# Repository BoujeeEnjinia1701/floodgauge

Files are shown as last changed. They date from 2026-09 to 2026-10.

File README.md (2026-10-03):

# FloodGauge

     

**Area:** Smart Cities · **TRL:** 3 of 9 (proof of concept on paper) · **Value-engineering target:** USD 160 for FloodGauge-specific parts; estimated cost of the constructable design USD 205.50 (FieldNode costed separately) · **Difficulty:** 2 of 5

A street and drain water level sensor using ultrasonic or radar ranging that publishes levels to a city's alert service, so crews and residents can be warned when drains back up or streets begin to flood.

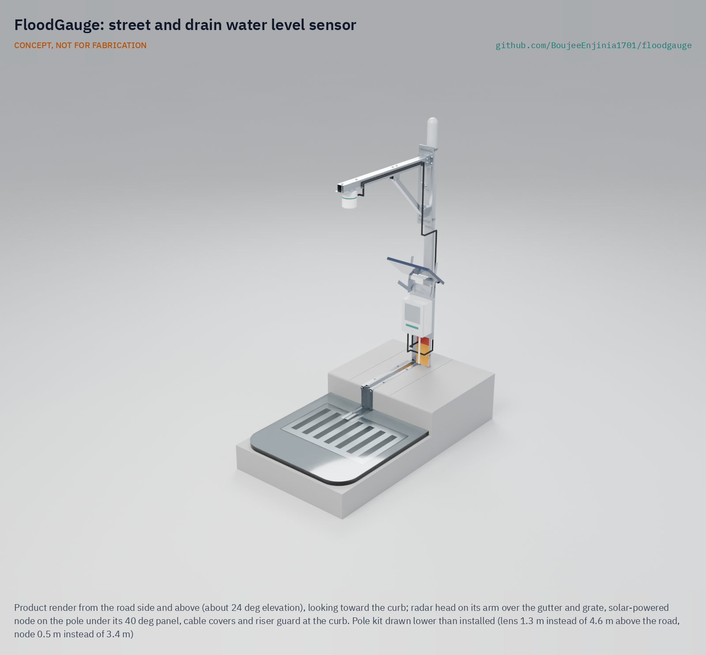
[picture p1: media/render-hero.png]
FloodGauge: street and drain water level sensor, product render


[Exploded render](media/render-exploded.png) · [Detail render](media/render-detail.png) · [Interactive 3D model](media/viewer.html) · [Concept blueprint (PDF)](media/concept-blueprint.pdf) · [General arrangement (PDF)](cad/drawings/FLG-DWG-001.pdf) · [Calculations](docs/04-calcs/01-sizing.md) · [Prototype build plan](docs/05-build-plan.md) · [Design decisions](docs/06-design-decisions.md) · [Review note](docs/REVIEW.md)

## Concept rationale

Street-level readings give minutes of warning where river gauges give none. Streets flood in two ways: the drain fills and backs up through the grate, or the grate is blocked and water ponds above an empty drain. FloodGauge watches both from one pole. A radar head on a short arm over the gutter measures water depth on the street, and an ultrasonic head in a stilling tube inside the catch basin sees the drain filling first. The lab's FieldNode core supplies the enclosure, solar power and LoRaWAN radio, so this project adds only the heads, the mounting and the alert logic.

Keeping it open and garage-buildable lets a city, a university or a neighborhood group build, inspect and repair its own gauges and own its data. The parts are off the shelf or cut with hand tools, the designs are under CERN-OHL-S-2.0 and the software under MIT, and the gauge sends water levels only: no camera, no microphone.

## Burning platform

About 1.81 billion people, 23 % of the world's population, are directly exposed to 1-in-100-year floods, and 89 % of them live in low- and middle-income countries ([Rentschler, Salhab and Jafino, 2022](https://www.nature.com/articles/s41467-022-30727-4)). Only 108 countries, 55 % of the total, reported multi-hazard early warning systems in 2024, and countries with limited coverage had disaster mortality nearly six times higher than those with substantial coverage ([UNDRR and WMO, 2024](https://www.undrr.org/reports/global-status-MHEWS-2024)).

Depths that look harmless kill. The US National Weather Service warns that 150 mm (6 in) of fast-moving water can knock over an adult and 300 mm (12 in) can carry away most cars, and that over half of flood drownings happen when a vehicle is driven into flood water ([NWS](https://www.weather.gov/safety/flood-turn-around-dont-drown)). Those depths build up on a street in minutes, well before a river gauge downstream responds.

## Where it could be used

### By industry

| Industry | Use |
| --- | --- |
| Municipal drainage and public works | Find blocked or surcharging inlets during a storm and send crews to the right street |
| Emergency management | Street depth and rate of rise to close underpasses and warn basement residents |
| Road and transit operators | Flooding alerts at underpasses, bus stops and depot entrances |
| Property and campus management | Early warning for car parks, loading docks and basement entrances |
| Insurance and resilience planning | An open record of where and how often streets flood |
| Research and education | Open, repeatable urban hydrology data for universities and schools |

### By country or region

| Country or region | Why it matters there |
| --- | --- |
| United States | Over half of flood drownings involve vehicles driven into water ([NWS](https://www.weather.gov/safety/flood-turn-around-dont-drown)); New York City's FloodNet reached 250 street sensors in 2024 ([FloodNet](https://www.floodnet.nyc/about)), showing demand for street-level data. |
| Netherlands | The highest share of population in flood zones worldwide, 58.7 % ([Rentschler et al., 2022](https://www.nature.com/articles/s41467-022-30727-4)); dense cities need drain-level data as well as dikes. |
| Germany and Belgium | The July 2021 floods caused more than 200 deaths after record rainfall ([Copernicus, 2021](https://climate.copernicus.eu/esotc/2021/flooding-july)). |
| India and China | Together about 785 million flood-exposed people, over one third of the global total ([Rentschler et al., 2022](https://www.nature.com/articles/s41467-022-30727-4)), many in fast-growing cities. |
| Vietnam | 46 % of the population lives in flood zones, the highest share among developing countries ([Rentschler et al., 2022](https://www.nature.com/articles/s41467-022-30727-4)). |
| Sub-Saharan Africa | 44 % of the 170 million people facing both high flood risk and extreme poverty live here ([Rentschler et al., 2022](https://www.nature.com/articles/s41467-022-30727-4)); low-cost open gauges suit city budgets. |

## What sparked the idea

The idea traces back to the night of September 1, 2021, when the remnants of Hurricane Ida hit New York City. The city's sewers are designed to carry 44 mm (1.75 in) of rain an hour, and Ida brought more than two hours above that rate ([NYC Comptroller, 2024](https://comptroller.nyc.gov/reports/is-new-york-city-ready-for-rain/)). Drains backed up into streets and basements. Of the 14 injury deaths in the city, 10 were drownings in basement apartments, and the deaths for which a time is known came before the state of emergency was declared, and that declaration carried no basement-specific advice ([Yuan et al., 2024](https://www.cambridge.org/core/journals/disaster-medicine-and-public-health-preparedness/article/immediate-injury-deaths-related-to-the-remnants-from-hurricane-ida-i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)). The warning that mattered on that street was the drain filling and the water rising at the curb, and that is what FloodGauge measures.

## Problem

Urban flash floods rise in minutes, and warnings rely on river gauges far from the streets that flood.

## Concept

A street and drain water level sensor using ultrasonic or radar ranging that publishes levels to a city's alert service, so crews and residents can be warned when drains back up or streets begin to flood.

Full design precis: [docs/02-concept.md](docs/02-concept.md)

## Key components

- FieldNode core (enclosure, 6 W solar panel, LiFePO4 cell, LoRaWAN radio), shared with other lab projects
- Street head: 60 GHz radar on a short braced arm over the gutter, lens 2.5 to 5.0 m above the road as the site's clearance rule requires (4.6 m in the reference design), on a pole bracket with two V-blocks, two band clamps and an anti-rotation through-bolt
- Drain head: waterproof ultrasonic ranger with wet probe and temperature sensor, in a slotted 75 mm stilling tube inside the catch basin
- Surface cable route for pilots under three bolted steel covers and a riser guard (conduit at permanent sites), depth marker plate with 150 mm and 300 mm bands
- Open alert service on a LoRaWAN gateway such as TwinKit

TRL 3 calculations ([FLG-CAL-001](docs/04-calcs/01-sizing.md)) on the constructable design: alert latency 82 s at the 95th percentile (110 s worst case), street depth error ±6.5 mm with radar, drain level error ±11 mm, under 10 mW of sensor load and 4.99 kg on the pole. Value-engineering target: USD 160. Estimated cost of the constructable design: USD 205.50 for FloodGauge-specific parts (USD 45.50 over the target); USD 344.50 with the USD 139 FieldNode core. No requirement is not met; installation takes 120 min on the pilot surface route, which is the target Amish set for it. See the [design precis](docs/02-concept.md) and [requirements](docs/03-requirements.md). The design choices were decided by Amish on 2026-09-25 ([FLG-DDR-001](docs/decisions/0001-trl2-review-decisions.md), [FLG-DDR-002](docs/decisions/0002-recommendations-accepted.md)); the changes that make the design buildable are in [FLG-DDR-003](docs/decisions/0003-design-for-construction.md), accepted by Amish on 2026-10-02.

The working bill of materials is in [bom/bom.csv](bom/bom.csv).

## Building the prototype

The [prototype build plan](docs/05-build-plan.md) (FLG-BLD-001) shows how to make and fit every component, in order, with a making sketch for each made part, close-ups of the joints and a picture for every assembly step. Sixteen parts are made in a small workshop from aluminium plate, bar, angle and tube, folded galvanized strip and slotted PVC pipe; the rest are bought or built to the FieldNode plan. The design was checked for construction on the model (110 checks), which changed the arm mounting, the brace, the cable covers and the drain head fixing ([FLG-DDR-003](docs/decisions/0003-design-for-construction.md)). Decisions still open are in the [design decisions register](docs/06-design-decisions.md). It is a plan, not yet built.

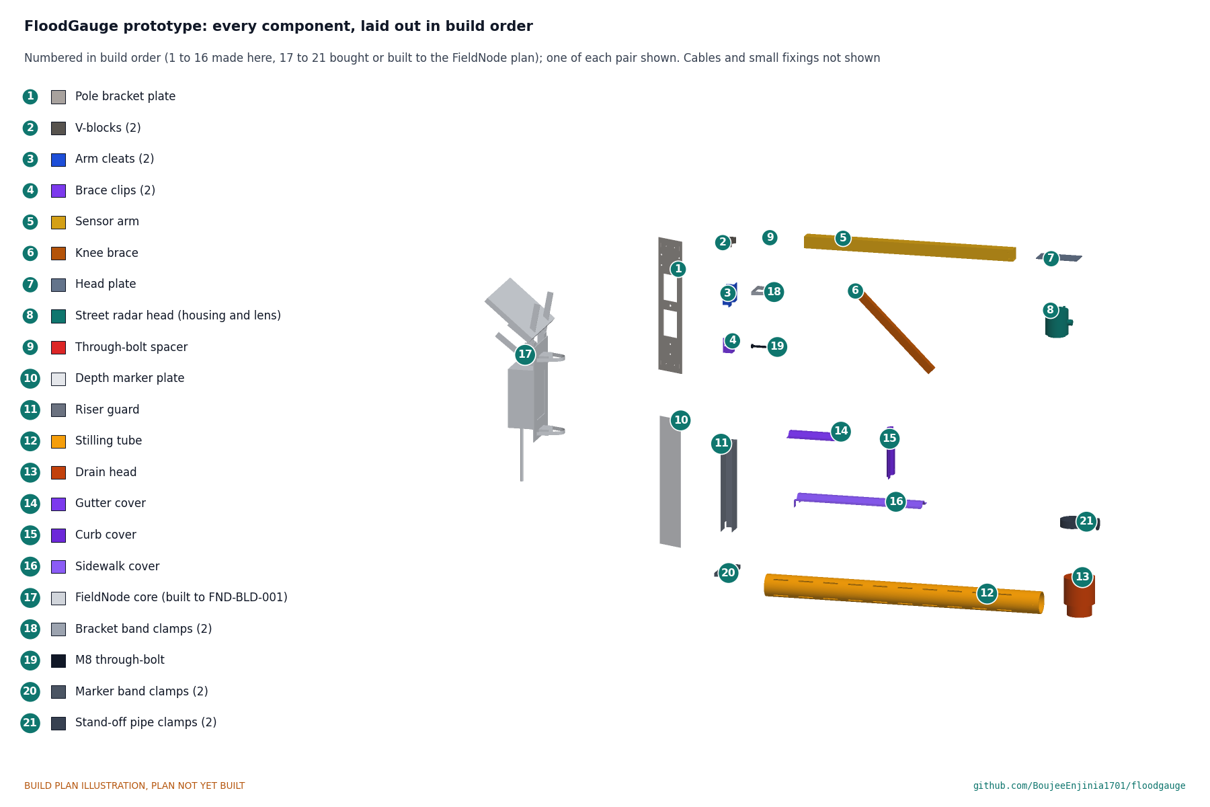
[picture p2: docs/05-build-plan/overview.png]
FloodGauge prototype: every component, laid out in build order


## Safety

> Install only with traffic and confined space precautions. Street furniture and pole mounts must be installed only with the asset owner's permission, by trained crews, with fall protection and traffic management as local rules require.
>
> Never enter a catch basin: it can hold toxic or oxygen-poor air and fast-rising water. Stormwater carries sewage and chemicals; wear gloves and eye protection. The FieldNode LiFePO4 cell must be fused and charged only between 0 and 45 °C.
>
> An arm over the gutter must clear tall vehicles at the curb; mount it at the height the road authority requires (4.6 m in the reference design), from a mobile elevating platform, and always fit the anti-rotation bolt. Keep the surface cable cover low, beveled and marked so it is not a trip hazard.
>
> FloodGauge supplements official flood warnings and must never be the only warning people rely on.

## Repository layout

| Folder | Contents |
| --- | --- |
| `docs/` | Problem, concept, requirements, calculations and design decisions |
| `cad/src/` | build123d Python source, the source of truth for all geometry |
| `cad/step/`, `cad/stl/` | Exported models for FreeCAD, other CAD tools and printing |
| `cad/drawings/` | 2D sketches and dimensioned drawings |
| `bom/` | Bill of materials |
| `electronics/` | KiCad schematics and PCB layouts |
| `firmware/` | Microcontroller code |
| `media/` | Renders, perspectives and photos |
| `build-log/` | Dated prototyping notes |

## Documentation

Controlled documents follow the portfolio [documentation standard](.kit/STANDARDS.md). Each carries a document ID (FLG-PRC-001 for the precis), a version and a revision history. Branded PDFs are built with `python .kit/render.py` and attached to GitHub Releases when a document is tagged, for example `FLG-PRC-001/v1.0`.

## Credits

Designed by Amish Chadha. See [CONTRIBUTORS.md](CONTRIBUTORS.md) for roles. To cite this design, use [CITATION.cff](CITATION.cff) (GitHub shows it as "Cite this repository").

AI assistance (Claude) was used to accelerate concept renders, prototype documentation and first-pass sizing calculations. Design direction and all decisions are Amish Chadha's, recorded in this repository's decision records (`docs/decisions/`).

## Licenses

- **Hardware** (CAD, drawings, BOM, electronics): [CERN-OHL-S v2](LICENSE)
- **Software** (firmware, scripts, notebooks): [MIT](LICENSE-SOFTWARE)

A project of the [Design Molecule](https://designmolecule.com) lab.

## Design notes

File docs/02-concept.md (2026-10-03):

---
doc_id: FLG-PRC-001
title: FloodGauge design precis
project: FloodGauge
doc_type: Design precis
version: "0.8"
status: Draft
date: '2026-10-02'
author: Amish Chadha
license: CERN-OHL-S-2.0
revisions:
- version: "0.1"
  date: '2026-09-25'
  author: Amish Chadha
  change: Initial scaffold
- version: "0.2"
  date: '2026-09-25'
  author: Amish Chadha
  change: Populate to TRL 2 (architecture, first-order numbers, safety, media)
- version: "0.3"
  date: '2026-09-25'
  author: Amish Chadha
  change: TRL 3 update; design choices adopted for TRL 3 pending Amish's review (FLG-DDR-001); numbers checked in FLG-CAL-001; parametric model and drawing FLG-DWG-001
- version: "0.4"
  date: '2026-09-25'
  author: Amish Chadha
  change: Recommendations accepted by Amish (DDR-002)
- version: "0.5"
  date: '2026-09-26'
  author: Amish Chadha
  change: Budget approved by Amish ($160)
- version: "0.6"
  date: '2026-10-01'
  author: Amish Chadha
  change: Constructable design (FLG-DDR-003); budget reported as a value-engineering target
- version: "0.7"
  date: '2026-10-02'
  author: Amish Chadha
  change: "Decisions of 2026-10-02: alert governance with the partner city, first alert band 100 mm, R12 met on paper for the pilot route, tamper-resistant fixings, first candidate partner type"
- version: "0.8"
  date: '2026-10-02'
  author: Amish Chadha
  change: "Cost USD 205.50 (USD 45.50 over the target) with tamper-resistant fixings; drain cable slack loop tied to the stilling tube clamp"
---

# FloodGauge design precis

## Summary

FloodGauge is a FieldNode core on an existing street pole next to a storm inlet, with two ranging heads: a 60 GHz radar head on a short arm over the gutter that measures water depth on the street, and an ultrasonic head in a slotted stilling tube inside the catch basin that sees the drain filling before the street floods. The node turns ranges into levels, raises its sampling rate when water rises, and sends levels only over LoRaWAN to the partner city's alert service, which decides who acts and warns crews and the residents who opt in, at default depths of 150 mm and 300 mm. FLG-CAL-001 v0.4 gives an alert latency of 82 s at the 95th percentile (110 s worst case), a sensor load under 10 mW and 4.99 kg on the pole. Value-engineering target: USD 160 (set by Amish on 2026-09-26). Estimated cost of the constructable design: USD 205.50 for FloodGauge-specific parts (USD 45.50 over the target); USD 344.50 with the USD 139.00 FieldNode core, which is costed in its own repo. One requirement is not met: installation takes 120 min against 90 min (R12). The design choices below were decided by Amish on 2026-09-25 (FLG-DDR-001 and FLG-DDR-002): the lens sits at 4.6 m to clear tall vehicles, pilots use a surface cable route under bolted steel covers, and an M8 through-bolt stops the arm turning. FLG-DDR-003 (2026-10-01, accepted by Amish on 2026-10-02) makes the design buildable: the arm sits in cleats on a pole bracket with V-blocks and band clamps, the brace is pinned in two clips, the FieldNode sits at 3.4 m, and the drain cable comes up through a grate opening under three hat-section covers. The build plan is FLG-BLD-001.

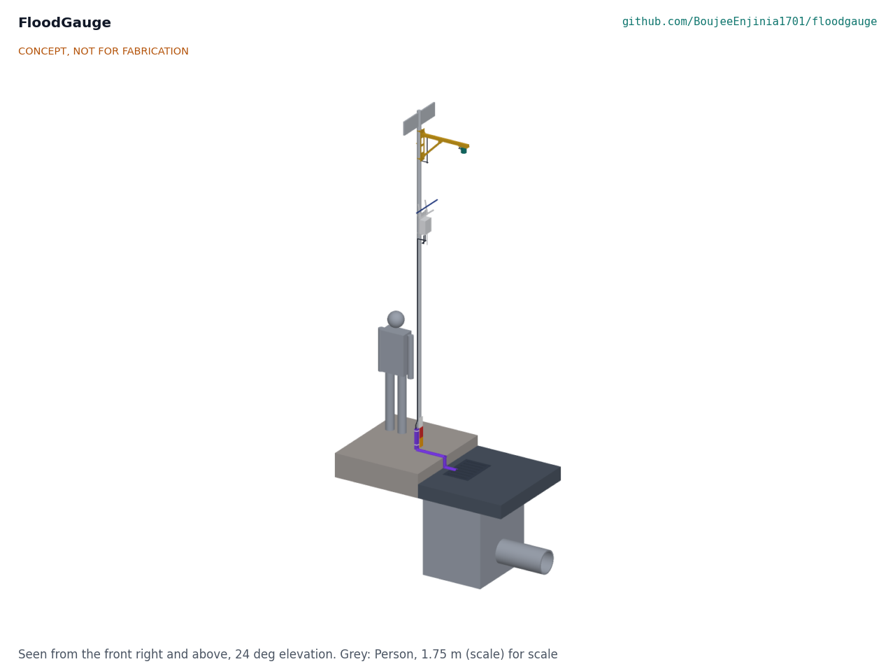
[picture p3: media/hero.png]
Hero render


Figure 1. Concept massing model beside a storm inlet, with a 1.75 m person for scale. CONCEPT, NOT FOR FABRICATION.

## How it works

1. **Range the street.** The street head (item 2) looks straight down at the gutter from 4.6 m, 250 mm past the curb face. The height is set per site within 2.5 to 5.0 m to the road authority's clearance rule; 4.6 m clears a 4.3 m vehicle at the curb with a 0.3 m margin. Water depth is the surveyed head height minus the measured range. The beam also lights the curb, so a dry-road background is recorded at installation and the firmware tracks the peak directly below the head (FLG-CAL-001, A2).
2. **Range the drain.** The drain head (item 4) sits at the top of a slotted 75 mm tube (item 5) fixed to the basin wall. Water in the tube follows the basin level (lag under 5 mm even at 50 mm/s), and the tube walls give the wide ultrasonic beam a clean path, so the head sees the water surface and not the basin walls. A wet probe on the head signals when the basin is full to the head, and an NTC in the head compensates the speed of sound.
3. **Decide on the node.** FieldNode (item 1), mounted 3.4 m above the road so that the street head's I2C cable stays within 3 m along its real route (FLG-DDR-003), samples both heads every 60 s. When either level rises faster than 20 mm/min or passes the first band, it samples every 10 s. It applies plausibility checks: a sudden 1 m "rise" on the street head with an empty drain is a parked vehicle or a person, not a flood.
4. **Report.** Normally one uplink every 15 min; in an event an uplink on each band crossing and then each minute. Payloads carry levels, rate of rise, battery and status only.
5. **Alert.** A gateway (TwinKit or a city LoRaWAN network) passes readings to an open alert service that sends crew notifications and opt-in resident messages and publishes open data.
6. **Check by eye.** A depth marker plate (item 8) with bands at 150 and 300 mm above the road lets residents and crews read depth directly and check the gauge. The alert service adds a first band at 100 mm unless the partner city's own practice says otherwise.

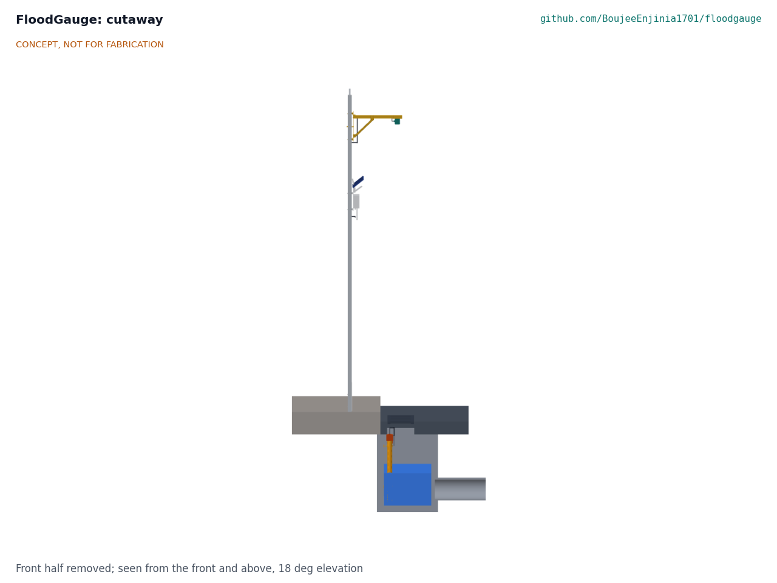
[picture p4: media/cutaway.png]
Cutaway


Figure 2. Section across the street through the inlet: street head over the gutter, stilling tube and drain head in the catch basin, surface cable cover to the pole. Water level is illustrative.

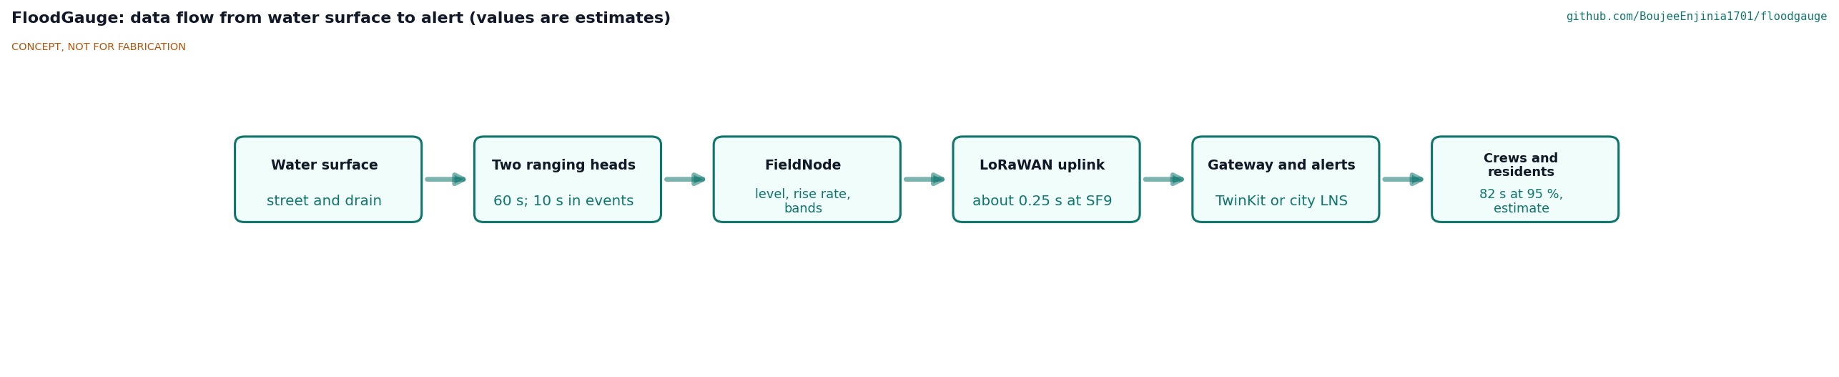
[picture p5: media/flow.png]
Data flow


Figure 3. Data flow from the water surface to an alert. Values are estimates or proposals.

## Main components

Table 1. Main components (numbers match the exploded view and `bom/bom.csv`)

| # | Component | Decided choice (FLG-DDR-001, FLG-DDR-002) | Notes |
| --- | --- | --- | --- |
| 1 | FieldNode core | Lab shared node: IP65 enclosure, 6 W panel as hood, 6 Ah LiFePO4 cell, MPPT board with 3.3, 5 and 12 V switched rails, STM32WL-class LoRaWAN, two M12 sensor ports | Built to FND-BLD-001; center 3.4 m above the road, facing the street; 2.45 kg and $139.00 |
| 2 | Street radar head | 60 GHz pulsed coherent radar module (Acconeer XM125 class) behind a PTFE lens in a sealed IP67 housing | D3; accuracy, current and price not yet checked against a data sheet |
| 3 | Sensor arm and pole bracket | 40 x 40 x 1.6 mm aluminium tube 715 mm in two angle cleats on a 3 mm pole bracket plate with two V-blocks and two band clamps 400 mm apart; 25 mm square knee brace at 45° pinned in two clips; head plate; M8 anti-rotation through-bolt across the street through the plate and the pole | Head 250 mm past the curb face over the gutter (D5); lens 4.6 m, per site 2.5 to 5.0 m (DDR-002) |
| 4 | Drain head | Waterproof ultrasonic ranger (A02YYUW: 3 to 450 cm, ±1 cm, IP67) with a two-electrode wet probe and an NTC, potted in a sealed cap | Face 300 mm below the road; the transducer face keeps its IP67 seal, so R9 is at risk |
| 5 | Stilling tube | 75 mm OD PVC, 940 mm long, 40 slots 5 x 50 mm, two stainless stand-off pipe clamps, mouth 60 mm above the basin floor; the drain head's socket slides over its top | Reachable from the surface with the grate lifted; the drain cable has a 0.5 m slack loop tied to the upper pipe clamp so it cannot catch debris |
| 6 | Sensor cables | Two outdoor cables with M12 5-pin plugs to the FieldNode ports: 3 m (street, I2C) and 5 m (drain) | Drip loops at every entry |
| 7 | Surface cable covers | Pilot route: up through the grate opening nearest the curb, under three bolted hat-section covers of 2 mm galvanized steel (gutter strip, curb face, sidewalk; 0.76 m in all) and up a riser guard strapped to the pole | Anchors in the curb and sidewalk only, with security (snake-eye) nuts; permanent sites use a 25 mm conduit laid with road works (DDR-002) |
| 8 | Depth marker plate | 2 mm aluminium plate from 165 mm above the road, amber band to 300 mm and red band 300 to 450 mm above road level, on two band clamps with pin-Torx security screws that also hold the riser guard | Visual check and resident information |
| 9 | Alert service | Open software on the gateway or a small server (not modeled) | Part of the software license (MIT) |

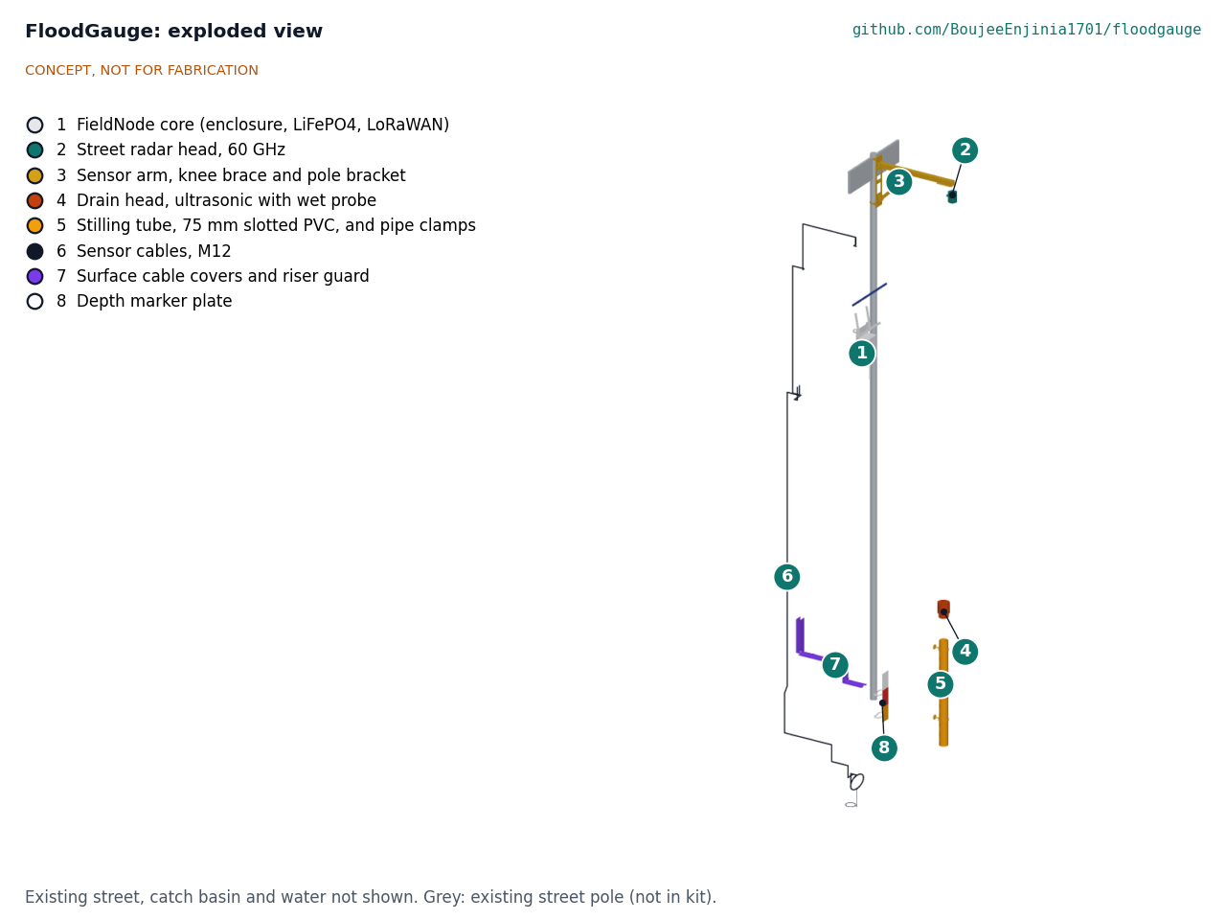
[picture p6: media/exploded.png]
Exploded view


Figure 4. Exploded view with BOM numbers. The existing street and basin are not shown.

## First-order numbers

The values below are from FLG-CAL-001 v0.4 and its script, on the constructable design of FLG-DDR-003.

Table 2. Key numbers at TRL 3

| Quantity | Value | Basis | Requirement |
| --- | --- | --- | --- |
| Street head range | 4.60 m to dry road, 4.00 m at 600 mm depth; 1.9 to 5.0 m over the R1 band | Lens 4.6 m above the road | R1 met on paper |
| Street depth error, radar | ±6.5 mm root sum square, ±12.0 mm worst-case sum | Module ±2 mm (assumed), datum ±5 mm, pole expansion ±2.0 mm, ripple ±3 mm | R2 met on paper |
| Street depth error, ultrasonic variant | +349 to -231 mm uncompensated over -20 to 50 °C; ±27.0 mm compensated | Speed of sound 331.3 + 0.606 T m/s | R2 not met by this variant |
| Drain level error | ±11.0 mm with the NTC, ±19.7 mm without | ±10 mm module ([DFRobot](https://www.dfrobot.com/product-1935.html)), 950 mm range | R4 met on paper |
| Drain reading range | 50 mm above the floor to 330 mm below the road; wet probe at 310 mm | Head face 300 mm below the road, 30 mm blind zone | R3 (restated) met on paper |
| Energy per sampling cycle | 85.1 mJ | Radar 59.4 mJ, ultrasonic 12.0 mJ, rails 90 %, controller 5.8 mJ | |
| Sensor load | 1.42 mW at 60 s; 9.3 mW with 10 s sampling and 1 min uplinks all day | 1,440 or 8,640 cycles a day | R8 met: 68 days without sun |
| Uplink airtime | 23.7 s/day normal at SF9; 14.8 s/h in an event | 246.8 ms per 20-byte uplink | R7 at risk at SF11 and SF12 |
| Alert latency | 82 s at the 95th percentile, 110 s worst case without a lost packet | Simulation of 200,000 events | R6 met on paper |
| Arm twist | Factor 37 with the M8 through-bolt; 1.45 on clamp friction alone | 35 m/s gust along the street | R15 met on paper |
| Installation | 120 min, surface only, no civil work | Task list in FLG-CAL-001, L1 | R12 met on paper (120 min for the pilot route) |
| Mass on the pole | 4.99 kg | FieldNode 2.45 kg plus arm, bracket, bolts, head, cables and marker (FLG-CAL-001 v0.4) | R15 met on paper (0.01 kg margin) |
| Parts cost | $205.50 FloodGauge-specific; $344.50 with FieldNode | `bom/bom.csv` | R16: value-engineering target USD 160; estimated cost of the constructable design USD 205.50 (USD 45.50 over the target) |

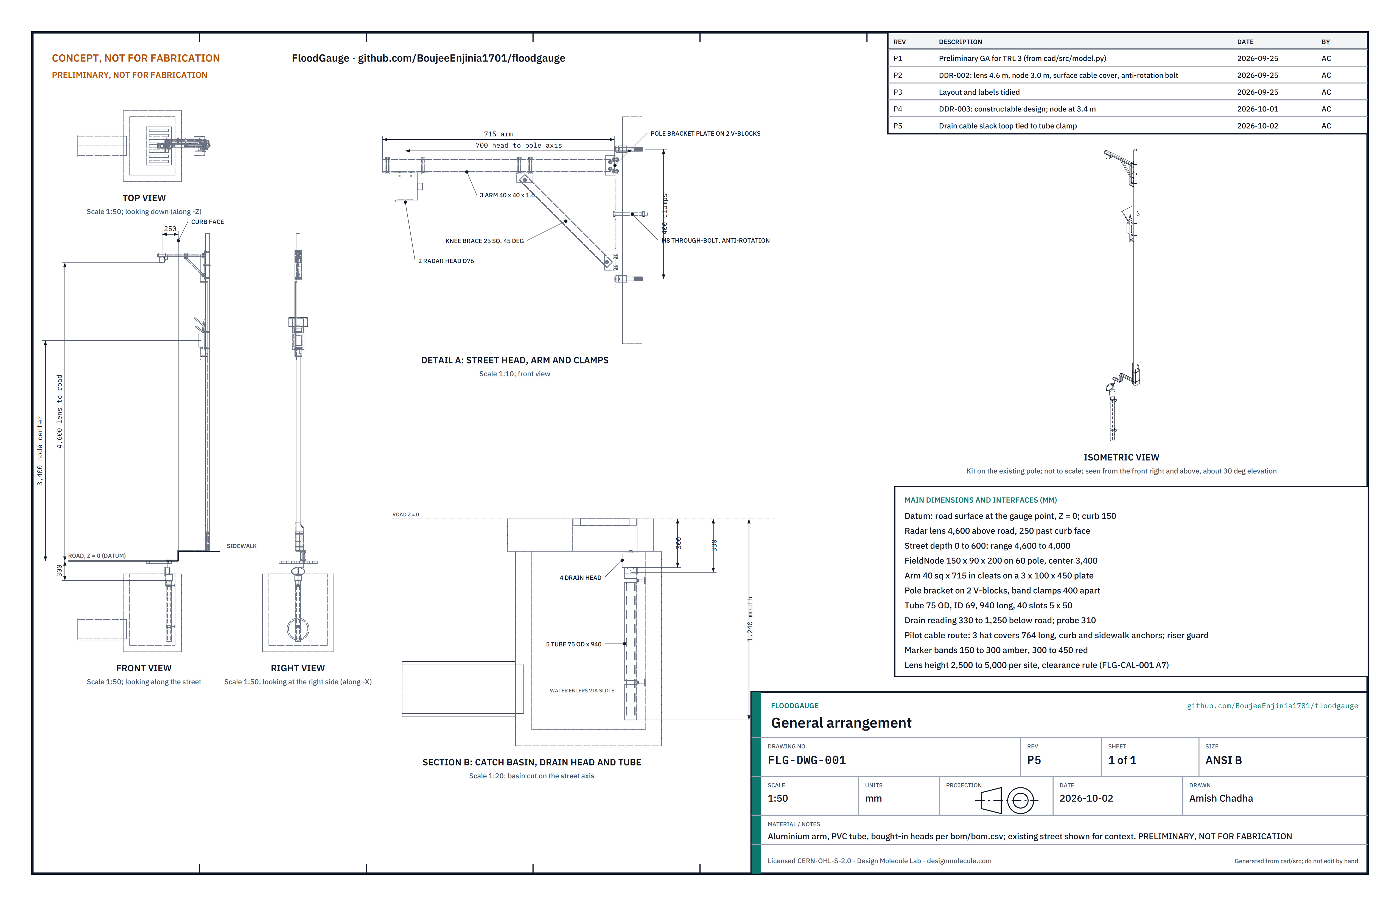
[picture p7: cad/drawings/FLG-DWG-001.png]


Figure 5. General arrangement FLG-DWG-001, Rev P4, from `cad/src/model.py`. PRELIMINARY, NOT FOR FABRICATION.

## Key design choices

Decided by Amish, 2026-09-25: go with recommendation (FLG-DDR-001, D1 to D9, and FLG-DDR-002, N1 to N5).

1. **Two heads on one node** (street and drain), because each head misses one of the two ways streets flood (FLG-PRB-001). Street head only remains the fallback where no cable route to the basin exists. (D2)
2. **Radar for the street head.** FLG-CAL-001 confirms that a compensated ultrasonic head misses R2 (±19.5 mm). The ultrasonic head stays documented as a lower-cost variant. (D3)
3. **Ultrasonic in a stilling tube for the drain,** with the wet probe as a second signal and an NTC for temperature. (D4)
4. **Arm over the gutter,** lens height set per site within 2.5 to 5.0 m to the road authority's clearance rule; 4.6 m in the reference design, where tall vehicles use the curb lane. The arm carries an M8 through-bolt so wind cannot turn it. (D5; DDR-002 N2 and N4)
5. **Alert bands at 150 mm and 300 mm** above the road ([NWS](https://www.weather.gov/safety/flood-turn-around-dont-drown)), plus a drain-full alert from the wet probe, as defaults to be set with the partner city. In a fast flood the 150 mm band warns at about 190 to 250 mm (FLG-CAL-001, F3), so the alert service also supports a first band below 150 mm, set at 100 mm unless the partner's own practice says otherwise (decided 2026-10-02). (D6; DDR-002 N5)
6. **Private or city LoRaWAN gateway for event reporting** (TwinKit or the city network), with The Things Network for pilots only. (D7)
7. **Levels only, no imaging.** (D8)
8. **Surface cable route for pilots,** under a bolted steel cover anchored to the curb and sidewalk, with the conduit kept for permanent sites laid with road works. (DDR-002 N3)

The FieldNode core is costed in its own repo, and R16 covers FloodGauge-specific parts only (D1). The pitch and problem lines are unchanged (D9).

## Safety

> **Safety:** Work beside live traffic. Install only with the road and pole owner's permission, with traffic management and high-visibility clothing as local rules require.
>
> **Safety:** Catch basins are confined spaces that can hold toxic or oxygen-poor air and fast-rising water. The design is installed from the surface; never enter a basin. Lifting a grate can crush fingers and strain backs; use a grate hook and two people. Stormwater carries sewage and chemicals: wear gloves and eye protection and wash after work.
>
> **Safety:** Work at height on the pole needs a mobile elevating platform for the arm at 4.7 m, a second person and clearance from overhead power lines. Drilling the pole for the anti-rotation bolt needs the asset owner's permission.
>
> **Safety:** An arm over the gutter can be struck by trucks, buses or their mirrors at the curb if it is too low (FLG-CAL-001, A7). Mount it at the height the road authority requires (4.6 m in the reference design) and always fit the anti-rotation through-bolt so that wind cannot swing it over the traffic lane.
>
> **Safety:** The surface cable cover crosses the sidewalk. Keep it low and beveled, anchor it firmly and mark it so that it is not a trip hazard.
>
> **Safety:** FieldNode holds a LiFePO4 cell of about 19 Wh. Fuse it, charge only between 0 and 45 °C, and never install a swollen, damaged or wet cell.
>
> **Safety:** FloodGauge supplements official warnings and must never be presented as the only warning. A dead battery, a blocked tube or a lost radio link can hide a flood. The alert service must report when a gauge goes silent. The partner city's emergency management office owns the alerts and decides who acts; FloodGauge publishes levels and band crossings only and holds no resident contact data.

## Open questions

- [ ] Radar module accuracy, current draw, beam width with the lens, price and radio certification for fixed outdoor use at 60 GHz in the pilot country (assumed in FLG-CAL-001).
- [x] Pilot partner: a city or county flood agency with street flooding at grated curb inlets and an existing gauge or alert programme; the first candidate type to approach is a county flood control district such as the Harris County Flood Control District (decided 2026-10-02; nothing agreed).
- [ ] Whether the surface cable cover survives street cleaning, snow ploughs and parked-car wheels at the curb.
- [ ] Silt and debris in the stilling tube: slot size, cleaning interval, and whether the tube clogs in the first storm.
- [ ] Plausibility logic for vehicles, people, snow and floating debris under the street head.
- [x] Theft and vandalism: tamper-resistant screw heads and nuts on everything within reach of the sidewalk (marker bands, covers, riser guard and anchors) for the pilot; the node stays at 3.4 m (decided 2026-10-02).
- [x] Alert governance: the partner city's emergency management office owns the alerts; FloodGauge publishes levels and band crossings only, the city decides who acts, and residents opt in and out through the city's existing alert channel, so the project holds no resident contact data (decided 2026-10-02).
- [ ] Datum survey method and how often to recheck it.

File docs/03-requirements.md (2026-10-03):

---
doc_id: FLG-REQ-001
title: FloodGauge requirements
project: FloodGauge
doc_type: Requirements
version: "0.8"
status: Draft
date: '2026-10-02'
author: Amish Chadha
license: CERN-OHL-S-2.0
revisions:
- version: "0.1"
  date: '2026-09-25'
  author: Amish Chadha
  change: Initial scaffold
- version: "0.2"
  date: '2026-09-25'
  author: Amish Chadha
  change: First measurable requirements for TRL 2, with status against the concept
- version: "0.3"
  date: '2026-09-25'
  author: Amish Chadha
  change: TRL 3 status from FLG-CAL-001; R16 restated to FloodGauge-specific parts under FLG-DDR-001 D1
- version: "0.4"
  date: '2026-09-25'
  author: Amish Chadha
  change: Recommendations accepted by Amish (DDR-002)
- version: "0.5"
  date: '2026-09-26'
  author: Amish Chadha
  change: Budget approved by Amish
- version: "0.6"
  date: '2026-10-01'
  author: Amish Chadha
  change: Status from FLG-CAL-001 v0.4 (constructable design, FLG-DDR-003); R16 reported against the value-engineering target
- version: "0.7"
  date: '2026-10-02'
  author: Amish Chadha
  change: "R12 relaxed to 120 min for the pilot surface route (90 min at permanent sites), now met on paper; R15 fix named; first alert band 100 mm (decisions of 2026-10-02)"
- version: "0.8"
  date: '2026-10-02'
  author: Amish Chadha
  change: "Status from FLG-CAL-001 v0.6 (sizing.py rerun); R16 cost USD 205.50 with the tamper-resistant fixings priced"
---

# FloodGauge requirements

These requirements are checked by calculation in FLG-CAL-001 v0.6, on the constructable design of FLG-DDR-003. The design choices behind them were decided by Amish on 2026-09-25 (FLG-DDR-001 and FLG-DDR-002). Three targets have changed at TRL 3: R16 covers FloodGauge-specific parts only, with the FieldNode core costed in its own repo (DDR-001 D1); R1 allows a mounting height of 2.5 to 5.0 m, set per site to the road authority's clearance rule; and R3 is restated to the reach of the drain head plus a drain-full signal (both DDR-002). On 2026-10-02 Amish relaxed R12 to 120 min for the pilot surface route, keeping 90 min for permanent sites (FLG-DEC-001, item 5). On 2026-09-26 Amish set `budget_usd` to $160 (DDR-002); on 2026-10-01 he described budgets as hypothetical value-engineering targets, so R16 is reported over or under the $160 target rather than as met or not met. The status column states "not met" plainly.

Table 1. Requirements and status at TRL 3

| ID | Requirement | Target | Verification (TRL 3 or later) | Status (FLG-CAL-001) |
| --- | --- | --- | --- | --- |
| R1 | Measure water depth on the street at the gauge point | 0 to 600 mm above the road surface, head mounted 2.5 to 5.0 m above the road at the height the road authority's clearance rule sets for the site | Range calculation against sensor data | Met on paper: reference lens at 4.6 m clears a 4.3 m vehicle; range 1.9 to 5.0 m over the band, radar to 20 m |
| R2 | Street depth accuracy | ±10 mm over -20 to 50 °C air, still water | Error budget; later bench test over a tank | Met on paper with radar: ±6.5 mm root sum square (±12.0 mm worst-case sum), module accuracy assumed. **Not met** by the ultrasonic variant (±27.0 mm compensated at 4.6 m) |
| R3 | Measure water level in the catch basin | Continuous reading from 50 mm above the basin floor to 330 mm below the road, plus a drain-full signal above that | Geometry of stilling tube and head | Met on paper: continuous from 1,250 to 330 mm below the road; wet probe trips at 310 mm |
| R4 | Drain level accuracy | ±20 mm | Error budget | Met on paper: ±11.0 mm with the NTC in the head (±19.7 mm without) |
| R5 | Sampling rate | Every 60 s normally; every 10 s when level is above the first alert band or rising faster than 20 mm/min | Sampling logic review | Met by design |
| R6 | Alert latency | 120 s or less from threshold crossing to message at the alert service, 95 % of events | Latency budget | Met on paper: 82 s at the 95th percentile on a private gateway (85 s on a city server); 110 s worst case without a lost packet |
| R7 | Radio airtime within network rules | Within EU868 1 % duty cycle always; within The Things Network fair use (30 s uplink airtime per day) in normal mode | Airtime calculation | **At risk:** normal mode 23.7 s/day at SF9; event mode within 1 % at SF7 to SF10 but not at SF11 or SF12 unless reporting stretches to 99 s or 181 s; normal mode exceeds fair use at SF10 and slower |
| R8 | Energy autonomy | 5 days without sun at event-mode sampling | Power budget against FieldNode | Met on paper: 68 days nominal, 47 days at -20 °C; 9.3 % of the FieldNode 100 mW allowance |
| R9 | Survive submersion of the drain head | IP68, 2 m, 72 h, stormwater with silt | Enclosure design review; later immersion test | **At risk:** electronics potted, but the transducer face keeps the module's IP67 seal |
| R10 | Reject false readings | No alert caused by a vehicle, person or debris under the street head; target 1 false alert per gauge per year or fewer | Plausibility logic review; later field log | Not verifiable at TRL 3: rules defined, including a recorded dry-road background against the curb echo |
| R11 | Privacy | Levels, status and battery only; no camera or microphone; no images or audio leave the device | Design review | Met by design |
| R12 | Installation | Two-person crew, from the surface; no road drilling; no entry into the catch basin. 120 min or less on the pilot surface cable route (relaxed on 2026-10-02, FLG-DEC-001 item 5); 90 min or less at permanent sites built on the conduit route with road works | Installation sequence review | Met on paper for the pilot route: 120 min, with no civil work (DDR-002) |
| R13 | Level datum | Head height surveyed to the road surface at the gauge point within ±5 mm; checked yearly against the depth marker | Survey method | Met on paper: tape survey plus a recorded dry-road radar reading |
| R14 | Operating environment | -20 to 50 °C air; UV, rain and road spray; FieldNode charges only from 0 to 45 °C | Material and cell review | **At risk:** inherits FieldNode's interior heat finding (FND R2, R3); the drain head module is rated -15 to 60 °C |
| R15 | Mounting | Fits 40 to 60 mm poles with band clamps; total added mass on the pole 5 kg or less | Mass estimate | Met on paper: 4.99 kg (0.01 kg margin); twist factor 37 with the M8 anti-rotation through-bolt (1.45 on friction alone) |
| R16 | Cost | FloodGauge-specific parts $160 or less at quantity 1; FieldNode costed separately (FND-CAL-001) | Priced BOM | Over the value-engineering target by $45.50: $205.50 for the constructable design ($344.50 with the $139.00 FieldNode core) |
| R17 | Open data | Levels published in an open, documented format (JSON or CSV) through the gateway | Design review | Met by design |

## Assumptions

- The road surface at the gauge point is the datum for street depth. Depth equals the surveyed head height minus the measured range.
- "Event" means water above the first alert band or rising faster than 20 mm/min.
- FieldNode figures (usable energy, allowance, airtime per uplink, mass, cost, charge temperature window) come from FND-CAL-001 in the FieldNode repo.
- Alert depths of 150 mm and 300 mm follow NWS guidance on water that can knock over an adult and carry away a car ([NWS](https://www.weather.gov/safety/flood-turn-around-dont-drown)). They are defaults under FLG-DDR-001 D6, to be set locally with the partner city. Under FLG-DDR-002 the alert service also supports a first band below 150 mm; Amish set it at 100 mm on 2026-10-02 unless the partner's own practice says otherwise (FLG-DEC-001, item 6).
- The remaining assumptions for every status above are in FLG-CAL-001, Table 1.

## Requirements not met or at risk

- **R12:** the surface cable route (DDR-002) removes the coring and trenching, but fitting its cover takes the installation to 120 min. Amish relaxed R12 to 120 min for the pilot route on 2026-10-02 (FLG-DEC-001, item 5), so it is met on paper; 90 min stays the target at permanent sites.
- **R7 at risk:** slow spreading factors need a longer event interval; event reporting belongs on a private or city gateway (D7).
- **R9 at risk:** the transducer face seal decides immersion survival.
- **R14 at risk:** interior heat in FieldNode, and the drain module's -15 °C lower rating.
- **R2** would not be met if the ultrasonic street variant were used.
- **R15 thin margin:** 4.99 kg against 5.0 kg on estimated masses after the parts added for construction (FLG-DDR-003); weigh at TRL 4. Decided 2026-10-02 (FLG-DEC-001, item 3): if the weighed mass is over 5.0 kg, the bracket plate goes to 2.5 mm.
- **R16:** the $160 is a value-engineering target (Amish, 2026-10-01), not a limit; the constructable design is estimated at $205.50, $45.50 over it.

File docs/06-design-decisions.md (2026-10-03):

---
doc_id: FLG-DEC-001
title: FloodGauge design decisions register
project: FloodGauge
doc_type: Design decisions register
version: "0.3"
status: Draft
date: '2026-10-02'
author: Amish Chadha
license: CERN-OHL-S-2.0
revisions:
  - version: "0.1"
    date: '2026-10-01'
    author: Amish Chadha
    change: Register opened with the open decisions from REVIEW.md, FLG-DDR-001 to FLG-DDR-003 and the build plan work
  - version: "0.2"
    date: '2026-10-02'
    author: Amish Chadha
    change: "Amish approved the recommendations for all twelve open decisions on 2026-10-02 (FLG-DDR-003 accepted); moved to decisions made"
  - version: "0.3"
    date: '2026-10-02'
    author: Amish Chadha
    change: "Value engineering restated with the priced tamper-resistant fixings (USD 205.50, USD 45.50 over the target)"
---

# FloodGauge design decisions register

Every design decision still to be made, and every decision made, in one place. Each decision is argued in full in its decision record under `docs/decisions/`; this register is the index Amish works from. The build plan (`docs/05-build-plan.md`) describes the design as it stands and does not list open decisions.

## Open decisions

None. All open decisions were decided on 2026-10-02.

## To confirm when parts are bought

| # | What to confirm | Why it matters | Source |
| --- | --- | --- | --- |
| 1 | Radar module data sheet: accuracy, current, beam width with the lens, price and 60 GHz certification for fixed outdoor use in the pilot country | The depth error, energy and false-reading figures assume them | FLG-CAL-001, Table 1 |
| 2 | The radar housing's lid boss pattern and a base that can take a 46 mm window | Sets the four M4 holes in the head plate and the lens fixing | FLG-DDR-003, P4 |
| 3 | The ranger's transducer face seal (IP67 only) and potting compatibility | R9 is at risk on the face seal | FLG-REQ-001, R9 |
| 4 | Band clamps that close on a 60 mm pole with the V-block and plate inside (about 330 to 380 mm round for the bracket and FieldNode, about 450 mm for the marker), and the torque that gives 1,000 N of preload | The twist and pull figures assume 1,000 N per band | FLG-CAL-001, H2 and H4 |
| 5 | The site pole's wall thickness (2.5 mm assumed) and the owner's permission to drill it | Bearing strength of the through-bolt | FLG-CAL-001, H2b |
| 6 | A grate opening within 70 mm of the grate's curb edge on the chosen cover line, and the curb height (150 mm assumed) | The cable comes up through that opening; the curb cover length follows the curb | FLG-DDR-003, P7 and P8 |
| 7 | The 75 mm socket coupling fits the chosen pipe, and the stand-off pipe clamps reach 90 mm from the wall | Sets the drain head fit and the tube position | FLG-DDR-003, P9 and P10 |
| 8 | Outdoor cable mass and diameter (0.07 kg/m, 10 mm assumed) | Mass margin and the fit inside the 16 mm covers | FLG-CAL-001, I1 |

## Value engineering

Value-engineering target: USD 160 (a hypothetical control target, not a limit). Estimated cost of the constructable design: USD 205.50 for the FloodGauge-specific parts (USD 45.50 over the target); USD 344.50 with the USD 139.00 FieldNode core, which is costed in its own repo.

Main cost drivers: the street radar head (USD 55.00), the sensor arm and pole bracket (USD 35.00), the surface covers and riser guard (USD 32.00) and the drain head (USD 24.50).

Savings worth trying:

- Quote the radar module and a housing with the lens window already moulded; the USD 55.00 is unverified and is the largest line.
- Cut the bracket plate, cleats, clips and head plate from one sheet and one angle offcut, and buy band clamps and M6 fixings in packs shared with FieldNode builds.
- Make the riser guard and covers from one 2 mm galvanized strip length, or use a bought steel cable protector for the sidewalk run.
- Use the conduit route (about USD 8 plus civil work, not in this total) at sites where road works are planned anyway.

## Decisions made

| Date | Decision | Decided by | Record |
| --- | --- | --- | --- |
| 2026-09-25 | TRL 2 review items D1 to D9: FieldNode costed in its own repo; street and drain heads on one node; radar street head with ultrasonic as the lower-cost variant; ultrasonic drain head in a slotted stilling tube with a wet probe; arm over the gutter; 150 and 300 mm alert bands plus drain-full; private or city gateway for events; levels only; pitch and problem unchanged | Amish: "i accept all your recommendations, go with them across all repos." | FLG-DDR-001, FLG-DDR-002 |
| 2026-09-25 | TRL 3 items N1 to N5: R3 restated; lens set per site within 2.5 to 5.0 m (4.6 m reference); surface cable route for pilots with conduit at permanent sites; M8 anti-rotation through-bolt; a first alert band below 150 mm supported | Amish, same instruction | FLG-DDR-002 |
| 2026-09-26 | `budget_usd` set to USD 160 | Amish: "i approve all the budget items." | FLG-DDR-002 |
| 2026-10-01 | Budgets are value-engineering targets, not limits; cost is reported over or under the target | Amish: "the budgets are a hypothethical control target to ensure we are thinking along a value engineering lens. its ok to ensure wording reflects that the hypothesis budget was x - the real cost being accrued is y" | STANDARDS section 18 |
| 2026-10-01 | Design for construction, P1 to P11 | Made under Amish's 2026-09-30 instruction to make the design physically buildable ("fix the design assumptions to match and be physically feasible"); accepted on 2026-10-02 (below) | FLG-DDR-003 |
| 2026-10-02 | Design for construction accepted: the changes P1 to P11 of FLG-DDR-003 and their knock-on changes, as made | Amish: "i approve your recommendations for all 555 open decisions." | FLG-DDR-003 |
| 2026-10-02 | Node kept at 3.4 m, so the street cable fits the 3 m I2C limit along its real route | Amish: "i approve your recommendations for all 555 open decisions." | FLG-DDR-003, P6 |
| 2026-10-02 | R15 mass margin of 0.01 kg accepted; the prototype is weighed at TRL 4, and a 2.5 mm bracket plate is the named fix if the weighed mass is over 5.0 kg | Amish: "i approve your recommendations for all 555 open decisions." | FLG-DDR-003, A1 |
| 2026-10-02 | Grate lifting for the pilot: undo the gutter cover's two anchor nuts and lift the grate with the cable threaded and a 0.5 m slack loop in the basin, the loop tied to the stilling tube clamp so it cannot catch debris; reviewed after the first cleaning visit | Amish: "i approve your recommendations for all 555 open decisions." | FLG-DDR-003, A2 |
| 2026-10-02 | R12 relaxed to 120 min for the pilot surface route; 90 min stays the target for permanent sites built on the conduit route with road works | Amish: "i approve your recommendations for all 555 open decisions." | REVIEW.md, 2026-09-25, item 3; FLG-DDR-002, O3 |
| 2026-10-02 | Pilot partner: a city or county flood agency with a known street-flooding problem at grated curb inlets and an existing gauge or alert programme. First candidate type to approach: a county flood control district such as the Harris County Flood Control District in Houston. First alert band at 100 mm unless the partner's own practice says otherwise | Amish: "i approve your recommendations for all 555 open decisions." | FLG-DDR-001, O1; FLG-DDR-002, N5 |
| 2026-10-02 | Render-only layout of the pole kit kept, with the caption; the caption's heights are updated to the 3.4 m node when the renders are redone | Amish: "i approve your recommendations for all 555 open decisions." | REVIEW.md, 2026-09-26, item 1 |
| 2026-10-02 | Drain kit shown in the exploded render only; a basin cutaway render only if the drain head is shown as a product on its own | Amish: "i approve your recommendations for all 555 open decisions." | REVIEW.md, 2026-09-26, item 2 |
| 2026-10-02 | Side gland on the radar head and the street cable route closed as adopted with item 1 (FLG-DDR-003, P5) | Amish: "i approve your recommendations for all 555 open decisions." | REVIEW.md, 2026-09-26, item 3; FLG-DDR-003, P5 |
| 2026-10-02 | Clear lid window, name plate, status light and cover ridges are render detail only; no clear-lid node is raised with FieldNode | Amish: "i approve your recommendations for all 555 open decisions." | REVIEW.md, 2026-09-26, item 4 |
| 2026-10-02 | Alert governance: the partner city's emergency management office owns the alerts. FloodGauge publishes levels and band crossings only, the city decides who acts, and residents opt in and out through the city's existing alert channel, so the project holds no resident contact data | Amish: "i approve your recommendations for all 555 open decisions." | FLG-PRC-001, open questions |
| 2026-10-02 | Tamper-resistant screw heads and nuts on everything within reach of the sidewalk (marker bands, covers, riser guard and anchors) for the pilot; the node stays at 3.4 m as designed | Amish: "i approve your recommendations for all 555 open decisions." | FLG-PRC-001, open questions |

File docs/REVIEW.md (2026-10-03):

# Review note: FloodGauge

## Session 2026-10-02: open decisions decided by Amish

Amish wrote on 2026-10-02: "i approve your recommendations for all 555 open decisions." Every open decision in this repo's register was decided as recommended and moved to "Decisions made" in `docs/06-design-decisions.md`, dated 2026-10-02.

### Decisions recorded

12 decisions recorded (register items 1 to 12). The register's "Open decisions" section now reads: "None. All open decisions were decided on 2026-10-02."

### Documents changed

- `docs/06-design-decisions.md` v0.2
- `docs/decisions/0003-design-for-construction.md` v0.2
- `docs/decisions/0001-trl2-review-decisions.md` v0.3
- `docs/decisions/0002-recommendations-accepted.md` v0.3
- `docs/03-requirements.md` v0.7
- `docs/04-calcs/01-sizing.md` v0.5
- `docs/02-concept.md` v0.7
- `docs/01-problem.md` v0.5
- `docs/05-build-plan.md` v0.2
- `README.md` (pitch and DDR-003 status; not a controlled document)
- `project.yaml` (pitch; not a controlled document)
- `bom/bom-notes.md` (DDR-003 status and tamper-resistant fixings note; not a controlled document)

PDFs re-rendered with `python3 .kit/render.py`. The CAD model, BOM quantities and prices, and pictures were not changed.

### Follow-up actions to carry approved decisions into the design

1. Decision 1 (build plan pictures and renders): Update `cad/src/product_model.py` to the constructable design (pole bracket, cleats, head plate, covers, node at 3.4 m) and regenerate `media/render-*.png`, `media/card.png` and `media/social-preview.png` on Amish's Mac.
2. Decision 4 (model): Model the 0.5 m drain cable slack loop in the basin tied to the stilling tube clamp in `cad/src/model.py`, with a clearance check against the tube slots.
3. Decision 4 (build plan pictures and renders): Add the slack loop and its tie to the stilling tube clamp to the drain kit step text and picture of FLG-BLD-001, and the grate-lifting sequence to the maintenance notes.
4. Decision 5 (calculations): Change the R12 target in `docs/04-calcs/sizing.py` to 120 min for the pilot surface route (90 min at permanent sites) and rerun so that `results.csv` and FLG-CAL-001 match the hand-edited v0.5.
5. Decision 7 (build plan pictures and renders): Redo the render-only pole kit layout for the node at 3.4 m and the panel at 40 degrees, and update the caption's heights.
6. Decision 12 (BOM): Specify and price tamper-resistant screw heads and nuts for the marker bands, covers, riser guard and anchors (lines 7 and 8 and the anchors) in `bom/bom.csv`, and rerun the cost line [M1].
7. Decision 12 (documents): Name the tamper-resistant fixings and the driver bit they need in the build plan's tools list and in the cover, riser guard and marker steps of FLG-BLD-001.

### Points found in the review

- Item 9 is a duplicate: the side gland and cable route are already change P5 of FLG-DDR-003, so accepting item 1 adopts it.
- Item 7's figures (kit drawn 3.3 m lower, node centre 0.74 m) date from 2026-09-26, when the node was at 3.0 m; the node is now at 3.4 m and the panel at 40°, so the render layout and caption are stale.
- Item 3's 0.01 kg margin is effectively zero on estimated masses; the 2.00 kg of covers and riser guard are excluded from R15 because they stand on the sidewalk, which is correct but should be stated in R15's wording.
- The FieldNode core cost moved from USD 126.00 to USD 139.00 with its constructable design; the value-engineering comparison correctly excludes it, but docs/01-problem.md (line 66, '$126.00' and '$153.50') and the inputs table of FLG-CAL-001 (line 53, '$126.00', '2.41 kg') still carry the old figures.

TRL 4 remains on hold by Amish's instruction.

## Session 2026-10-02: approved follow-ups carried out

Authority: Amish, 2026-10-02, approved every follow-up action from the open-decision sign-off. `trl` and `trl_target` stay at 3; `budget_usd` is unchanged at 160. No commit or push.

### Follow-ups

1. Decision 1, appearance model for the constructable design: done. `cad/src/product_model.py` failed to run and still described the 2026-09-26 layout. It now takes every part it shares with the design (bracket plate on V-blocks and band clamps, cleats, arm, brace in its clips, head plate, radar housing and lens, through-bolt, node enclosure, lid, back plate, panel bracket, 40 degree panel, marker and band clamps, riser guard, three covers, anchors, tube, pipe clamps, drain head, cables, slack loop and ties) from `cad/src/model.py`, and adds only paint, accent bands, lid window, name plate, status light and the street context. The dropped detail of 2026-09-26 (cell, board and radio inside the node, lid screws, ports, plugs, ridges) was not in the model.
2. Decision 4, slack loop in the model: done. A 0.5 m loop (about 0.51 m of cable) hangs in the basin beside the tube, tied to the upper pipe clamp with two ties. New checks: clear of the tube and its slots (79 mm), the drain head (5 mm), basin wall, pipe clamps and the road slab and grate, and joined to the cable and the tie. Constructability checks: 119 of 119 pass. STEP and STL regenerated.
3. Decision 4, drain kit text, picture and maintenance notes: done. New Figure 22 (Joint 9, `docs/05-build-plan/joint-09.png`); step 13 picture and text now make the loop and tie it to the clamp; step 14 refers to it; new "Lifting the grate for cleaning" notes in the build plan, with the cleaning review after the first visit.
4. Decision 5, R12 target: done. `sizing.py` rerun with R12 at 120 min for the pilot surface route (90 min at permanent sites); `results.csv` and FLG-CAL-001 agree.
5. Decision 7, render-only pole kit layout: done. The arm kit is drawn 3.3 m lower (lens 1.3 m instead of 4.6 m) and the node and its 40 degree panel 2.9 m lower (centre 0.5 m instead of 3.4 m); the view notes state both heights.
6. Decision 12, tamper-resistant fixings priced: done. Line 7 USD 26.00 to 32.00 (eight snake-eye security nuts at about USD 0.75), line 8 USD 10.00 to 13.00 (pin-Torx TR25 screws), line 10 USD 6.00 to 12.00 (the two bits). Prices are indicative, not quotes.
7. Decision 12, fixings in the build plan: done. Tools list, bought parts, marker, riser guard and cover texts, steps 11 and 14 and the cover making sketches name the security nuts, screws and bits.

### Requirement status changes

- R12: Not met to met on paper (the 2026-10-02 decision; now also stated in `results.csv`).
- R16: stays over the target, now by USD 45.50 (was USD 30.50). Value-engineering target: USD 160. Estimated cost of the constructable design: USD 205.50 (USD 45.50 over the target). With the USD 139.00 FieldNode core: USD 344.50.
- R15: unchanged, 4.99 kg on the pole (the loop and ties are in the basin).
- No other status changed.

### Pictures regenerated

FLG-DWG-001 Rev P5; making sketches FLG-DWG-111 (riser guard), 114 to 116 (covers) and the marker; `joint-09.png` (new); `step-11.png`, `step-13.png`, `step-14.png`; concept media (hero, cutaway, flow, exploded, blueprint, `model.glb`).

### Documents changed and new versions

FLG-CAL-001 v0.6; FLG-REQ-001 v0.8; FLG-PRC-001 v0.8; FLG-PRB-001 v0.6; FLG-DEC-001 v0.3; FLG-BLD-001 v0.3. Also `README.md`, `bom/bom.csv`, `bom/bom-notes.md`, `docs/04-calcs/sizing.py` and `results.csv`, `cad/src/model.py`, `sheets.py`, `build_plan_media.py`, `concept_media.py`, `product_model.py`. Points raised in the 2026-10-02 review as stale are fixed: the old USD 126.00 and 2.41 kg FieldNode figures in FLG-PRB-001 and FLG-CAL-001.

### Render scenes

Exported to `/home/claude/renders/floodgauge`: views hero, exploded and detail, with `floodgauge__jobs.json`. Photoreal images, `card.png` and `social-preview.png` are to be made on Amish's Mac.

### Cross-repo actions

- FieldNode (FND-BLD-001): none needed from this session; FloodGauge cites its USD 139.00 and 2.45 kg.

### Not done

None.

### Decisions proposed and awaiting Amish

None new. The 0.01 kg margin on R15 stands as decided (a 2.5 mm bracket plate is the named fix if the weighed mass is over 5.0 kg).

## Session 2026-09-25: /populate to a strong TRL 2

### What was done

- `docs/01-problem.md` (FLG-PRB-001 v0.2): problem in numbers with cited sources, the two ways streets flood (drain backing up and blocked inlet), users, operating context, constraints, prior work (FloodNet, low-cost ultrasonic and 60 GHz radar modules), out of scope, open questions; co-design checklist kept.
- `docs/03-requirements.md` (FLG-REQ-001 v0.2): 17 measurable requirements (R1 to R17) with targets, verification method and status at TRL 2, plus assumptions and a list of requirements not met.
- `docs/02-concept.md` (FLG-PRC-001 v0.2): how it works, numbered components, first-order numbers with assumptions, design choices with options, safety section, open questions.
- `cad/src/concept_media.py`: massing model of a street strip (road, gutter, curb, sidewalk), catch basin with outlet and illustrative water level, existing sign pole, and the kit parts numbered 1 to 8. The scene uses a manually placed 1.75 m person on the sidewalk as a context part, because the kit's automatic scale figure would stand on the basin floor. A custom exploded view shows the kit parts only, so the street and basin do not hide them.
- `media/`: `hero.png`, `concept-blueprint.png`, `.pdf` and `.svg`, `cutaway.png` (section across the street through the inlet), `exploded.png` with BOM callouts, `flow.png` (data flow from water surface to alert), `model.glb` and `viewer.html`.
- `bom/bom.csv`: 10 lines with indicative USD prices; items 1 to 8 match the exploded view. `bom/bom-notes.md` updated.
- `README.md`: hero image and links line; Concept rationale, Burning platform, Where it could be used (6 industries, 6 countries or regions) and What sparked the idea expanded with cited sources; Key components and Safety updated to match the concept.
- `docs/pdf/`: branded PDFs of the three controlled documents.

### Key results (estimates, to be checked at TRL 3)

| Quantity | Estimate | Requirement |
| --- | --- | --- |
| Street depth range | 0 to 600 mm with the head about 2.95 m above the road | R1 met |
| Street depth error, radar | temperature effect negligible; module accuracy unverified | R2 met on paper |
| Street depth error, ultrasonic | about ±100 mm uncompensated, about ±15 mm compensated | R2 not met |
| Drain level error | about ±15 mm | R4 met on paper |
| Sensor load | about 1.2 mW at 60 s sampling, about 7 mW at 10 s | R8 met (FieldNode allowance about 115 mW) |
| Uplink airtime | about 24 s/day normal; about 15 s per event hour | R7 partly met |
| Alert latency | about 70 s typical, about 110 s worst case | R6 met on paper, thin margin |
| Mass on the pole | about 3.1 kg | R15 met |
| Parts cost | about $271 including the $126 FieldNode; about $145 FloodGauge-specific | **R16 not met** |

Requirements not met or at risk:

- **R16 cost not met:** about $271 against the $150 in `project.yaml`.
- **R9 submersion not met** by the stock IP67 ultrasonic module; a potted head is proposed but unproven.
- **R7 not met on The Things Network** for events longer than about 24 min at 1 min reporting (fair use 30 s/day).
- **R12 installation at risk:** the conduit from basin to pole needs coring and trenching.
- **R10 false alerts unverified:** parked vehicles or people under the street head must be rejected by plausibility logic.

### Proposed, awaiting Amish (status updated 2026-09-25: see FLG-DDR-002)

1. **Budget.** Options: (a) cost FieldNode in its own repo and hold FloodGauge-specific parts to $150 (about $145 now); (b) raise `budget_usd` to $300; (c) cut to a street-only ultrasonic variant (about $188, still over $150, and misses R2). Recommendation: (a), with R16 reworded as "FloodGauge-specific parts $150 or less; FieldNode costed separately". `project.yaml` is unchanged. **Decided by Amish, 2026-09-25: go with recommendation.**
2. **Two heads on one node** (street and drain) versus street only or drain only. Recommendation: both. **Decided by Amish, 2026-09-25: go with recommendation.**
3. **Street head sensing:** 60 GHz radar versus ultrasonic. Recommendation: radar, with ultrasonic documented as the lower-cost variant. **Decided by Amish, 2026-09-25: go with recommendation.**
4. **Drain head:** ultrasonic in a slotted stilling tube with a wet probe, versus radar. Recommendation: ultrasonic in a tube. **Decided by Amish, 2026-09-25: go with recommendation.**
5. **Arm over the gutter** versus a head over the sidewalk. Recommendation: over the gutter at 2.95 m or higher, subject to the road authority's clearance rules. **Decided by Amish, 2026-09-25: go with recommendation.**
6. **Alert bands** at 150 mm and 300 mm of water above the road, from NWS guidance, plus a drain-full alert. Recommendation: defaults, to be set locally with the partner city. **Decided by Amish, 2026-09-25: go with recommendation.**
7. **Network:** private or city LoRaWAN gateway (TwinKit) for event reporting, TTN for pilots only. Recommendation: private gateway. **Decided by Amish, 2026-09-25: go with recommendation.**
8. **Pilot partner and city** for co-design and a first site. No recommendation; still Proposed, awaiting Amish.
9. `project.yaml` pitch and problem: no change proposed; the numbers found support them. **Decided by Amish, 2026-09-25: go with recommendation.**

### Safety concerns

- Work beside live traffic and at height on poles near overhead lines.
- Catch basins are confined spaces with possible toxic or oxygen-poor air and fast-rising water; the design is installed from the surface only. Heavy grates are a crush hazard. Stormwater is a biological and chemical hazard.
- LiFePO4 cell in FieldNode (about 19 Wh): fusing and the 0 to 45 °C charge window.
- Over-reliance: a silent or failed gauge can hide a flood. The alert service must flag missing reports, and FloodGauge must be presented as a supplement to official warnings.
- An arm over the gutter can be struck by tall vehicles if mounted too low.

### Problems and notes

- The kit's automatic scale figure is placed at the lowest point of the model (here the basin floor), so the person is passed as a context part instead. The hero note therefore reads "Grey: Person, 1.75 m (scale) for scale", and the blueprint isometric sublabel reads "grey is for scale".
- Radar module accuracy, current and price could not be verified from a data sheet in this session; the estimates are marked as assumptions.
- The legacy `cad/src/model.py` placeholder is untouched (TRL 3 work).

### Recommended next step

Review this note and the media, then decide items 1 to 5. If approved, run `/advance-trl3` to check the error budgets, latency and airtime by calculation, confirm the radar module data, and produce the parametric model and drawing sheet.

## Session 2026-09-25: TRL 3

On 2026-09-25 Amish asked for this batch of repos to be taken through the usual process with the instruction "you know the drill, nothing gets past TRL 3". He has not reviewed this repo's TRL 2 items one by one, so every item that carried a recommendation is adopted as recommended for TRL 3 under Amish's 2026-09-25 instruction, open for his review. This session ran `/advance-trl3` on that basis and stopped at TRL 3.

### What was done

- `docs/decisions/0001-trl2-review-decisions.md` (FLG-DDR-001 v0.1, status proposed): nine items adopted as recommended for TRL 3, open for Amish's review (D1 to D9), and one left open (O1, pilot partner and city).
- `docs/04-calcs/01-sizing.md` (FLG-CAL-001 v0.1) and `docs/04-calcs/sizing.py`: range and geometry, street and drain error budgets, stilling tube hydraulics, energy, airtime, alert latency (simulated), false readings, arm and clamp loads, mass, cables and ports, submersion, installation time and cost, with a status for every requirement. The script imports the model, reads the BOM and `project.yaml`, prints every number the note quotes with a tag, and writes `docs/04-calcs/results.csv`.
- `cad/src/model.py`: parametric build123d model (FieldNode core and panel, radar head, arm with brace and band clamps, drain head, slotted stilling tube with brackets, cables, conduit and riser guard, depth marker with bands) plus the existing street, basin and pole as context. Exports `cad/step/` and `cad/stl/` for `floodgauge-assembly`, `floodgauge-pole-kit`, `floodgauge-drain-kit` and `floodgauge-site`.
- `cad/src/sheets.py` and `cad/drawings/FLG-DWG-001.svg`, `.pdf`, `.png`: general arrangement at Rev P1 (overall views 1:50, Detail A 1:10, Section B 1:20), marked "CONCEPT, NOT FOR FABRICATION" and "PRELIMINARY, NOT FOR FABRICATION". FLG-DWG-001 was free because the concept blueprint is FLG-DWG-010.
- `bom/bom.csv` (10 lines, all priced with a supplier or supplier type) and `bom/bom-notes.md`: $145.50 FloodGauge-specific against the $150 budget; $271.50 with FieldNode.
- `cad/src/concept_media.py` now builds from the model; all of `media/` was re-rendered and every image checked; temporary `_views` folders deleted.
- FLG-PRB-001, FLG-PRC-001 and FLG-REQ-001 revised to v0.3; `README.md` (TRL badge and line, budget line, links, components, key numbers, safety) and `project.yaml` (`trl: 3`, `trl_target: 3`, evidence list) updated. PDFs rebuilt in `docs/pdf/`.

Design changes found necessary by the calculations, within the adopted choices: an NTC in the drain head for speed-of-sound compensation (+$0.50), a recorded dry-road background for the radar because its beam lights the curb, and the FieldNode lowered from 2.5 m to 2.35 m so that its panel clears the knee brace.

### Requirement status (FLG-CAL-001, Table 4)

2 not met, 3 at risk, 1 not verifiable at TRL 3, 8 met on paper, 3 met by design.

| ID | Status | Key number |
| --- | --- | --- |
| R3 Drain level range | **Not met** | Continuous only to 330 mm below the road; the top 290 mm below the grate has the wet probe alone (TRL 2 said met by design) |
| R12 Installation | **Not met** | 90 min for surface work alone; the conduit needs coring and trenching |
| R7 Airtime | At risk | 23.7 s/day at SF9; event reporting breaks 1 % at SF11 and SF12; TTN allows about 27 min of events at SF9 |
| R9 Submersion | At risk | 0.90 m over the head at 600 mm street depth; transducer face only IP67 |
| R14 Environment | At risk | Inherits FieldNode's interior heat finding; drain module rated -15 to 60 °C |
| R10 False readings | Not verifiable at TRL 3 | Rules defined; the curb echo would read 139 mm if not rejected |
| R1, R2, R4, R6, R8, R13, R15, R16 | Met on paper | 2.95 to 2.35 m range; ±6.3 mm radar (module accuracy assumed); ±11.0 mm drain; 82 s at the 95th percentile, 110 s worst; 68 days autonomy; ±5 mm datum; 4.62 kg; $145.50 |
| R5, R11, R17 | Met by design | |

Key numbers: 85.1 mJ per sampling cycle; 9.3 % of the FieldNode 100 mW allowance with event sampling all day; tube lag under 5 mm at 50 mm/s; arm twist factor 1.45 in a 35 m/s gust; 50 kg hanging on the head stresses the arm to 36 MPa.

### Decisions recorded (FLG-DDR-001)

Adopted as recommended for TRL 3 under Amish's 2026-09-25 instruction, open for his review, and since then Decided by Amish, 2026-09-25: go with recommendation (FLG-DDR-002): D1 FieldNode costed in its own repo, R16 restated to "FloodGauge-specific parts $150 or less; FieldNode costed separately" (`budget_usd` unchanged at $150; no new figure was recommended); D2 two heads on one node; D3 radar street head, ultrasonic as the lower-cost variant; D4 ultrasonic drain head in a slotted stilling tube with a wet probe; D5 arm over the gutter at 2.95 m or higher, subject to clearance rules; D6 alert bands 150 mm and 300 mm plus drain-full, set locally with the partner city; D7 private or city gateway for event reporting, TTN for pilots only; D8 levels only, no imaging; D9 no change to pitch or problem, so `project.yaml` and `README.md` keep the existing wording.

### Still awaiting Amish

1. **O1, pilot partner and city** for co-design and a first site. No preference stated; no recommendation made.
2. **New, R3 wording.** Recommendation: restate R3 as "continuous reading from 50 mm above the basin floor to 330 mm below the road, plus a drain-full signal above that". **Decided by Amish, 2026-09-25: go with recommendation.** Applied (DDR-002 N1).
3. **New, head height and R1.** At 2.95 m the head is inside a 4.0 to 4.3 m vehicle envelope at the curb. Options: (a) widen the R1 mounting band to 2.5 to 5.0 m and set the height per site to the road authority's clearance rule (about 4.6 m where trucks use the curb lane); (b) keep 2.95 m only where the curb lane carries no tall vehicles. Recommendation: (a). **Decided by Amish, 2026-09-25: go with recommendation.** Applied (DDR-002 N2).
4. **New, R12 cable route.** Options: (a) conduit as now (civil work); (b) surface route out at the grate frame and along the curb face under a bolted steel cover; (c) a second FieldNode for the drain head. Recommendation: (b) for pilots, (a) at permanent sites installed with road works. **Decided by Amish, 2026-09-25: go with recommendation.** Applied (DDR-002 N3).
5. **New, arm anti-rotation.** Friction alone gives a twist factor of 1.45. Recommendation: add a through-bolt or pinned clamp as a design detail. **Decided by Amish, 2026-09-25: go with recommendation.** Applied as a through-bolt (DDR-002 N4).
6. **Suggestion only, not in the repo:** a first alert band below 150 mm, since in a fast flood the 150 mm alert arrives at about 190 to 250 mm; a matter for the partner city under D6. **Decided by Amish, 2026-09-25: go with recommendation.** Applied as a configurable band, depth set with the partner city (DDR-002 N5).

### Cross-repo consistency

- FieldNode (FND REVIEW, TRL 3): FloodGauge uses its 15.36 Wh usable, 4.0 mWh/day core, 246.8 ms SF9 airtime, 2.41 kg, $126.00 and two M12 ports with one switched rail each (street head at 3.3 V on port A, drain head at 5 V on port B, which uses the analog pin for the wet probe). FloodGauge's worst load (9.3 mW) fits the 100 mW allowance FieldNode recommends, so FieldNode's allowance proposal does not affect this repo. The pin assignment is still FieldNode O2. No conflict.
- FieldNode's R3 (interior heat) and R2 findings carry into FloodGauge R14 as at risk. FieldNode's proposed sun shield would add 0.15 kg, taking FloodGauge to 4.77 kg against 5.0 kg; still within R15.
- FieldNode mass rose from 1.7 kg (TRL 2 estimate used here) to 2.41 kg; FloodGauge's mass figure is updated accordingly.
- TwinKit (TWK REVIEW, TRL 3): the 4.7 s worst forwarding latency and the 1 % uplink loss target are used in the latency budget. TwinKit's R1 loss is marginal at SF9 with 50 nodes at 5 min; FloodGauge's 1 min event reporting adds load during storms, when every gauge in a city reports at once. Worth a check in TwinKit when a pilot size is known; noted here, TwinKit not edited.
- No other shared component (CellGuard, MotionCore, ThermaCart, CalRig) is used.

### Safety concerns

- Vehicle strike: an arm at 2.95 m over the gutter can be hit by trucks, buses or mirrors at the curb. Mount to the road authority's clearance height.
- Arm rotation in high wind (factor 1.45) could swing the head over the traffic lane; add an anti-rotation stop.
- Catch basins are confined spaces with possible toxic or oxygen-poor air and fast-rising water; installation is from the surface, but drilling anchors through the grate opening still needs care. Heavy grates are a crush hazard. Stormwater is a biological and chemical hazard.
- Work beside live traffic and at height near overhead lines.
- FieldNode LiFePO4 cell (about 19 Wh): fusing, protection and the 0 to 45 °C charge window, as in FieldNode.
- Over-reliance: a silent gauge can hide a flood; the alert service flags gauges silent for 30 min, and FloodGauge supplements official warnings.

### Gaps and notes

- Citations: no citations were flagged as unchecked in the TRL 2 note. WebFetch confirmed the A02YYUW figures on the DFRobot page (±1 cm, 60°, 8 mA or less, 100 ms, -15 to 60 °C, IP67, $15.90). The Acconeer products page confirmed only the 20 m range and module size; the XM125 product page returned 404 and a distributor page returned an unrelated part, so the radar's accuracy, current, beam width and price remain assumptions and are marked so.
- The kit's cutaway cuts at the mean Y of the parts and keeps the far half; with the scene rotated 180° about Z (as at TRL 2) it shows the section through the inlet and the tube, so no shift was needed.
- In `media/exploded.png`, callout 2 partly covers the small radar head.
- Existing material beyond TRL 3: `build-log/README.md` (scaffold) is present, untouched and not extended. `firmware/` and `electronics/` hold only placeholders. No test, build or firmware material was created.

### Recommended next step

TRL 4 is on hold by Amish's instruction; this repo stops at TRL 3. Amish's review is needed on D1 to D9, on O1 and on the new items 2 to 5 above. For the record only, TRL 4 would need: a bench build of both heads on a FieldNode; a lab test report (TST, `environment: lab`) covering radar depth accuracy over a water tank with a curb step in the beam, ultrasonic level accuracy in a slotted tube over temperature, immersion of the drain head, sampling energy and the end-to-end alert latency through a gateway; and build log entries. None of this has been started.

## Session 2026-09-25: recommendations accepted

On 2026-09-25 Amish wrote, in chat: "i accept all your recommendations, go with them across all repos." Every item with a recommendation is now **Decided by Amish, 2026-09-25: go with recommendation**, recorded in `docs/decisions/0002-recommendations-accepted.md` (FLG-DDR-002 v0.1). Items without a recommendation stay "Proposed, awaiting Amish".

### Decisions applied and what changed

- **D1 to D9** (FLG-DDR-001, now v0.2): status wording only. `budget_usd` stays $150, the recommended figure; the pitch and problem are unchanged (D9).
- **N1, R3 restated** to "continuous reading from 50 mm above the basin floor to 330 mm below the road, plus a drain-full signal above that". R3: not met to met on paper.
- **N2, head height:** R1 band 2.5 to 3.5 m to 2.5 to 5.0 m, set per site. Reference lens 2.95 m to 4.6 m (clears a 4.3 m vehicle plus 0.3 m); existing pole in the model 3.3 m to 4.9 m above the sidewalk. Knock-on change: FieldNode center 2.35 m to 3.0 m and street cable 2 m to 3 m, because a 5 m I2C cable would reach about 550 pF against 400 pF (now 350 pF). Radar depth error ±6.3 mm to ±6.5 mm (pole expansion over the taller height).
- **N3, cable route:** conduit (coring and trenching) to a surface route for pilots under 0.76 m of bolted steel cover, anchored to the curb and sidewalk only. BOM line 7 $8.00 to $14.00. Installation 90 min plus civil work to 120 min with none.
- **N4, anti-rotation:** M8 A4 through-bolt at the lower clamp. Twist factor 1.45 to 37. BOM line 3 $18.00 to $20.00.
- **N5, first alert band below 150 mm:** supported by the alert service, depth set with the partner city (no figure chosen).
- **Totals:** FloodGauge-specific parts $145.50 to $153.50; complete gauge $271.50 to $279.50. Mass on the pole 4.62 kg to 4.74 kg.
- **Files:** `cad/src/model.py` (STEP and STL re-exported), `cad/src/sheets.py` and FLG-DWG-001 Rev P1 to P2, `cad/src/concept_media.py` and all of `media/` re-rendered (hero, blueprint and exploded checked; `_views` folders removed), `docs/04-calcs/sizing.py` and FLG-CAL-001 v0.1 to v0.2, FLG-REQ-001 v0.3 to v0.4, FLG-PRC-001 v0.3 to v0.4, `bom/bom.csv`, `bom/bom-notes.md`, `project.yaml` (evidence list), `README.md` (key components, numbers, safety; "What sparked the idea" rewritten around the September 2021 Ida flooding in New York City). PDFs rebuilt; superseded PDFs removed from `docs/pdf/`.

### Requirement status (FLG-CAL-001 v0.2)

2 not met, 3 at risk, 1 not verifiable at TRL 3, 8 met on paper, 3 met by design.

| ID | Status | Key number |
| --- | --- | --- |
| R12 Installation | **Not met** | 120 min on the surface route, no civil work (target 90 min) |
| R16 Cost | **Not met** | $153.50 FloodGauge-specific against $150 |
| R7 Airtime | At risk | Unchanged: 23.7 s/day at SF9; event reporting breaks 1 % at SF11 and SF12 |
| R9 Submersion | At risk | Unchanged: transducer face only IP67 |
| R14 Environment | At risk | Unchanged: FieldNode heat; drain module rated -15 to 60 °C |
| R10 False readings | Not verifiable at TRL 3 | Curb echo would read 143 mm if not rejected |
| R1, R2, R3, R4, R6, R8, R13, R15 | Met on paper | Lens 4.6 m, 1.9 to 5.0 m over the band; ±6.5 mm; restated R3; ±11.0 mm; 82 s at 95 %; 68 days; ±5 mm; 4.74 kg |
| R5, R11, R17 | Met by design | |

### Still awaiting Amish

1. **O1, pilot partner and city.** No recommendation. The depth of the N5 band waits on it.
2. **New, R16 over budget by $3.50.** Options: (a) raise `budget_usd` to $160; (b) hold $150 and cost the surface cover as site installation material, like the conduit it replaces; (c) hold $150 and find savings in the radar housing once a data sheet and quote exist. Recommendation: (b), since the cable route depends on the site and the conduit was already outside the total. Not applied; `budget_usd` stays $150. **Decided by Amish, 2026-09-26: `budget_usd` $160 (option (a)); see "Session 2026-09-26: budget approved".**
3. **New, R12 at 120 min.** Options: (a) relax R12 to 120 min for the pilot route; (b) keep 90 min and prefabricate the cover and bracket set to cut site time (unproven). Recommendation: (a). Not applied.

### Cross-repo actions (other repos not edited)

- **FieldNode:** FloodGauge now mounts the core at 3.0 m (was 2.35 m) and relies on FND-CAL-001's $126.00 and 2.41 kg under D1; the port pin assignment (FieldNode O2) and the sun shield (0.15 kg, would give 4.89 kg on the pole, still under 5.0 kg) remain FieldNode's to settle.
- **TwinKit:** check gateway loss at SF9 when every gauge in a city reports every minute in a storm, once a pilot size is known (carried from the TRL 3 session).

### Safety

- The arm at 4.7 m needs a mobile elevating platform and clearance from overhead lines; drilling the pole for the through-bolt needs the asset owner's permission.
- The surface cable cover crosses the sidewalk: low, beveled, anchored and marked to avoid a trip hazard.
- Confined space, traffic, stormwater and LiFePO4 notes from the earlier sessions stand.

### Gaps and notes

- Callouts 2 and 4 in `media/exploded.png` sit over the small radar and drain heads, which are small at the scale needed for a 4.9 m pole.
- Radar module accuracy, current and price are still assumptions; the cover and bolt prices are indicative.

### TRL 4

TRL 4 remains on hold by Amish's instruction. No build, test, purchasing, PCB or firmware work was done.

## Session 2026-09-26: budget approved

Amish wrote, in chat on 2026-09-26: "i approve all the budget items." The open R16 budget item (O2) is decided: budget set to $160 to cover the priced BOM (FLG-DDR-002 v0.2).

- `project.yaml` `budget_usd` $150 to $160; README budget and cost lines updated.
- R16 target $150 to $160; status **not met to met on paper** ($153.50 FloodGauge-specific, $6.50 under; $279.50 with the FieldNode core, which stays costed in its own repo).
- Requirement counts (FLG-CAL-001 v0.3): 1 not met (R12), 3 at risk, 1 not verifiable, 9 met on paper, 3 met by design.
- Documents: FLG-PRB-001 v0.4, FLG-PRC-001 v0.5, FLG-REQ-001 v0.5, FLG-CAL-001 v0.3 (`sizing.py` target now read from `budget_usd`; `results.csv` regenerated), FLG-DDR-002 v0.2; `bom/bom-notes.md`; PDFs rebuilt. No media shows the budget, so none was regenerated.

## Session 2026-09-26: product appearance model and photoreal renders

Amish chose this repo for the first batch of product renders on 2026-09-26.

### What was added

`cad/src/product_model.py` exposes `product_parts()` (68 parts: 42 shell, 9 internal, 10 accessory, 7 context), `TITLE` and `RENDER_VIEWS` (hero, exploded and a detail view of the pole kit without the street). It reuses PARAMS, derived() and bands() from `cad/src/model.py`; every part size, the head offset past the curb face, the arm length, the clamp spacing, the knee brace, the M8 through-bolt, the node's place on the road side of the pole, the marker plate and bands, the cable cover and riser guard, and the drain head and stilling tube positions are as model.py. It adds:

- FieldNode core (item 1): filleted enclosure with side ribs and a lid parting line, a lid with a clear window over the board and the LiFePO4 cell, four lid screws, a teal name plate, a lit green status light, two M12 sensor ports and a vent plug on the underside, back plate and pole straps; inside, the MPPT and LoRaWAN board with its radio shield can and flex antenna, and the 6 Ah cell in a holder.
- 6 W panel: aluminium frame, dark cells under glass with grid lines, and a mounting blade, in the model.py pose (25° toward the road).
- Street radar head (item 2): filleted housing with a parting groove, a teal band and a label, a side M12 cable gland, the PTFE lens in a retaining ring, and the radar module on its carrier board.
- Sensor arm (item 3): aluminium tube with end caps, head saddle and screws, two band clamps with bolted ears, the knee brace, and the M8 through-bolt with its nyloc nut and washer.
- Sensor cables (item 6): the street cable from the head gland along the arm and down the pole, the drain cable from the riser guard to the node, M12 plugs and cable ties.
- Depth marker plate (item 8) with amber and red bands, tick marks and rivets; surface cable cover (item 7) as a ridged angle over the gutter strip, a plate up the curb face and a beveled cover across the sidewalk, with the riser guard and masonry anchors.
- Drain head (item 4): cap with a teal band and top gland, potted base, ultrasonic transducer, wet probe pins and NTC bead; stilling tube (item 5) with its 40 slots (10 rows of 4) and two wall brackets.
- Context (not in the BOM): a compact street patch with asphalt, a concrete gutter strip, the cast iron grate over a dark basin throat, the curb and sidewalk, a thin sheet of ponding stormwater (illustrative), and a section of the existing pole.

`README.md` now shows `media/render-hero.png` and links `media/render-exploded.png`; the orchestrator produces both files.

### Differences from model.py (Proposed, awaiting Amish)

1. **Render layout of the pole kit.** Installed, the lens is 4.6 m above the road and the node center 3.0 m, so a true-scale render would show a tall bare pole with small devices. The appearance model draws the arm, clamps and head 3.3 m lower (lens 1.3 m above the road) and the node 2.26 m lower (center 0.74 m), just under the lower clamp; the pole section is cut off 170 mm above the arm. All sizes and horizontal offsets are unchanged, and the marker plate, cable cover and riser guard stay at their true heights. Proposed, awaiting Amish. Recommendation: keep this as a render-only layout with the hero caption saying the kit is drawn lower than installed (the view note does); the installed heights stay as in model.py and FLG-DWG-001. Option: render the true heights, accepting a small device in a tall frame.
2. **Drain kit only in the exploded view.** The drain head and stilling tube sit inside the catch basin, 0.3 to 1.24 m below the road, so they are in the "accessory" group: the exploded view lifts them beside the pole kit, and the hero and detail views leave them out. Proposed, awaiting Amish. Recommendation: accept, and consider a later cutaway render through the basin if the drain side needs a product image of its own.
3. **Cable routes.** model.py draws the cables as straight boxes (street cable vertical through the saddle and arm; drain cable up the pole behind it). The appearance model routes the street cable from a side gland on the head along the arm's side and down the pole beside the clamps to the node's M12 port, and the drain cable from the top of the riser guard to the other port. Cable lengths are not recomputed. Proposed, awaiting Amish. Recommendation: adopt the side gland on the head (it keeps the cable out of the saddle and gives a drip loop) and check the 3 m street cable length against the new route at the next calc revision.
4. **Appearance details not in the BOM text.** The clear window in the node lid, the name plate and status light, the panel mounting blade, the cable ties, the marker ticks and rivets, and the ridged angle profile of the cable cover are appearance choices; the FieldNode enclosure and panel follow the FieldNode repo and are not redefined here. Proposed, awaiting Amish. Recommendation: treat them as render detail only; if a clear-lid node is wanted, raise it in the FieldNode repo.

### Status

This is an appearance model only: no tolerances, no fabrication detail, nothing past TRL 3. `trl: 3` and `trl_target: 3` are unchanged, and TRL 4 remains on hold. model.py, the BOM and the other documents were not edited.

## Session 2026-09-27: kit 1.5.0 and image quality

- Kit 1.5.0 synced: STANDARDS v1.5 (sections 12 to 15: product renders, storefront images and image quality, public release, authorship and signing), `.kit/cards.py`, `.kit/image_qc.py`, `.kit/release_gate.py`, issue templates, and the `/render-product` and `/release` commands. `CLAUDE.md` now matches `.kit/CLAUDE.md`.
- Every `media/render-*.png` recaptioned from its original render with the new layout: the title, concept label and repository sit in a band above the render and the view note in a band below it, each line wrapped to the image width, so no text overlaps other text or the render or runs off the image. `media/card.png` and `media/social-preview.png` regenerated with the same rules.
- `python .kit/image_qc.py` and `python .kit/release_gate.py` pass. trl stays 3.

## Session 2026-10-01: design for construction and prototype build plan (kit 1.7.0)

On 2026-09-30 Amish approved the build plan format and asked for it across all repos, with outstanding decisions kept in a separate register, and wrote: "If you are realising that the design cannot be built as per concept - fix the design assumptions to match and be physically feasible as you draw the illustrations." On 2026-10-01 he set budgets as value-engineering targets. This session installed kit 1.7.0 and did `/build-plan` for FloodGauge. TRL stays 3.

### What was done

- Kit 1.7.0 installed (`.kit/`, `.claude/commands/`); `CLAUDE.md` matches `.kit/CLAUDE.md`.
- `cad/src/model.py` rebuilt as a constructable design with 110 constructability checks (`python cad/src/model.py --check`), all passing; STEP and STL re-exported.
- `docs/decisions/0003-design-for-construction.md` (FLG-DDR-003, Draft): every change, made under Amish's 2026-09-30 instruction to make the design physically buildable; open for his review.
- `docs/05-build-plan.md` (FLG-BLD-001 v0.1) with `cad/src/build_plan_media.py`: overview, 16 making sketches (`cad/drawings/FLG-DWG-101` to `116`), 8 joint close-ups and 14 assembly step pictures in `docs/05-build-plan/`.
- `docs/06-design-decisions.md` (FLG-DEC-001 v0.1): 12 open decisions, 8 items to confirm when parts are bought, a value-engineering section and the decisions made.
- FLG-CAL-001 v0.4 and `docs/04-calcs/sizing.py` (mass and cable runs now measured on the model; arm, bracket and fixing loads; cost against the value-engineering target); FLG-REQ-001 v0.6; FLG-PRC-001 v0.6; `bom/bom.csv` and `bom/bom-notes.md`; FLG-DWG-001 Rev P4; concept media regenerated; `project.yaml` (`design_state: constructable`, evidence list); `README.md` (links line, key numbers, "Building the prototype"). PDFs rebuilt.

### Design changes made for construction (FLG-DDR-003)

1. Pole bracket: the arm, which ran through the pole, now sits between two angle cleats on a 3 x 100 x 450 mm aluminium plate on two FieldNode V-blocks and two band clamps 400 mm apart; arm 805 to 715 mm.
2. Knee brace pinned at both ends in two folded clips (it touched the arm at one end and floated at the other).
3. M8 anti-rotation through-bolt runs across the street through the plate, a 20.2 mm spacer and the pole (it ran through a band clamp); M8 x 110 to M8 x 100.
4. Head plate under the arm carries the radar housing (the saddle block sat inside the housing); arm centre 4,710 to 4,713 mm so the lens stays at 4,600 mm.
5. Side gland on the radar head; street cable along the arm and down the pole to port A (it passed through the arm).
6. FieldNode drawn as its constructable design (FND-BLD-001) with its own V-blocks, bands and panel bracket; centre raised from 3.0 to 3.4 m so the street cable fits its 3 m I2C limit along the real route.
7. Drain cable comes up through the grate opening nearest the curb (the 5 mm grate-to-frame gap cannot pass a 10 mm cable).
8. Three bolted hat-section covers (gutter, curb face, sidewalk) and a U-channel riser guard strapped to the pole replace the unfixed angle and the riser guard that stood 250 mm from the pole.
9. Two stand-off pipe clamps hold the stilling tube (the brackets were set into the basin wall).
10. A 75 mm socket under the drain head slides over the tube top and is screwed (it rested on the tube).
11. Depth marker plate 3 to 2 mm, bottom 15 mm above the sidewalk, on two band clamps that also hold the riser guard.
12. To hold R15: arm and brace walls 2.0 to 1.6 mm and two windows in the bracket plate.

### Key results

- Mass on the pole 4.74 to 4.99 kg against 5.0 kg (R15 met on paper, 0.01 kg margin on estimates). Misuse case: arm 60 MPa (factor 3.6), brace 1,504 N against 73 kN buckling, band pull 1,063 N against 2,000 N. Twist factor 37 unchanged.
- Value-engineering target: USD 160. Estimated cost of the constructable design: USD 190.50 for FloodGauge-specific parts (USD 30.50 over the target); USD 329.50 with the FieldNode core.
- Requirement status: 1 not met (R12, installation 120 min against 90 min), 3 at risk (R7, R9, R14), 1 not verifiable at TRL 3 (R10), 8 met on paper, 3 met by design; R16 over the value-engineering target by USD 30.50.

### Proposed, awaiting Amish

All open items are in `docs/06-design-decisions.md`: review of FLG-DDR-003; node height 3.4 m; the thin R15 margin; grate lifting with the cable through the grate; R12 at 120 min; pilot partner and city; the four render items of 2026-09-26; alert governance; theft protection.

### Stale media (made on Amish's Mac)

The design changed visibly, so `media/render-hero.png`, `media/render-exploded.png`, `media/render-detail.png`, `media/card.png` and `media/social-preview.png` are stale, and `cad/src/product_model.py` still draws the concept arm, saddle, cover and node height. They were not regenerated here.

### Safety

The build plan carries safety stops for traffic, work at height, drilling the pole, the open catch basin and stormwater, and the FieldNode cell. The sidewalk cover is a trip hazard if not kept flat, beveled and marked. Drilling the pole needs the owner's written permission.

### Notes

- Kit: no kit files were edited. `.kit/build_views.py` drops a part silently when a window or cut intersection of a fused compound returns an empty shape (seen once on the pipe clamps; worked around by moving the cut plane 0.3 mm).

### Recommended next step

Amish reviews FLG-DDR-003 and the register. TRL 4 stays on hold; nothing was built or bought.

## 2026-10-02: photoreal renders redone on the constructable design

Rendered with Blender Cycles on Amish's Mac from the updated appearance model; captioned with `.kit/photo_caption.py`; `media/card.png` and `media/social-preview.png` regenerated with `.kit/cards.py`. Views: hero, exploded, detail. image_qc passes. Appearance deviations are those logged above as proposed, awaiting Amish.

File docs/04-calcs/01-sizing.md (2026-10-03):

---
doc_id: FLG-CAL-001
title: FloodGauge sizing calculations
project: FloodGauge
doc_type: Calculation
version: "0.6"
status: Draft
date: '2026-10-02'
author: Amish Chadha
license: CERN-OHL-S-2.0
revisions:
- version: "0.1"
  date: '2026-09-25'
  author: Amish Chadha
  change: First issue for TRL 3 (range and geometry, depth and level error budgets, tube hydraulics, energy, airtime, alert latency, false readings, arm and clamps, mass, cables, submersion, installation, cost)
- version: "0.2"
  date: '2026-09-25'
  author: Amish Chadha
  change: Recommendations accepted by Amish (DDR-002)
- version: "0.3"
  date: '2026-09-26'
  author: Amish Chadha
  change: Budget approved by Amish ($160); R16 from not met to met on paper
- version: "0.4"
  date: '2026-10-01'
  author: Amish Chadha
  change: Constructable design (FLG-DDR-003); arm, bracket and brace loads, mass from the model, cable runs along their real routes, cost against the value-engineering target
- version: "0.5"
  date: '2026-10-02'
  author: Amish Chadha
  change: "R12 status from the 2026-10-02 decision (120 min for the pilot surface route): met on paper; counts updated. Figures not rerun; sizing.py and results.csv still state the 90 min target"
- version: "0.6"
  date: '2026-10-02'
  author: Amish Chadha
  change: "Approved follow-ups: sizing.py rerun with the 120 min pilot R12 target; tamper-resistant fixings priced (cost USD 205.50, USD 45.50 over the target); drain cable slack loop modelled and checked; FieldNode inputs corrected to USD 139.00 and 2.45 kg"
---

# FloodGauge sizing calculations

This v0.4 checks the constructable design of FLG-DDR-003 (pole bracket on V-blocks and band clamps, pinned knee brace, head plate, FieldNode at 3.4 m, three hat-section covers, stand-off pipe clamps); sections H, I, J, L and M change, the rest stand. Version 0.2 applied the decisions Amish accepted on 2026-09-25 (FLG-DDR-002): the lens moves to 4.6 m so that it clears a 4.3 m vehicle at the curb, R1 allows 2.5 to 5.0 m set per site, R3 is restated, the pilot cable route runs on the surface under a bolted steel cover, and an M8 through-bolt stops the arm turning. The FieldNode moves up to 3.0 m so that the street head's I2C cable stays short. On 2026-09-26 Amish approved a `budget_usd` of $160 to cover the priced BOM (FLG-DDR-002). On paper, FloodGauge now meets thirteen of its seventeen requirements (ten by calculation, three by design), has three at risk and cannot verify one at TRL 3. R3 is now met on paper. R12 was not met against 90 min: the surface route removes the civil work, but fitting its cover brings the total to 120 min; on 2026-10-02 Amish relaxed R12 to 120 min for the pilot surface route (FLG-DEC-001, item 5), so it is met on paper. The parts added to make the design buildable take the FloodGauge-specific parts to $205.50, $45.50 over the value-engineering target of $160 (a hypothetical control target, not a limit), and the mass on the pole to 4.99 kg, 0.01 kg under R15's 5.0 kg. The three at risk are airtime at slow spreading factors (R7), immersion of the drain head (R9) and the operating environment inherited from FieldNode (R14). Every number in this note is printed by `docs/04-calcs/sizing.py`; the tag in brackets, for example [F2], is the line of that script's output that carries it.

> **Safety:** These are first-principles estimates for a paper proof of concept. They do not show that the gauge will warn anyone in time, and they are no substitute for tests of the heads, the enclosure or the alert chain. FloodGauge supplements official warnings. See FLG-PRC-001, Safety.

## Scope and method

The note checks every requirement in FLG-REQ-001 v0.6 against the design in FLG-PRC-001 v0.6 and the parametric model `cad/src/model.py`. The script imports the model's `PARAMS` and derived dimensions, so the head height, arm, tube, cable runs and marker used here are the ones in the STEP files and in drawing FLG-DWG-001 Rev P4. Masses of the made parts and the cable runs are measured on the model. It also reads `bom/bom.csv` and `budget_usd` in `project.yaml`, and writes the status table to `docs/04-calcs/results.csv`. Run it from the repo root with `python docs/04-calcs/sizing.py`.

The design case is a street with a 150 mm curb and a catch basin 1.3 m deep beside a 60 mm street pole 4.9 m tall above the sidewalk, with tall vehicles in the curb lane, air from -20 to 50 °C, a private LoRaWAN gateway (TwinKit) on EU868, and the FieldNode core as costed and sized in its own repo (FND-CAL-001).

## Assumptions

*Table 1. Main assumptions.*

| Area | Assumption | Basis |
| --- | --- | --- |
| Radar head | Distance accuracy ±2 mm; 60 mA at 3.3 V for 0.3 s per reading; half-power beam 25° with a PTFE lens; range up to 20 m | Range from [Acconeer](https://www.acconeer.com/products/); accuracy, current and beam are assumptions, since no data sheet could be checked in this session |
| Drain head | DFRobot A02YYUW: 3 to 450 cm, ±1 cm, 60° beam, 3.3 to 5 V, 8 mA or less, 100 ms response, -15 to 60 °C, IP67, UART | [DFRobot product page](https://www.dfrobot.com/product-1935.html), checked 2026-09-25; no built-in temperature compensation is stated, so none is assumed |
| Air temperature | Speed of sound 331.3 + 0.606 T m/s; calibration at 20 °C; ±3 K between air sensor and air column over the street; ±2 K for an NTC in the drain head | Standard approximation; sensor offsets assumed |
| Datum | Head height surveyed to ±5 mm (R13 limit); drain head face measured from the grate seat to ±3 mm; steel pole ±35 K from the survey day | R13; tape and level |
| Surface | ±3 mm residual ripple and rain splash after averaging 5 readings | Assumed |
| FieldNode | 15.36 Wh usable; core 4.0 mWh/day at 15 min reports; 16.0 mA s at 3.2 V per SF9 report; rails 90 %; allowance 100 mW design value, 115 mW ceiling; 2.45 kg; $139.00; autonomy at -20 °C is 0.70 of nominal | FND-CAL-001 |
| Controller | 5 mA at 3.3 V for 0.35 s per sampling cycle | Typical STM32WL-class figure; assumed |
| Radio | 20-byte payload plus 13 bytes overhead, 125 kHz, CR 4/5, 8-symbol preamble; EU868 1 % duty cycle; The Things Network fair use 30 s/day | FieldNode and TwinKit notes |
| Network | Gateway, network server and alert service 1 to 4.7 s (TwinKit worst 4.7 s); 2 to 10 s on a city or public server; 1 % uplink loss | TWK-CAL-001; assumed for public servers |
| Wind and loads | 35 m/s gust (q = 750 Pa); drag 2.0 on square tubes and 1.2 on the head; 6063-T6 class aluminium, E = 69 GPa, yield 214 MPa; band clamp preload 1,000 N, friction 0.3; misuse case of a 50 kg person hanging on the head | As FND-CAL-001; handbook values |
| Vehicles | Tall vehicles 4.0 to 4.3 m at the curb, 0.3 m clearance margin | Typical legal height limits; to confirm with the road authority |
| Through-bolt | M8 stainless A4-70, stress area 36.6 mm², shear 0.6 f_ub; pole wall 2.5 mm, f_u 360 MPa, bearing 2.5 f_u d t | Handbook values; pole wall assumed |
| Cables | 100 pF/m and 0.07 kg/m for outdoor 5-core cable | Assumed |

## A. Geometry and range (R1, R3)

- **Street range.** With the lens 4.6 m above the road, the radar sees 4.60 m to a dry road and 4.00 m at 600 mm depth, well inside its 20 m range [A1]. Over the whole R1 mounting band of 2.5 to 5.0 m the range runs from 1.9 to 5.0 m; at 5.0 m the assumed beam lights a circle of 1,108 mm radius, so the dry-road background matters more on tall sites [A1b]. R1 is met.
- **Curb echo.** An assumed 25° beam lights a circle of 1,020 mm radius on the road, which includes the curb 250 mm away. If the firmware picked the first echo, the curb top at 4,457 mm would read as 143 mm of water on a dry day [A2]. A beam narrow enough to miss the curb would need to be under 6.2° wide, which a small lens does not give [A3]. The street head therefore needs a recorded dry-road background at installation and tracking of the nadir peak; this is part of R10.
- **Drain range.** The drain head face is 300 mm below the road. The ultrasonic reads levels from 1,250 mm to 330 mm below the road (30 to 950 mm range, within the module's 30 to 4,500 mm), and the wet probe trips at 310 mm [A4]. The 50 mm level lies 10 mm below the tube mouth, in the beam path; the outlet invert is 100 mm above the floor, so the sump always holds water [A6].
- **R3 as restated.** Between 330 mm and 40 mm below the road (the grate underside), a 290 mm band, the only signal is the wet probe at one point [A5]. The drain head cannot rise higher, because the road slab and grate frame sit above it. In practice a basin in that band is surcharging, the wet probe says so, and the street head reads the water once it reaches the road. Under FLG-DDR-002, R3 now asks for a continuous reading from 50 mm above the basin floor to 330 mm below the road, plus a drain-full signal above that, so R3 is met on paper.
- **Vehicle clearance.** At 2.95 m (v0.1) the head was inside the envelope of a 4.0 to 4.3 m vehicle parked or passing at the curb. Under FLG-DDR-002 the reference lens height is 4.6 m, which clears a 4.3 m vehicle with the 0.3 m margin [A7]. Each site sets its own height within 2.5 to 5.0 m to the road authority's clearance rule. The site needs a pole about 4.9 m tall above the sidewalk; a shorter sign pole only suits a curb lane without tall vehicles.

## B. Street depth error (R2)

- **Radar.** The error budget is module ±2.0 mm (assumed), datum ±5.0 mm, pole expansion ±1.98 mm (the arm is now 4.71 m up) and surface ripple ±3.0 mm, which gives ±6.5 mm root sum square and ±12.0 mm if every term is at its worst at once [B1]. R2 (±10 mm) is met on paper by the root sum square, with the module accuracy still unverified.
- **Ultrasonic variant, uncompensated.** Calibrated at 20 °C, the range error is +349 mm at -20 °C and -231 mm at 50 °C, because the speed of sound runs from 319.2 to 361.6 m/s [B2].
- **Ultrasonic variant, compensated.** With an air sensor within ±3 K of the air column, the temperature term is ±24.4 mm and the total ±27.0 mm at the 4.6 m height [B3]. R2 is not met by the ultrasonic variant, which confirms the choice of radar (D3). Sun on the road makes the ±3 K figure itself optimistic.
- **Arm deflection.** The 40 x 40 x 1.6 mm arm (I = 60,503 mm⁴) moves 0.22 mm under a 1 kg bird at the head even without the brace [B4]; negligible.

## C. Drain level and stilling tube (R4, R3)

- **Error budget.** With the NTC in the drain head (±2 K) at the full 950 mm range, the temperature term is ±3.4 mm and the total ±11.0 mm [C1]. Without it (±10 K from a 20 °C calibration) the temperature term is ±16.8 mm and the total ±19.7 mm, just inside the target with no margin [C2]. R4 (±20 mm) is met on paper, and the NTC (BOM line 4, $0.50) is kept for margin.
- **Slots.** The 69 mm bore has 3,739 mm² of area. Forty slots of 5 x 50 mm in ten rows give 1,000 mm² per row and 10,000 mm² in all, 4.5 % of the wall [C3].
- **Lag.** With only the lowest row of slots wet, the level inside the tube lags the basin by 0.00 mm at 20 mm/min, 0.20 mm at 10 mm/s and 4.95 mm at an extreme 50 mm/s [C4]. The tube does not slow the reading; its job is to give the wide ultrasonic beam a clean path and to calm the surface.

## D. Energy (R8)

- **Per cycle.** A radar reading takes 59.4 mJ and an ultrasonic reading 12.0 mJ; with 90 % rail converters and 5.8 mJ for the controller, a cycle costs 85.1 mJ [D1].
- **Daily draw.** Normal sampling every 60 s is a 1.42 mW sensor load and 0.038 Wh/day with the FieldNode core. Event sampling every 10 s all day, with an uplink every minute, is 8.51 mW for the sensors plus 0.80 mW for the extra uplinks, 0.227 Wh/day in all [D2].
- **Against FieldNode.** Event sampling all day uses 9.3 % of the 100 mW FieldNode design allowance (115 mW ceiling) [D3]. The cell lasts 68 days without sun, or 47 days at -20 °C [D4]. R8 (5 days) is met with a wide margin.
- **Heat.** FieldNode's R3 finding (the cell too hot to charge on clear hot days) matters less here: even the 0.8 Wh a hot clear day stores without a shield exceeds the 0.227 Wh drawn [D5].

## E. Airtime (R7)

*Table 2. Airtime for a 20-byte reading [E1].*

| Spreading factor | Airtime per uplink | Normal mode (15 min) | Event mode (1 min) against 1 % (36 s/h) | Shortest interval under 1 % | Event minutes before The Things Network's 30 s/day |
| --- | --- | --- | --- | --- | --- |
| SF7 | 71.9 ms | 6.9 s/day | 4.3 s/h, met | 7 s | 344 |
| SF8 | 133.6 ms | 12.8 s/day | 8.0 s/h, met | 13 s | 138 |
| SF9 | 246.8 ms | 23.7 s/day | 14.8 s/h, met | 25 s | 27 |
| SF10 | 452.6 ms | 43.5 s/day | 27.2 s/h, met | 45 s | 0 (normal mode already over) |
| SF11 | 987.1 ms | 94.8 s/day | 59.2 s/h, **not met** | 99 s | 0 |
| SF12 | 1,810.4 ms | 173.8 s/day | 108.6 s/h, **not met** | 181 s | 0 |

- **R7 is at risk.** On a private gateway the 1 % duty cycle holds in event mode from SF7 to SF10, but not at SF11 or SF12, where the firmware must stretch event reporting to 99 s and 181 s. On The Things Network, an SF9 gauge in normal mode uses 23.7 of its 30 s a day and has room for only about 27 min of event reporting; at SF10 and slower even normal mode breaks the fair use limit (FieldNode R9). This supports D7: event reporting goes through a private or city gateway.

## F. Alert latency (R6)

The chain is: wait for the next sample, two confirming samples 10 s apart, about 1 s to wake and queue, the uplink, a possible duty-cycle wait of up to 24.4 s after a previous uplink, a repeat after a lost packet (1 %), and the gateway, network server and alert service.

*Table 3. Alert latency from a band crossing to the message leaving the alert service, 200,000 simulated events [F1].*

| Network | Case | Mean | 95th percentile | Largest simulated |
| --- | --- | --- | --- | --- |
| Private gateway | Slow rise from normal mode (60 s sampling) | 55 s | 82 s | 125 s |
| Private gateway | Already in event mode (10 s sampling) | 34 s | 52 s | 84 s |
| City or public server | Slow rise from normal mode | 58 s | 85 s | 134 s |
| City or public server | Already in event mode | 38 s | 55 s | 89 s |

- **R6 is met on paper.** The 95th percentile is 82 s on a private gateway and 85 s on a city server, against 120 s. The deterministic worst case without a lost packet is 110 s (60 + 20 + 1.2 + 24.4 + 4.7 s) [F2]; only a lost packet pushes an event past 120 s.
- **Depth at alert.** Water rising at 20 mm/min adds 37 mm between the crossing and the alert; at 100 mm/min, when the gauge is already sampling every 10 s, it adds 101 mm in 60 s [F3]. The 150 mm band therefore warns at roughly 190 to 250 mm in a fast flood. The partner city may want the first band lower for that reason.
- The TRL 2 figure of about 70 s typical and 110 s worst stands; the new 95th percentile is the figure R6 asks for.

## G. False readings (R10)

- **Tall objects.** A car roof (1.45 m), a van roof (2.00 m) and a person (1.75 m) under the head read as depths well above 600 mm and are rejected as out of range. A 0.5 m snow bank reads as 500 mm and needs the drain cross-check [G1].
- **Rules defined.** Reject depths above 600 mm; reject a step above 50 mm between 10 s samples unless the drain head is full or rising; require three consecutive readings above a band; subtract the dry-road background recorded at installation (A2); and flag a gauge that has been silent for 30 min [G2].
- **Status.** The rules cover the obvious cases, but the target (one false alert per gauge per year or fewer) can only be checked from a field log. R10 is not verifiable at TRL 3.

## H. Arm, brace, pole bracket and clamps (R15)

- **Load path (FLG-DDR-003).** The arm is held between two angle cleats on a 3 mm bracket plate that sits on the pole on two V-blocks and two band clamps 400 mm apart; a 25 x 25 x 1.6 mm brace is pinned between a clip under the arm and a clip on the plate, 358 mm between pins at 45°. The arm carries pull into the cleats and the brace pushes on the plate above the lower band.
- **Wind twist.** Wind along the street at 35 m/s puts 43.0 N on the arm, 6.2 N on the head and 13.4 N on the brace, twisting the arm about the pole with 24.8 N·m [H1]. Two band clamps at 1,000 N preload hold 36.0 N·m by friction, a factor of only 1.45 [H2]. A twisted arm moves the head along the street, not up or down, so it does not bias the depth.
- **Anti-rotation bolt.** The M8 A4-70 through-bolt now runs across the street through the bracket plate, a 20.2 mm spacer and both pole walls (a band clamp cannot take a bolt). It carries 15.4 kN in shear per plane; the pole wall bears 18.0 kN with an assumed 2.5 mm wall. Acting as a couple across the 60 mm pole it resists 922 N·m, a factor of 37 against the wind twist [H2b]. Drilling the pole needs the asset owner's permission.
- **Misuse.** A 50 kg person hanging on the head gives 181 N·m at the top brace pin and 60 MPa in the 1.6 mm arm wall against 214 MPa (factor 3.6); the brace carries 1,504 N against a buckling load of 73,043 N [H3]. The arm pulls on the cleats with 1,063 N, carried by the upper band against 2,000 N (factor 1.9), and 1,200 N of slip resistance holds 520 N down [H4].
- **Fixings.** M6 A4-70 bolts carry 8.4 kN per shear plane: the arm cleat joint (two bolts in double shear) holds 34 kN and the 1.6 mm arm walls 23.0 kN in bearing against the 1.06 kN pull; each brace pin in double shear holds 16.9 kN against 1.50 kN [H5].

## I. Mass on the pole (R15)

- **Items.** FieldNode 2.45 kg (its constructable design, FND-BLD-001); from the model: bracket plate 0.27 kg, V-blocks 0.14 kg, cleats 0.05 kg, brace clips 0.07 kg, arm 0.47 kg, brace 0.15 kg, head plate 0.08 kg, band clamps 0.04 kg, through-bolt and spacer 0.05 kg, M6 fixings, sleeves, pins and head screws 0.27 kg, marker plate 0.21 kg and its band clamps 0.06 kg; radar head 0.25 kg (assumed); street cable 0.21 kg (3 m); drain cable on the pole 0.22 kg [I1].
- **Total.** 4.99 kg against 5.0 kg, a margin of 0.01 kg (v0.3: 4.74 kg) [I2]. R15 is met on paper, with a margin within the accuracy of the estimate; the arm and brace walls went from 2.0 to 1.6 mm and the bracket plate has two windows to hold it. The riser guard and the three covers (2.00 kg) stand on the sidewalk and are not carried by the pole. Weighing the prototype is a TRL 4 check (FLG-DEC-001, open decision 3).

## J. Cables and ports (R11 context)

- **Street cable.** Measured along its real route on the model (from the head's side gland along the arm, down the pole outside the band clamps and up to port A under the FieldNode box), the run is 2,641 mm with the FieldNode centre at 3.4 m; with 300 mm of drip loops it fits a 3 m cable, and the I2C bus is about 350 pF against 400 pF [J1]. With the node at 3.0 m the same route needed 3.34 m with loops, which is why the node moved up (FLG-DDR-003, P6).
- **Drain cable.** Up through the grate opening, under the three covers, up the riser guard and the pole to port B, the run is 4,335 mm; with 500 mm of loops it fits the 5 m cable, which carries UART and the analog wet probe [J2].
- **Ports.** The street head uses port A at 3.3 V (I2C) and the drain head port B at 5 V (UART plus the analog pin), consistent with FieldNode's one switched rail per port [J3].

## K. Submersion (R9)

- Water 600 mm above the road puts 0.90 m (8.8 kPa) over the drain head face; R9 asks for 2.0 m (19.6 kPa) for 72 h, while the stock module is rated IP67 (1 m for 30 min) [K1]. The electronics can be potted, but the transducer face cannot be potted over, so its own seal decides. R9 is at risk until a longer immersion rating or a test shows otherwise.

## L. Installation (R12)

- **Surface work.** Traffic protection 10 min, the arm and bracket (assembled on the ground) lifted and clamped from a mobile platform 15 min, anti-rotation bolt 5 min, FieldNode and street head 15 min, marker 5 min, survey and dry background 10 min, grate lift 5 min, two wall anchors drilled through the grate opening 20 min, tube and head 10 min, the three covers, riser guard and marker clamps 25 min: 120 min in all [L1].
- **Cable route (FLG-DDR-002).** For pilots the drain cable comes up through the grate opening nearest the curb (FLG-DDR-003, P7) and runs under 0.76 m of bolted steel hat-section cover across the gutter strip, up the curb face and across the sidewalk to a riser guard at the pole. The anchors go into the curb and sidewalk only, none into the road [L2]. The conduit (coring the basin wall and a 0.50 m trench) is kept for permanent sites installed with road works.
- **R12 is met on paper for the pilot route:** 120 min with no civil work, against the 120 min that Amish set for the pilot surface route on 2026-10-02 (FLG-DEC-001, item 5); 90 min stays the target at permanent sites on the conduit route.

## M. Cost (R16)

- The BOM has 10 lines, all priced. Value-engineering target: USD 160. Estimated cost of the constructable design: USD 205.50 for the FloodGauge-specific parts (lines 2 to 10), USD 45.50 over the target; with the USD 139.00 FieldNode core (its constructable design), a complete gauge costs USD 344.50 [M1]. The pole bracket, cleats, clips, head plate and their fixings (line 3, USD 20.00 to 35.00), the three covers and riser guard (line 7, USD 14.00 to 26.00), the stand-off pipe clamps (line 5, USD 14.00 to 18.00), the marker band clamps (line 8, USD 6.00 to 10.00) and the drain head socket (line 4, USD 22.50 to 24.50) account for the rise from USD 153.50. The main cost drivers are the radar head, the arm and bracket, the covers and the drain head [M2]. R16 is reported against the value-engineering target; savings worth trying are listed in FLG-DEC-001. Radar module, housing and cover prices are indicative.
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

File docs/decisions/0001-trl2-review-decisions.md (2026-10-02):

---
doc_id: FLG-DDR-001
title: FloodGauge TRL 2 review decisions
project: FloodGauge
doc_type: Design decision record
version: "0.3"
status: Draft
date: '2026-10-02'
author: Amish Chadha
license: CERN-OHL-S-2.0
revisions:
- version: "0.1"
  date: '2026-09-25'
  author: Amish Chadha
  change: Record the TRL 2 review items adopted as recommended for TRL 3 work, open for Amish's review, and the items that remain open
- version: "0.2"
  date: '2026-09-25'
  author: Amish Chadha
  change: Recommendations accepted by Amish (DDR-002)
- version: "0.3"
  date: '2026-10-02'
  author: Amish Chadha
  change: "O1 decided by Amish on 2026-10-02 (FLG-DEC-001, item 6)"
---

# 0001: TRL 2 review decisions

- **Date:** 2026-09-25
- **Status:** accepted. On 2026-09-25 Amish wrote "i accept all your recommendations, go with them across all repos", so items D1 to D9 are "Decided by Amish, 2026-09-25: go with recommendation" (recorded in FLG-DDR-002). Item O1 had no recommendation at this record; it was decided by Amish on 2026-10-02 (FLG-DEC-001, item 6): "i approve your recommendations for all 555 open decisions."
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

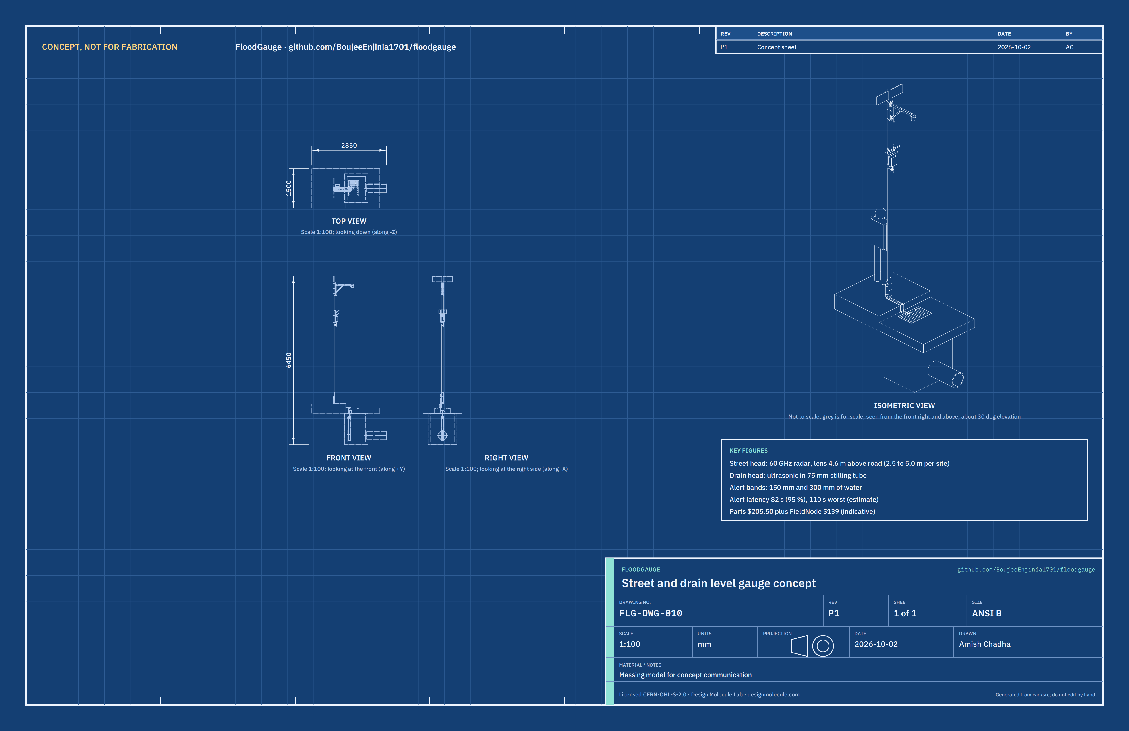
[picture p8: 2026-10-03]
media/concept-blueprint.png

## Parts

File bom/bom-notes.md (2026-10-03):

# BOM notes

- Costs are indicative, at quantity 1, in USD. Every line is priced; supplier types are given where no supplier is chosen. Only the A02YYUW list price ($15.90, DFRobot product page) was checked on 2026-09-25; the radar module and housing prices are not verified.
- Item numbers 1 to 8 match the callouts in `media/exploded.png` and the parts in `cad/src/model.py`. Items 9 and 10 are not modeled.
- Under FLG-DDR-001 D1 (decided by Amish, 2026-09-25), the FieldNode core is costed in the FieldNode repo ($139.00 for its constructable design) and R16 covers FloodGauge-specific parts only. Line 1 stays in this BOM for the complete-gauge total.
- Value-engineering target (`budget_usd`, a hypothetical control target set by Amish, not a limit): $160. Estimated cost of the constructable design: $205.50 for FloodGauge-specific parts (lines 2 to 10), $45.50 over the target. Complete gauge with the $139.00 FieldNode core (its constructable design, FND-DDR-003): $344.50. Both are printed by `docs/04-calcs/sizing.py` [M1]; cost drivers and savings worth trying are in FLG-DEC-001.
- Changes under FLG-DDR-003 (design for construction, 2026-10-01, accepted by Amish on 2026-10-02): line 3 adds the pole bracket plate, V-blocks, cleats, brace clips, head plate and their fixings ($20.00 to $35.00); line 4 adds a 75 mm socket ($22.50 to $24.50); line 5 swaps the wall brackets for stand-off pipe clamps ($14.00 to $18.00); line 7 becomes three hat-section covers and a U-channel riser guard ($14.00 to $26.00); line 8 adds two band clamps and is 2 mm ($6.00 to $10.00); line 1 follows FieldNode's constructable design ($126.00 to $139.00).
- Changes under FLG-DDR-002 (decided by Amish, 2026-09-25): line 7 is now the pilot surface cable cover and riser guard ($14.00, was the $8.00 conduit); line 3 gains an M8 anti-rotation through-bolt ($18.00 to $20.00); line 6 street cable 2 m to 3 m at the same indicative price. The conduit route (about $8 plus civil work) stays the option for permanent sites and is not in the total.
- Fixings within reach of the sidewalk (marker bands, covers, riser guard and anchors) are tamper-resistant screw heads and nuts for the pilot (decided by Amish, 2026-10-02, FLG-DEC-001 item 12). Repriced on 2026-10-02: line 7 $26.00 to $32.00 (eight snake-eye two-hole security nuts and washers, about $0.75 each); line 8 $10.00 to $13.00 (pin-Torx TR25 security screws for the two band clamps, about $3 for the pair); line 10 $6.00 to $12.00 (one snake-eye spanner bit and one TR25 pin-Torx bit, about $6 for the two). Prices are indicative catalogue figures, not quotes. Cost against the target went from $30.50 over to $45.50 over.
- Drain cable slack loop (decided 2026-10-02): the 0.5 m loop in the basin is tied to the upper pipe clamp with two UV-stable cable ties from the existing line 7 and line 10 allowances (about $0.05 each); no price change.
- Change from TRL 2: a 10 kΩ NTC ($0.50) added to the drain head for speed-of-sound compensation (FLG-CAL-001, C2).
- Not included: the LoRaWAN gateway, installation labor, a mobile elevating platform, traffic management and any permits.
- A street-only variant with an ultrasonic street head and no drain parts would cost about $188 (TRL 2 estimate, not rechecked) and misses R2.

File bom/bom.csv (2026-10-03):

item | qty | spec | supplier | unit_cost_usd | make_buy | notes
1 FieldNode core | 1 | Lab shared node built to the FieldNode build plan FND-BLD-001: IP65 polycarbonate enclosure 150 x 90 x 200 mm on an aluminium back plate with two V-blocks and two band clamps (bands sized for a 60 mm pole), 6 W panel on its bracket, 6 Ah LiFePO4, charger and protection modules, STM32WL-class LoRaWAN module, two M12 5-pin ports | Built from the FieldNode BOM (FieldNode repo) | 139.00 | make | Shared component costed in the FieldNode repo (FND-DDR-003: base node $139.00); excluded from the FloodGauge-specific total under R16
2 Street radar head | 1 | 60 GHz pulsed coherent radar module (Acconeer XM125 class, I2C) on a carrier board, round IP67 housing 76 mm x 84 mm with four lid bosses, PTFE lens disc 60 x 6 mm sealed over a 46 mm window with three M3 screws, M12 cable gland on the side | Electronics distributor (module); plastics supplier (housing and lens) | 55.00 | buy | Indicative: module about $43 plus housing and lens about $12; price and data sheet figures not verified
3 Sensor arm and pole bracket | 1 | Aluminium: square tube 40 x 40 x 1.6 mm 715 mm (arm) and 25 x 25 x 1.6 mm 382 mm (knee brace); plate 3 mm 100 x 450 mm (pole bracket) and 140 x 70 mm (head plate); flat bar 60 x 40 mm for two V-blocks; angle 30 x 30 x 3 mm 120 mm (two cleats); strip 3 mm for two brace clips; spacer tube 12 mm OD. Two stainless worm-drive band clamps 12 mm for a 60 mm pole (about 330 to 380 mm round). M8 x 100 mm A4 through-bolt with nyloc nut and washers; M6 A4 bolts and nyloc nuts (14), crush sleeves, M4 countersunk screws (8), arm end cap | Metal stockist and hardware store | 35.00 | make | Indicative. Was $20.00 for the concept arm; the pole bracket, V-blocks, cleats, clips, head plate and their fixings added under FLG-DDR-003
4 Drain head | 1 | Waterproof ultrasonic ranger (DFRobot A02YYUW: 3 to 450 cm, ±1 cm, IP67, UART), 10 kΩ NTC for air temperature, two-electrode wet probe, potting compound, sealed 104 mm cap with a top cable gland, 75 mm PVC socket coupling and two stainless screws | DFRobot or electronics distributor | 24.50 | buy | Sensor $15.90 list price (DFRobot product page; checked 2026-09-25); NTC $0.50; probe potting and cap about $6 indicative; socket and screws $2.00 added under FLG-DDR-003
5 Stilling tube and pipe clamps | 1 | 75 mm OD PVC pipe 940 mm, 40 slots 5 x 50 mm in 10 rows; two stainless stand-off pipe clamps for 75 mm pipe with M8 rod, wall plate and stainless wall anchor | Plumbing supplier | 18.00 | make | Indicative; slots cut with a hand saw or router; was $14.00 with brackets set into the wall (FLG-DDR-003)
6 Sensor cables | 2 | Outdoor 5-core cable about 10 mm with M12 5-pin plug: 3 m (street head, I2C) and 5 m (drain head) | Electronics distributor | 8.00 | buy | Indicative; one of each length
7 Surface cable covers and riser guard | 1 | Pilot route (FLG-DDR-002, FLG-DDR-003): three hat-section covers bent from 2 mm galvanized steel strip 84 mm wide, 16 mm high (gutter 185 mm, curb face 166 mm, sidewalk 429 mm, about 0.78 m in all); riser guard 40 x 65 mm U channel 300 mm from 2 mm galvanized steel; eight M8 stainless masonry anchors with snake-eye (two-hole) security nuts and washers; UV-stable cable ties | Metal stockist and hardware store | 32.00 | make | Indicative (security nuts add $6: eight at about $0.75); anchors in the curb and sidewalk only. Was $14.00 for a steel angle cover. Permanent sites use the 25 mm conduit route instead (about $8 plus civil work, not in this total)
8 Depth marker plate | 1 | Aluminium plate 90 x 435 x 2 mm with amber (to 300 mm) and red (300 to 450 mm) reflective bands above road level; two stainless worm-drive band clamps 12 mm (about 450 mm round) with pin-Torx TR25 security screws that also hold the riser guard | Sign maker or self | 13.00 | make | Indicative (security screws add about $3 for the pair); was $6.00 for a 3 mm plate with no fixing (FLG-DDR-003)
9 Alert service | 1 | Open alert software on the gateway or a small server (MIT) | Self | 0.00 | make | Software only; the gateway (TwinKit or a city network) is not included
10 Fasteners and consumables | 1 | Stainless screws, cable ties, sealant, threadlocker, labels; one snake-eye spanner bit for the M8 security nuts and one TR25 pin-Torx bit for the band clamp screws | Hardware store | 12.00 | buy | Indicative (the two security bits add about $6)

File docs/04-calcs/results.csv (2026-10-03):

id | value | target | status
R1 | lens 4.60 m clears a 4.3 m vehicle; range 1.9 to 5.0 m over the band; module to 20 m | 0 to 600 mm; head 2.5 to 5.0 m per site | Met on paper
R2 | radar RSS ±6.5 mm, sum ±12.0 mm; ultrasonic variant ±27.0 mm | ±10 mm | Met on paper (module accuracy assumed)
R3 | continuous -1250 to -330 mm; wet probe at -310 mm | 50 mm above floor to 330 mm below road, drain-full above | Met on paper
R4 | ±11.0 mm with NTC; ±19.7 mm without | ±20 mm | Met on paper
R5 | 60 s and 10 s schedule set in the sampling logic | 60 s; 10 s in events | Met by design
R6 | worst 110 s without packet loss | 120 s, 95 % of events | Met on paper (private gateway)
R7 | SF9 23.7 s/day; event 1 % met SF7 to SF10, not SF11 or SF12 | 1 % always; TTN 30 s/day normal | At risk
R8 | 68 days nominal, 47 days at -20 C | 5 days at event sampling | Met on paper
R9 | potted head; transducer face seal IP67 only | IP68, 2 m, 72 h | At risk
R10 | rules defined; curb echo needs a recorded background | 1 false alert per year or fewer | Not verifiable at TRL 3
R11 | levels, status and battery only | no camera or microphone | Met by design
R12 | 120 min on the surface route; no civil work | 120 min for the pilot surface route, no basin entry (90 min at permanent sites on the conduit route) | Met on paper
R13 | tape and radar dry-background survey; yearly marker check | ±5 mm | Met on paper
R14 | FieldNode R2/R3 heat (inherited); A02YYUW rated -15 to 60 C | -20 to 50 C | At risk
R15 | 4.99 kg; twist factor 37 with the through-bolt | 40 to 60 mm poles; 5 kg | Met on paper
R16 | $205.50 FloodGauge-specific; $344.50 with FieldNode | $160 FloodGauge-specific (value-engineering target) | Over the value-engineering target by $45.50
R17 | JSON or CSV through the gateway | open format | Met by design

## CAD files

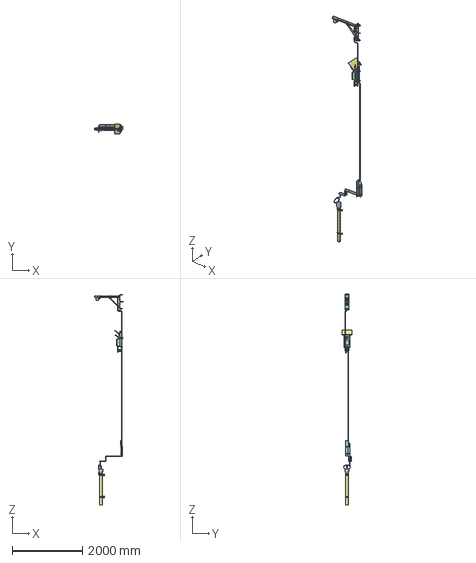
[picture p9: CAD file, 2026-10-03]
cad/step/floodgauge-assembly.step
816.8 x 290.0 x 6028.0 mm

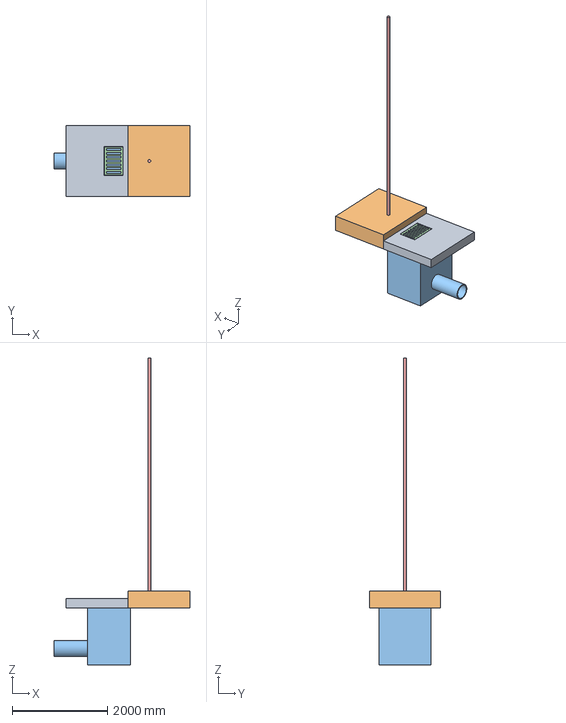
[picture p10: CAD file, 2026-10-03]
cad/step/floodgauge-site.step
2850.0 x 1500.0 x 6450.0 mm

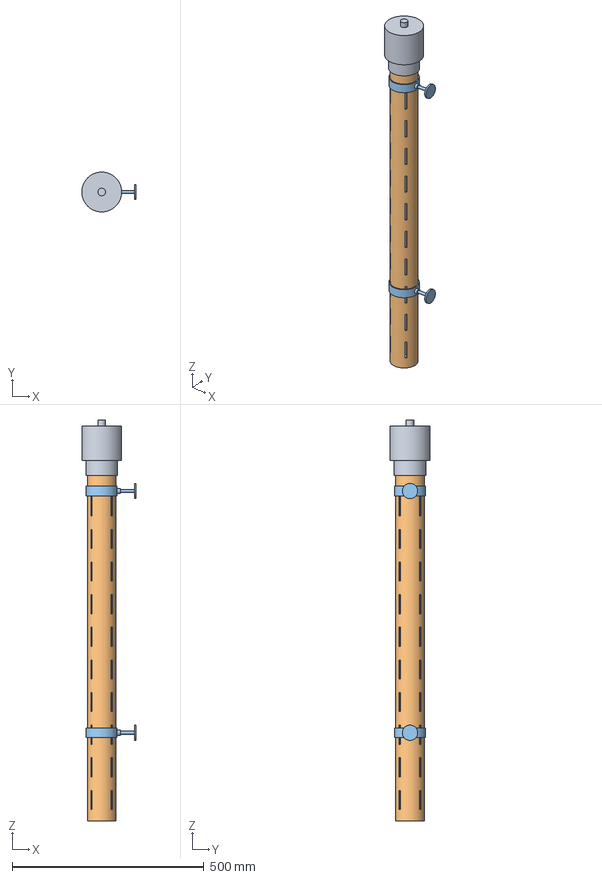
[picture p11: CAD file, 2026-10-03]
cad/step/floodgauge-drain-kit.step
141.9 x 104.0 x 1045.0 mm

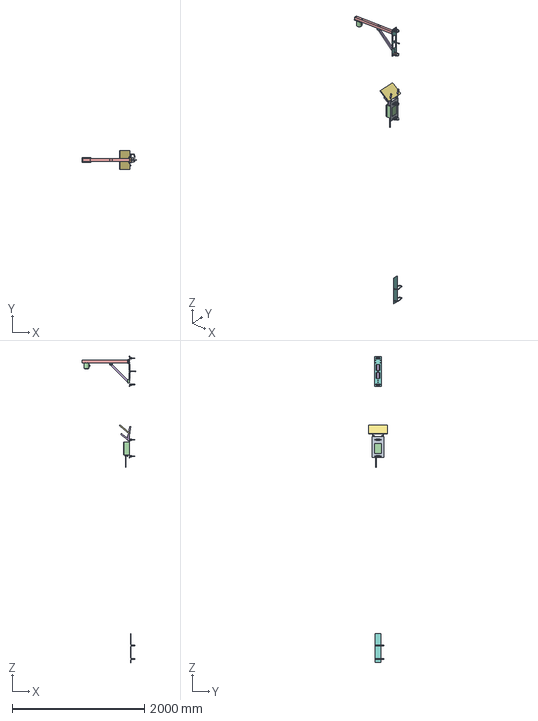
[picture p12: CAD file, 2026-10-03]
cad/step/floodgauge-pole-kit.step
816.8 x 290.0 x 4623.0 mm

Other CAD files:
cad/stl/floodgauge-assembly.stl
cad/stl/floodgauge-drain-kit.stl
cad/stl/floodgauge-pole-kit.stl
cad/stl/floodgauge-site.stl

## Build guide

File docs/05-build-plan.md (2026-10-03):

---
doc_id: FLG-BLD-001
title: FloodGauge prototype build plan
project: FloodGauge
doc_type: Build plan
version: "0.3"
status: Draft
date: '2026-10-02'
author: Amish Chadha
license: CERN-OHL-S-2.0
revisions:
  - version: "0.1"
    date: '2026-10-01'
    author: Amish Chadha
    change: First build plan; design made constructable (FLG-DDR-003)
  - version: "0.2"
    date: '2026-10-02'
    author: Amish Chadha
    change: "FLG-DDR-003 recorded as accepted and the R12 acceptance figure set to the 120 min pilot target, both decided by Amish on 2026-10-02 (FLG-DEC-001, items 1 and 5)"
  - version: "0.3"
    date: '2026-10-02'
    author: Amish Chadha
    change: "Approved follow-ups carried in: drain cable slack loop tied to the stilling tube clamp (new Figure 22 and step 13), tamper-resistant fixings named in the tools, bought parts and steps, grate lifting for cleaning, cost updated"
---

# FloodGauge prototype build plan

**Plan, not yet built.** How to build the first proof-of-concept prototype, component by component. Building and testing to it is TRL 4 work. Decisions still to be made are kept in the design decisions register ([docs/06-design-decisions.md](06-design-decisions.md)), not here.

## 1. What you are building

Figure 1. Every component, laid out and numbered in build order

*Figure 1. Every component, numbered in build order; one of each pair is shown.*

The prototype is one FloodGauge on a street pole beside a storm inlet. A radar head hangs from an aluminium arm over the gutter, 4.6 m above the road; the arm is bolted to a bracket plate that clamps to the pole. A FieldNode core, built to its own plan (FND-BLD-001), sits on the pole 3.4 m up and does the sensing, power and radio. In the catch basin, a slotted plastic tube hangs on two pipe clamps with an ultrasonic drain head on top, and its cable comes up through the grate and runs under three bolted steel covers to the pole. A depth marker plate and a riser guard sit at the foot of the pole. Figure 1 shows the 21 components: 16 are made in a small workshop (aluminium plate, bar, angle and tube cut, drilled and folded; steel strip folded; PVC pipe slotted; two heads assembled from bought parts), and the rest are bought or built to the FieldNode plan. The FloodGauge-specific parts cost about $205.50 from the bill of materials.

> **Safety:** The installation is work beside live traffic, at height on a pole and over an open catch basin. Never enter a catch basin: it can hold toxic or oxygen-poor air and fast-rising water. The arm goes up from a mobile elevating platform with a second person, clear of overhead lines. Stormwater carries sewage and chemicals: wear gloves and eye protection. The FieldNode holds a lithium iron phosphate cell of about 19 Wh: follow the FieldNode plan's safety stops. Cut aluminium and steel edges are sharp; deburr everything. FloodGauge supplements official warnings and is never the only one.

## 2. What changed to make it buildable

The concept showed what the gauge does; some of its parts passed through each other or had no fixing. Each change below keeps what the gauge does, and all of them are recorded in decision record FLG-DDR-003, accepted by Amish on 2026-10-02.

*Table 1. Changes from the concept.*

| Component | The concept had | The buildable design has | Why |
| --- | --- | --- | --- |
| Arm to pole | An arm that ran through the pole, inside two plain rings | A bracket plate on two V-blocks and two band clamps; the arm held between two angle cleats on the plate (Figures 2, 4, 6) | The arm and the pole no longer occupy the same space, and the clamps can be tightened |
| Knee brace | A brace touching the arm and floating at the pole end | A brace pinned in two folded clips, one under the arm and one on the plate (Figures 10, 11) | Each end has a fixing |
| Anti-rotation bolt | An M8 bolt through a band clamp, along the street | An M8 bolt across the street through the plate, a spacer and the pole (Figure 11) | A band clamp cannot take a bolt |
| Radar head fixing | A block that sat inside the head | A head plate under the arm; the housing hangs from it on four screws (Figure 13) | The block and the head occupied the same space |
| Street cable | Straight up from the head through the arm | A side gland; the cable runs along the arm and down the pole (step 10) | The cable passed through the arm |
| FieldNode | A box on a thick plate with no fixing, at 3.0 m | The FieldNode as built to its own plan, at 3.4 m (step 7) | Its fixing; and the street cable fits its 3 m length on the real route |
| Drain cable exit | Out between the grate and its frame | Up through the grate opening nearest the curb (Figure 25) | The 5 mm gap cannot pass a 10 mm cable |
| Surface cover | An angle with no fixing; a riser guard 250 mm from the pole | Three bolted hat-section covers and a riser guard strapped to the pole (Figures 17, 24) | Every piece has a fixing and the cable is covered all the way |
| Stilling tube | Brackets set into the basin wall | Two stand-off pipe clamps (Figure 21) | Bought, adjustable, fitted from the surface |
| Drain head | Resting on the tube | A socket under the head that slides over the tube, two screws (Figure 21) | It cannot fall off, and it lifts off for cleaning |
| Depth marker | A 3 mm plate with no fixing, from the sidewalk up | A 2 mm plate from 15 mm above the sidewalk, on two band clamps (Figure 17) | The cover passes under it; saves weight |
| Arm and brace walls | 2.0 mm | 1.6 mm, with two windows in the bracket plate | Keeps the mass on the pole under 5 kg after the added parts |

## 3. Making the components

Make and check each component before the assembly step that needs it. Sizes are in millimetres. "Toward the road" and "toward the pole" describe where each face ends up. Workshop tolerance is 0.5 mm unless a step says otherwise; drawings do not carry tolerances before TRL 4.

### 3.1 Pole bracket plate

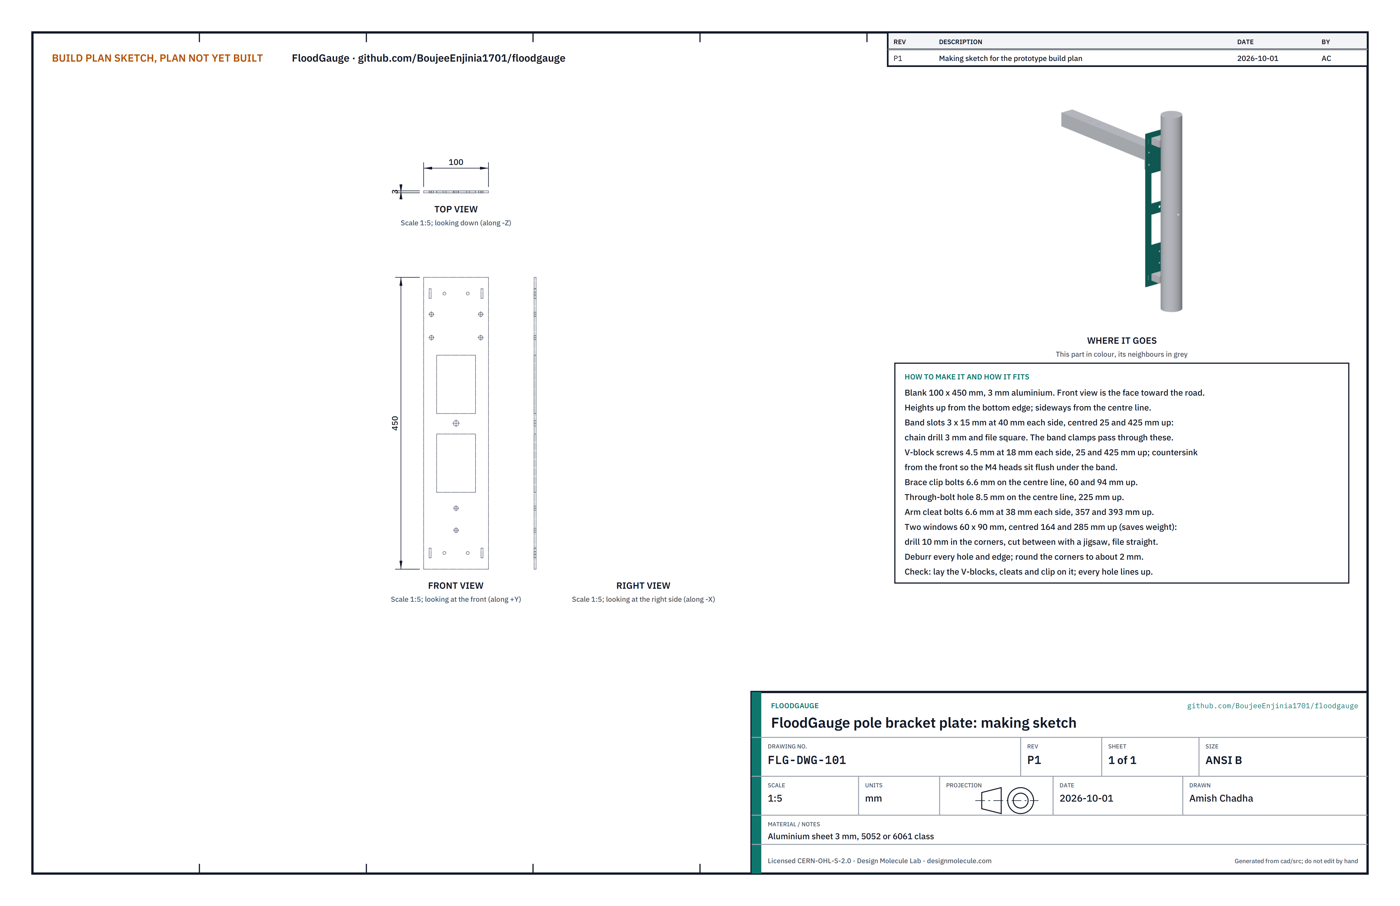
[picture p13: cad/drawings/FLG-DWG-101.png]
Figure 2. Making sketch of the pole bracket plate


*Figure 2. Pole bracket plate making sketch (FLG-DWG-101).*

**What it is and what it is made from.** The flat plate that carries the arm and brace and clamps to the pole. Aluminium sheet 3 mm thick, 5052 or 6061 class, 100 x 450 mm.

**How to make it.**

1. Cut the blank 100 x 450 mm, square. Scribe a centre line down its length. Choose one face as the front (toward the road).
2. Measure every height up from the bottom edge and every sideways position from the centre line.
3. Band slots: four slots 3 wide and 15 tall, 40 each side of centre, centred 25 and 425 up. Chain drill 3 mm and file square.
4. V-block screw holes: four 4.5 mm holes, 18 each side of centre, 25 and 425 up. Countersink them from the front so the M4 heads sit flush.
5. Brace clip holes: two 6.6 mm holes on the centre line, 60 and 94 up.
6. Through-bolt hole: one 8.5 mm hole on the centre line, 225 up.
7. Arm cleat holes: four 6.6 mm holes, 38 each side of centre, 357 and 393 up.
8. Windows: two 60 x 90 mm windows on the centre line, centred 164 and 285 up. Drill 10 mm in each corner, cut between with a jigsaw and a metal blade, file straight.
9. Deburr every hole and edge and round the corners to about 2 mm.

**How it fits the parts next to it.** The V-blocks sit flat on its back at the two band heights (Figure 4); the cleats and the foot clip sit flat on its front (Figures 6 and 11); the band clamps pass through its slots and across its front; the through-bolt passes its centre hole.

**Check before moving on.** Lay the V-blocks, cleats and a clip on it and look through each hole: every hole lines up without forcing a bolt.

### 3.2 V-blocks (make 2)

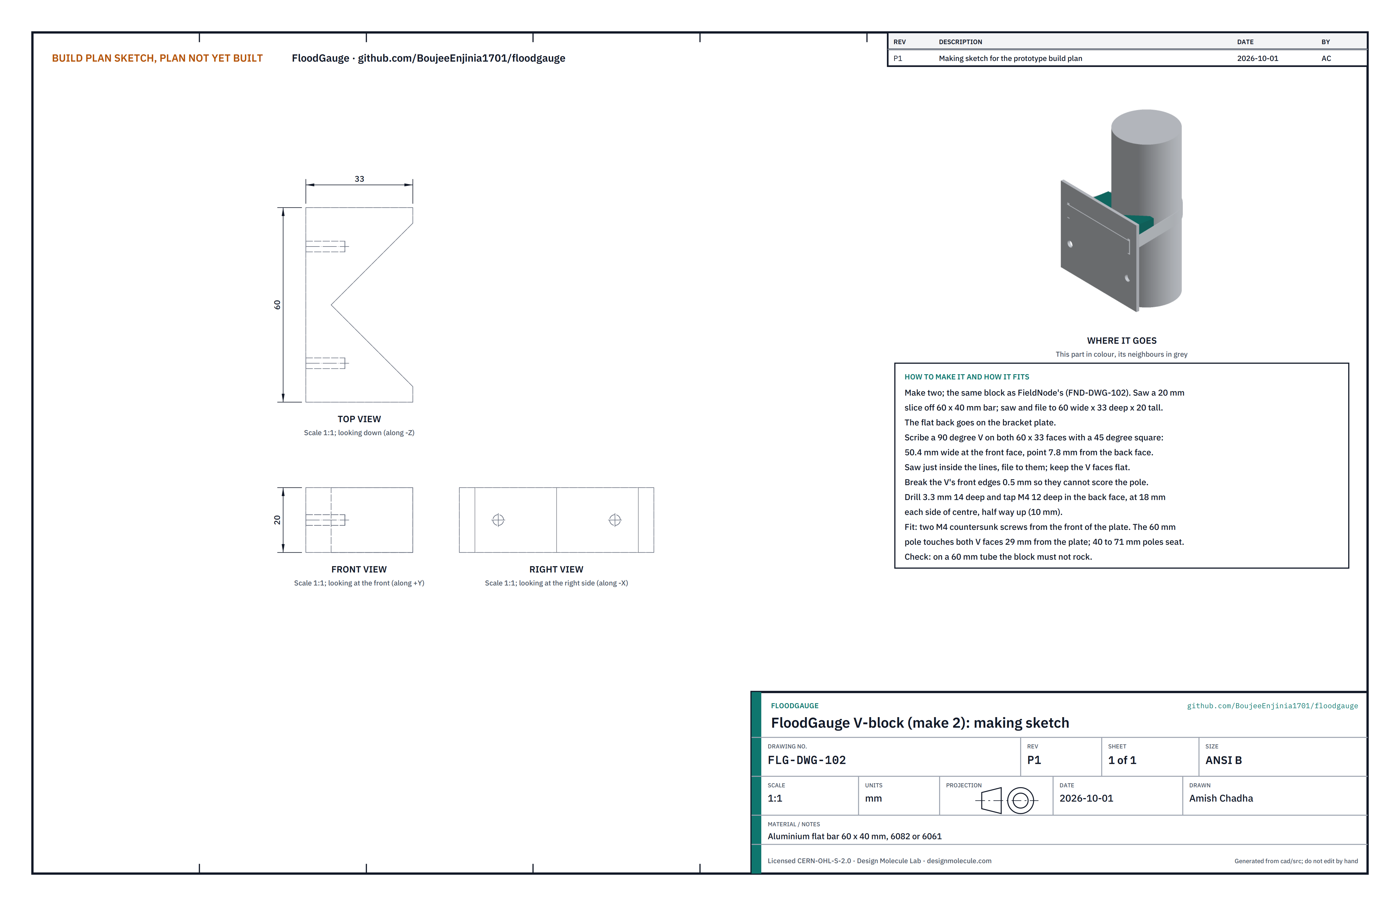
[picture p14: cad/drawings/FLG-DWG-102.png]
Figure 3. Making sketch of the V-block


*Figure 3. V-block making sketch (FLG-DWG-102). The same block as FieldNode's.*

**What it is and what it is made from.** A block with a V cut in it that seats the round pole, one at each band clamp. Aluminium flat bar 60 x 40 mm, 6082 or 6061 class.

**How to make it.**

1. Saw two slices 20 thick off the bar; saw and file each to 60 wide, 33 deep and 20 tall. The 60 x 20 face that sits on the plate is the back face; file it flat.
2. On each 60 x 33 face, scribe the V with a 45° square: two lines 50.4 apart at the front face, meeting 7.8 from the back face, centred.
3. Saw just inside the lines and file to them; keep both V faces flat and square.
4. Break the V's front edges by 0.5 mm.
5. In the back face, 18 each side of centre and 10 up, drill 3.3 mm 14 deep and tap M4 12 deep.

**How it fits the parts next to it.**

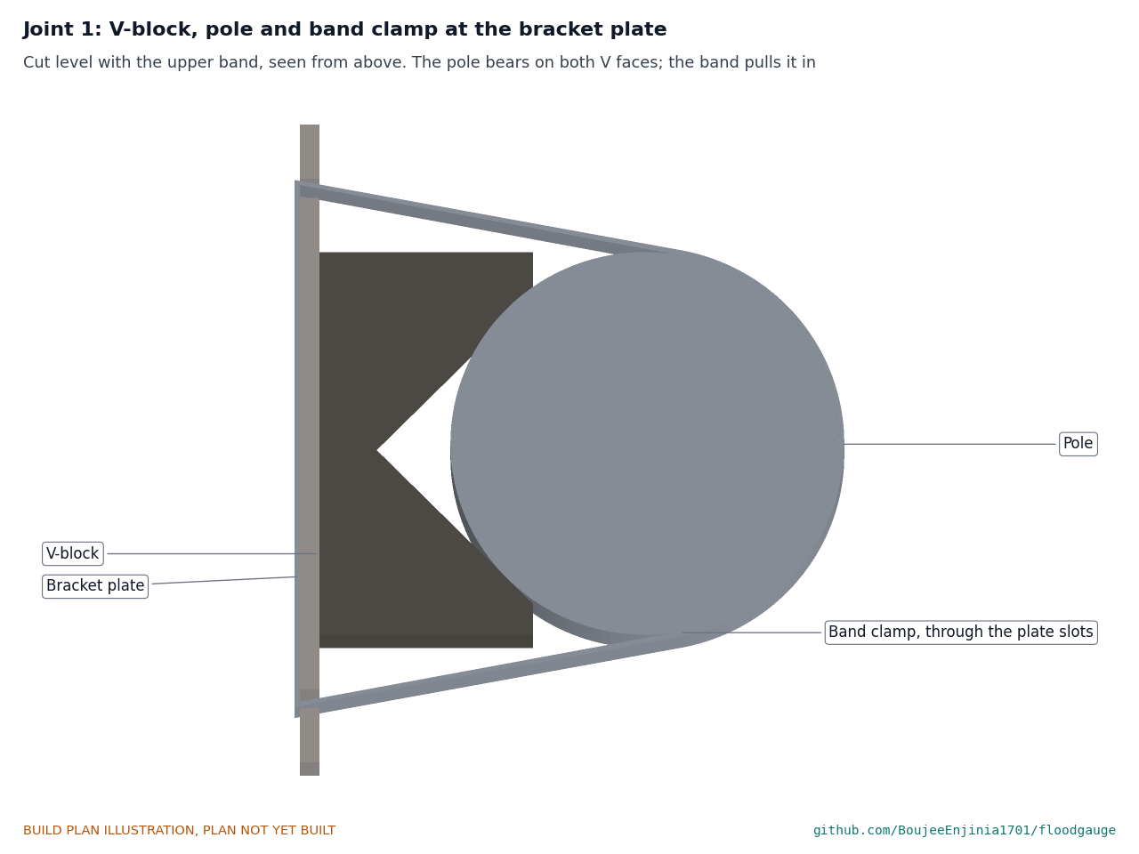
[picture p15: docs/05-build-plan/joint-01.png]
Figure 4. Joint 1: V-block, pole and band clamp


*Figure 4. The pole bears on both faces of the V; the band clamp goes round the pole, through the plate slots and across the plate front, and pulls the pole into the V.*

The back face sits flat on the back of the plate, held by two M4 countersunk screws from the front of the plate with medium threadlocker. The 60 mm pole touches both V faces 29 mm from the plate and never the bottom of the V. Poles from 40 to 71 mm also seat on both faces. The band passes 3 mm clear of the block's corners.

**Check before moving on.** Held against a 60 mm tube, the block does not rock; light shows at the bottom of the V but not along its faces.

### 3.3 Arm cleats (make 2, a left and a right)

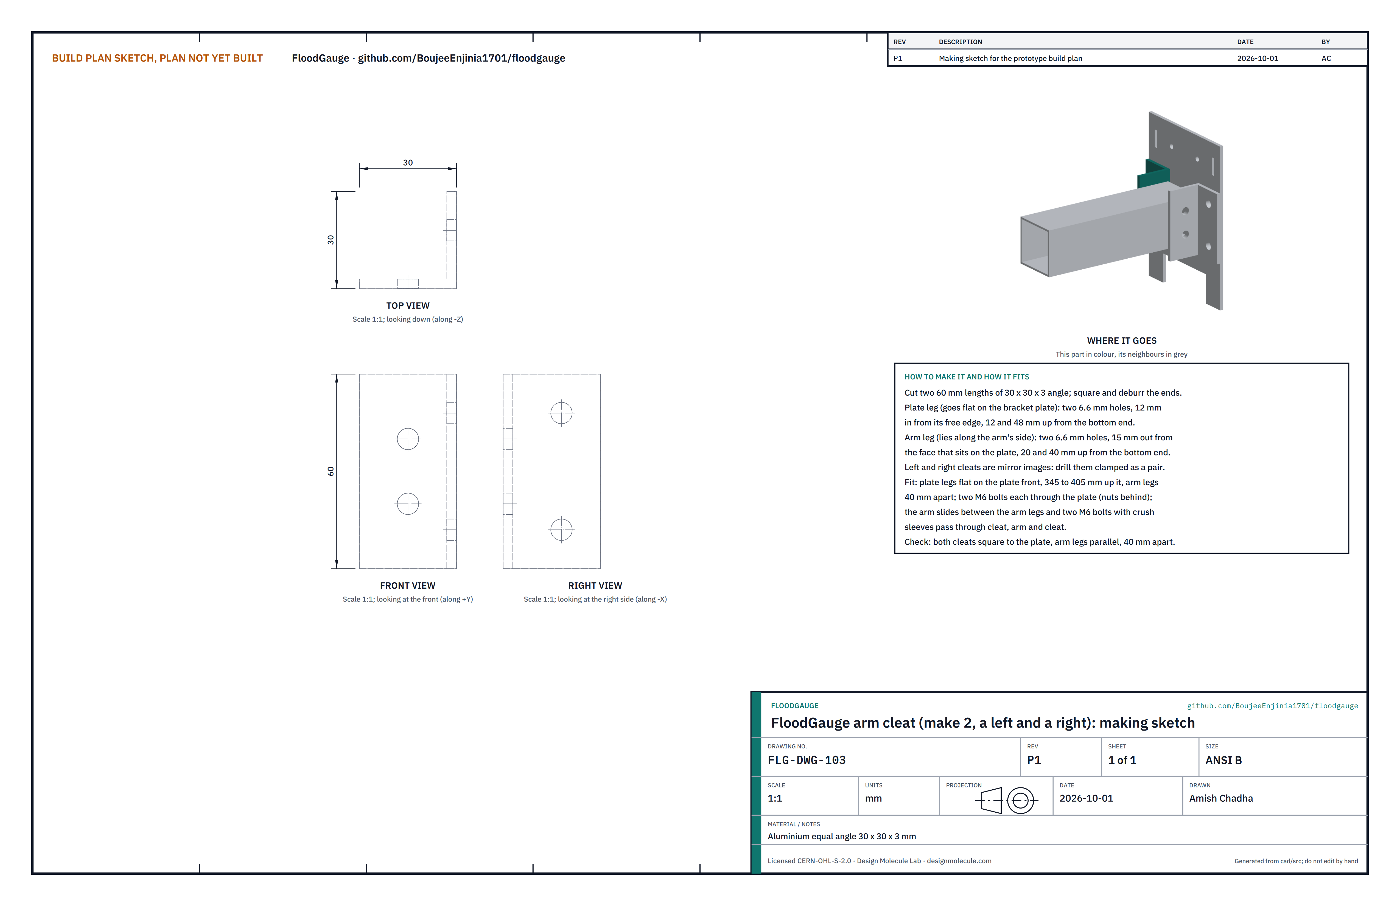
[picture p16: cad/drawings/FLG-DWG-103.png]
Figure 5. Making sketch of the arm cleat


*Figure 5. Arm cleat making sketch (FLG-DWG-103).*

**What it is and what it is made from.** A short angle on each side of the arm that joins it to the bracket plate. Aluminium equal angle 30 x 30 x 3 mm.

**How to make it.**

1. Cut two 60 lengths; square and deburr the ends.
2. Plate leg: two 6.6 mm holes, 12 in from the leg's free edge, 12 and 48 up from the bottom end.
3. Arm leg: two 6.6 mm holes, 15 out from the face that sits on the plate, 20 and 40 up from the bottom end.
4. The two cleats are mirror images: clamp them back to back and drill them together.

**How it fits the parts next to it.**

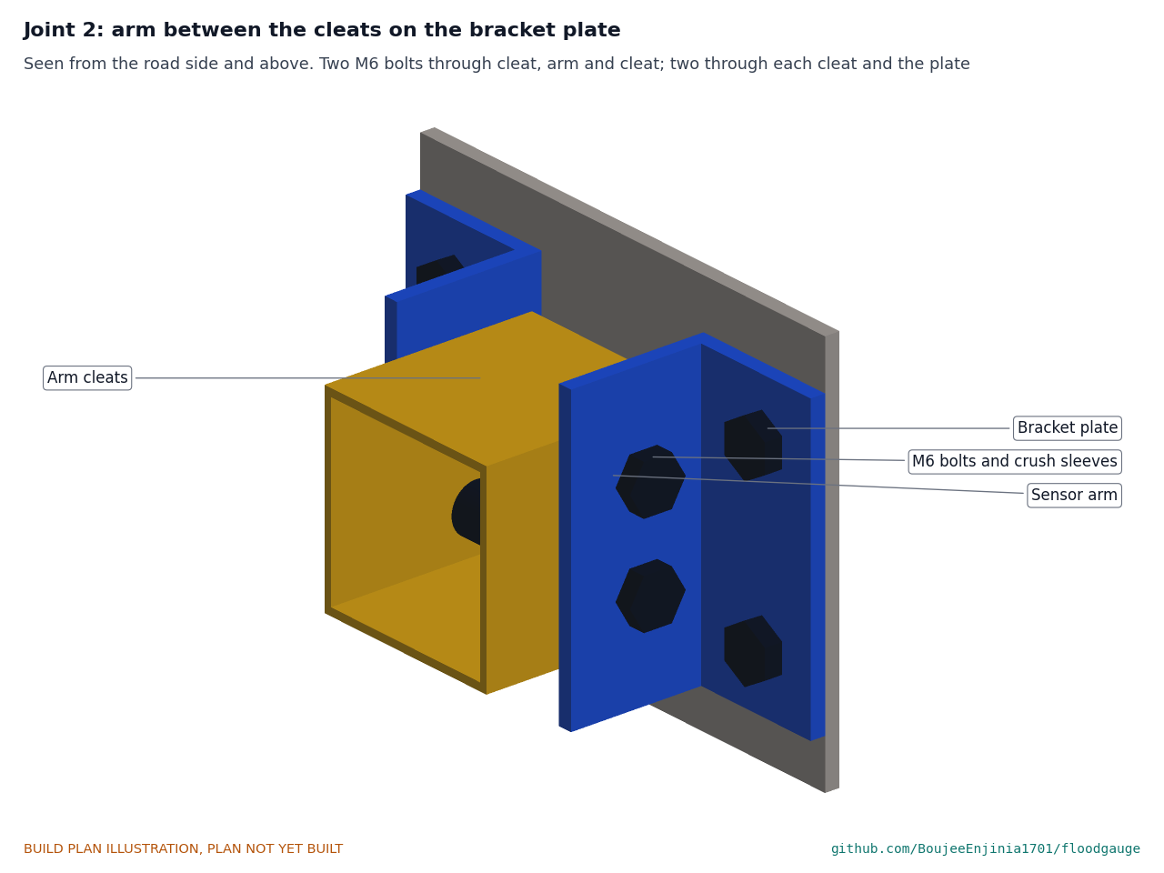
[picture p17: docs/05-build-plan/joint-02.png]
Figure 6. Joint 2: arm between the cleats


*Figure 6. The arm end sits between the two arm legs, 2 mm short of the plate; four M6 bolts hold the cleats to the plate and two M6 bolts with crush sleeves pass through cleat, arm and cleat.*

The plate legs lie flat on the front of the bracket plate, 345 to 405 up it, with the arm legs standing forward 40 apart. Two M6 bolts per cleat through the plate, nyloc nuts behind.

**Check before moving on.** Both arm legs are square to the plate and 40 apart along their whole length.

### 3.4 Brace clips (make 2)

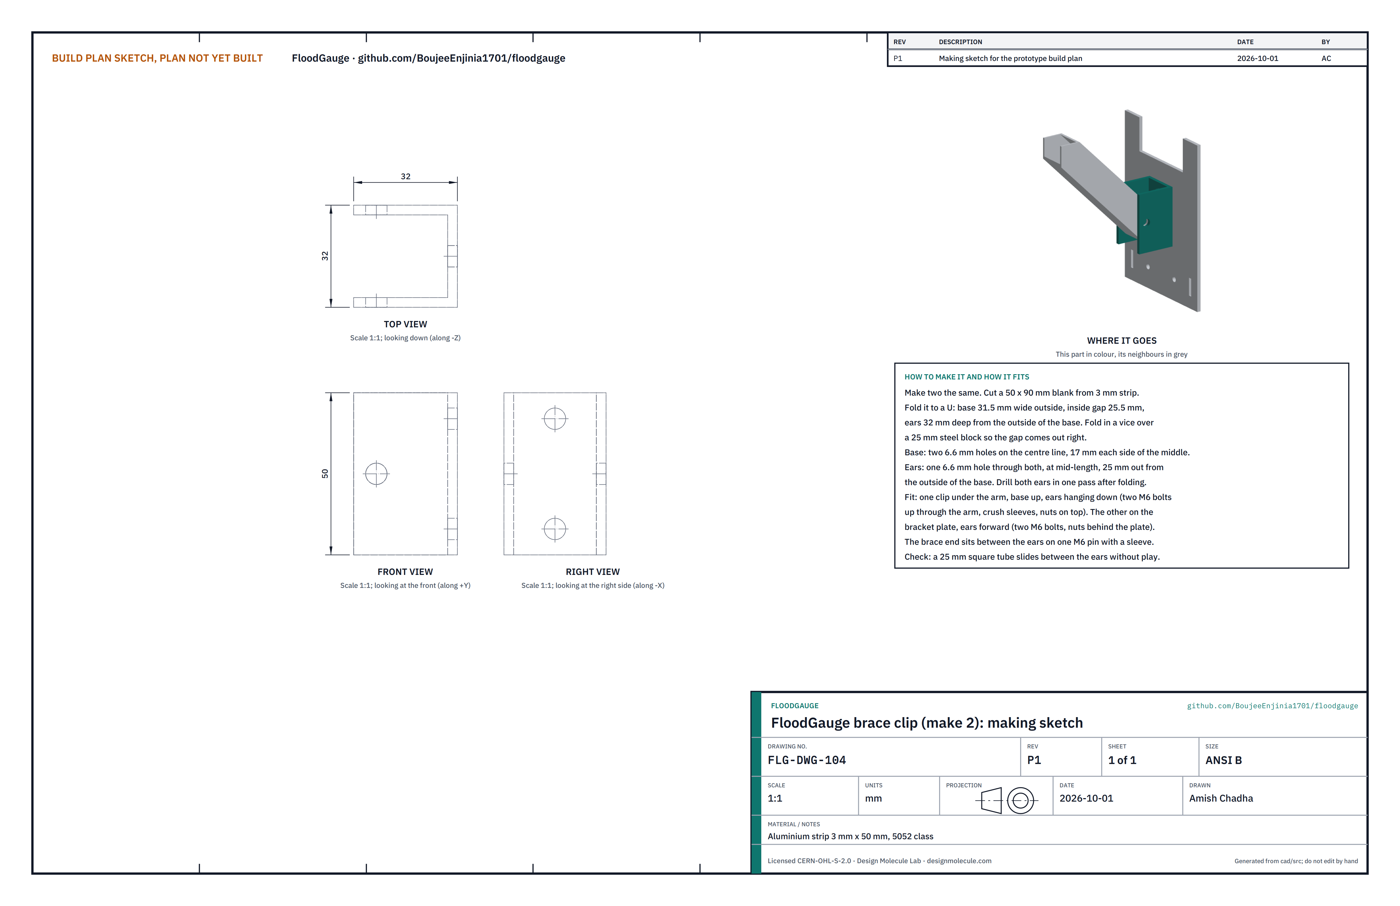
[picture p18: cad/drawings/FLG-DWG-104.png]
Figure 7. Making sketch of the brace clip


*Figure 7. Brace clip making sketch (FLG-DWG-104).*

**What it is and what it is made from.** A folded U that holds one end of the knee brace on a pin. Aluminium strip 3 mm, 50 wide.

**How to make it.**

1. Cut two 50 x 90 blanks.
2. Fold each to a U over a 25 mm steel block in the vice: inside gap 25.5, base 31.5 wide outside, ears 32 deep measured from the outside of the base.
3. Base: two 6.6 mm holes on the centre line, 17 each side of the middle.
4. Ears: one 6.6 mm hole through both, at mid-length, 25 out from the outside of the base. Drill both ears in one pass after folding so the holes line up.

**How it fits the parts next to it.** One clip goes under the arm with its ears hanging down; two M6 button-head bolts go up from inside the clip through the arm (crush sleeves inside), nyloc nuts on top (Figure 10). The other goes on the bracket plate with its ears pointing toward the road; two M6 button-head bolts through the plate, nuts behind (Figure 11). The brace end sits between the ears on one M6 pin with a sleeve.

**Check before moving on.** A 25 mm square tube slides between the ears without play.

### 3.5 Sensor arm

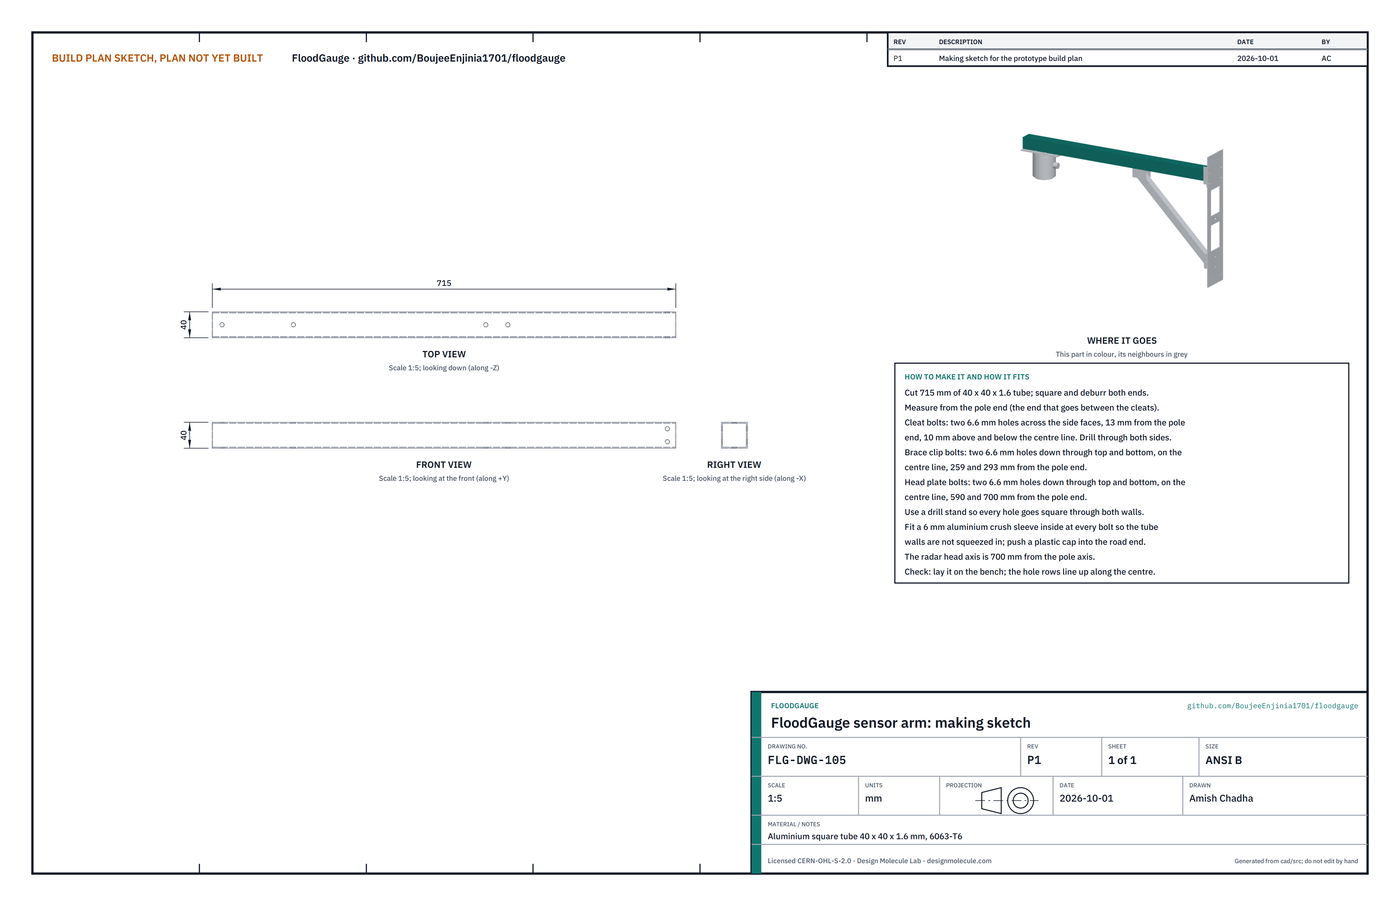
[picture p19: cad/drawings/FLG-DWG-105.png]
Figure 8. Making sketch of the sensor arm


*Figure 8. Sensor arm making sketch (FLG-DWG-105).*

**What it is and what it is made from.** The horizontal arm that holds the radar head over the gutter. Aluminium square tube 40 x 40 x 1.6 mm, 6063-T6.

**How to make it.**

1. Cut 715 of tube; square and deburr both ends. Measure from the pole end.
2. Cleat bolts: two 6.6 mm holes through both side faces, 13 from the pole end, 10 above and below the centre line.
3. Brace clip bolts: two 6.6 mm holes down through top and bottom on the centre line, 259 and 293 from the pole end.
4. Head plate bolts: two 6.6 mm holes down through top and bottom on the centre line, 590 and 700 from the pole end.
5. Drill in a stand so every hole is square through both walls. Push a plastic end cap into the road end.

**How it fits the parts next to it.** Between the cleats at the pole end (Figure 6), the top brace clip underneath (Figure 10) and the head plate underneath at the road end (Figure 13). A 6 mm aluminium crush sleeve goes inside at every bolt so the walls are not squeezed. The radar head's axis is 700 from the pole axis.

**Check before moving on.** The holes line up along the centre line when the arm lies on the bench.

### 3.6 Knee brace

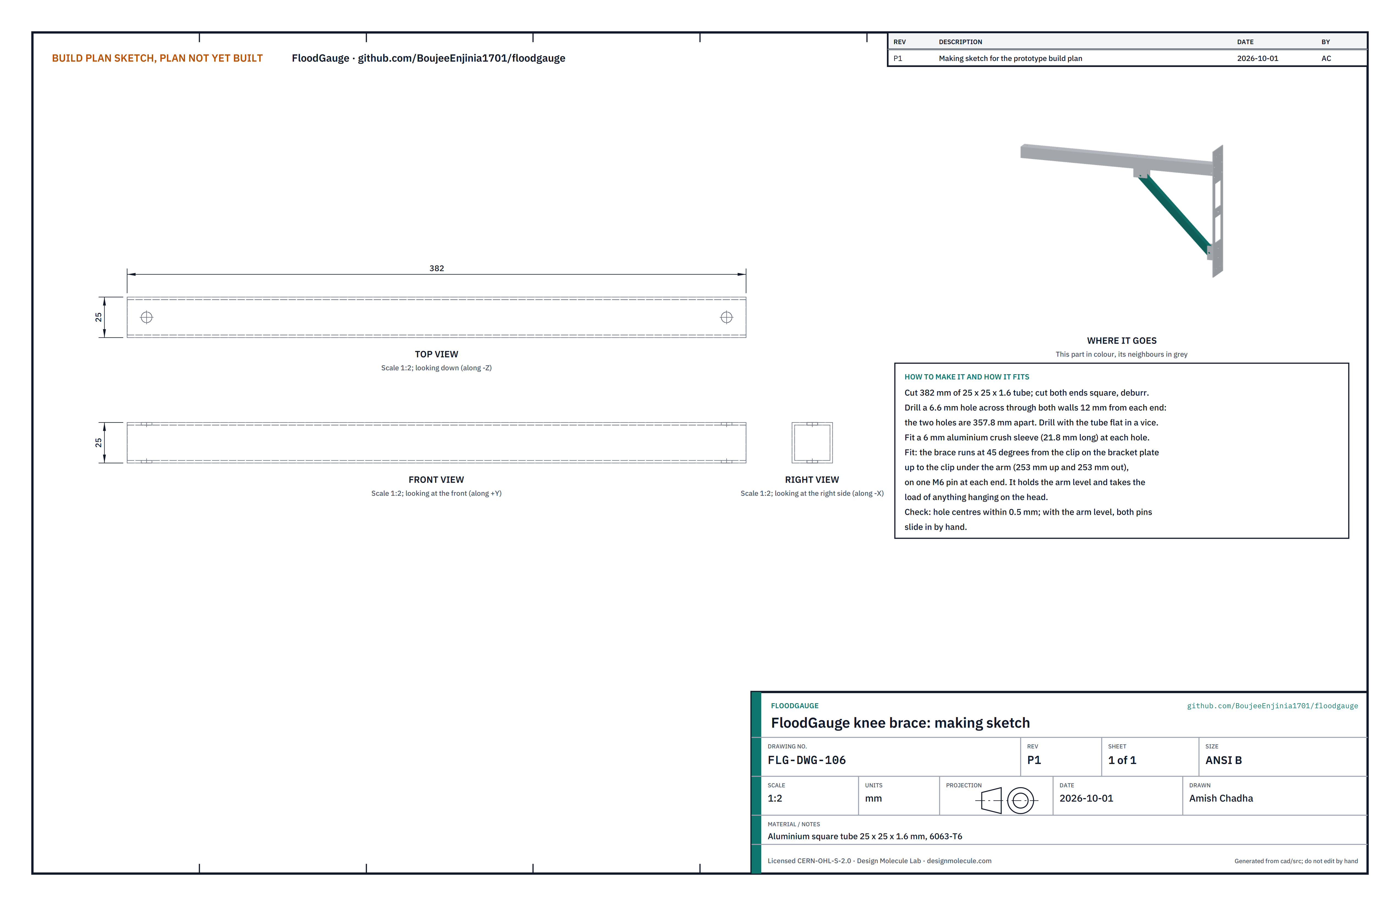
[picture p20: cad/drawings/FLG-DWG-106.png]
Figure 9. Making sketch of the knee brace


*Figure 9. Knee brace making sketch (FLG-DWG-106).*

**What it is and what it is made from.** The diagonal tube under the arm that holds it level and takes any load hung on the head. Aluminium square tube 25 x 25 x 1.6 mm, 6063-T6.

**How to make it.**

1. Cut 382 of tube; cut both ends square and deburr.
2. Drill a 6.6 mm hole through both side walls 12 from each end: 357.8 between centres. Hold the tube flat in a vice and drill both holes from the same face.
3. Fit a crush sleeve 21.8 long at each hole.

**How it fits the parts next to it.**

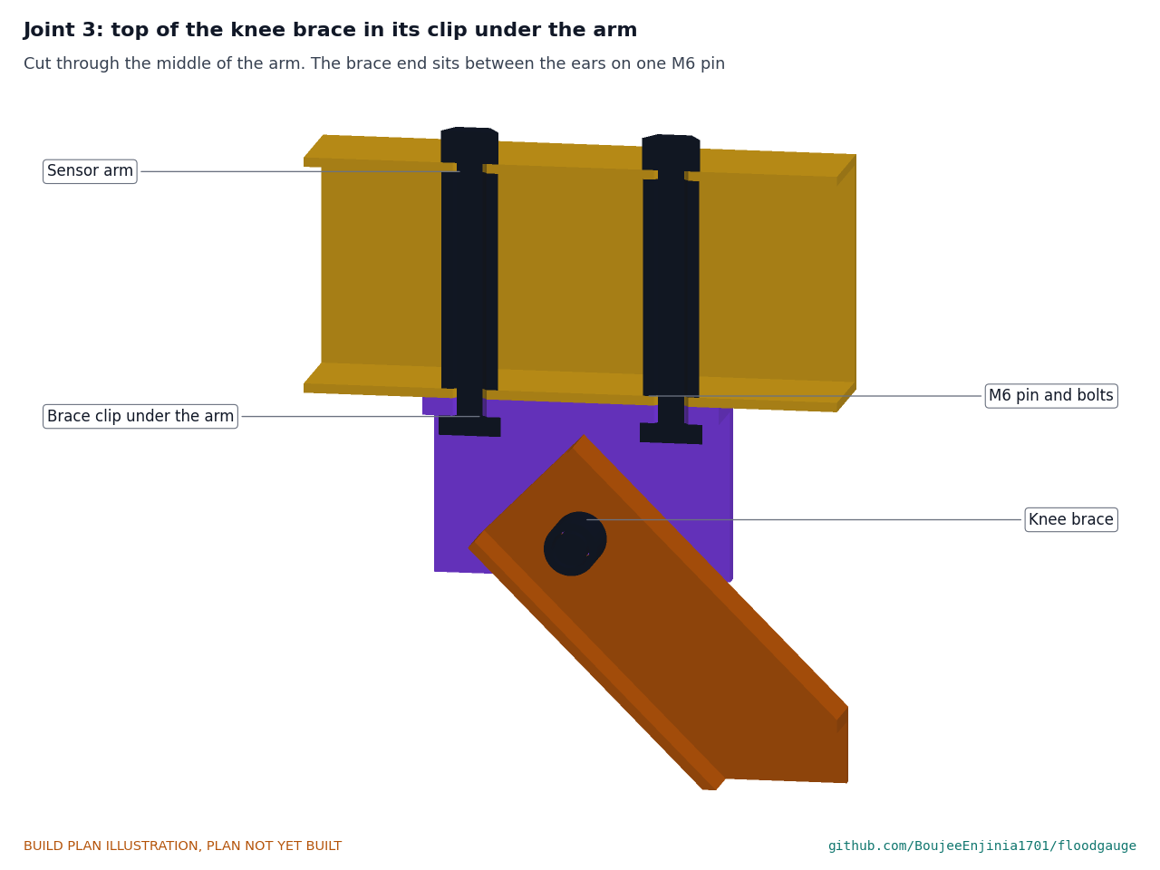
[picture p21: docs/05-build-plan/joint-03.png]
Figure 10. Joint 3: top of the brace in its clip


*Figure 10. Cut through the middle: the brace end sits between the ears of the clip under the arm on one M6 pin.*

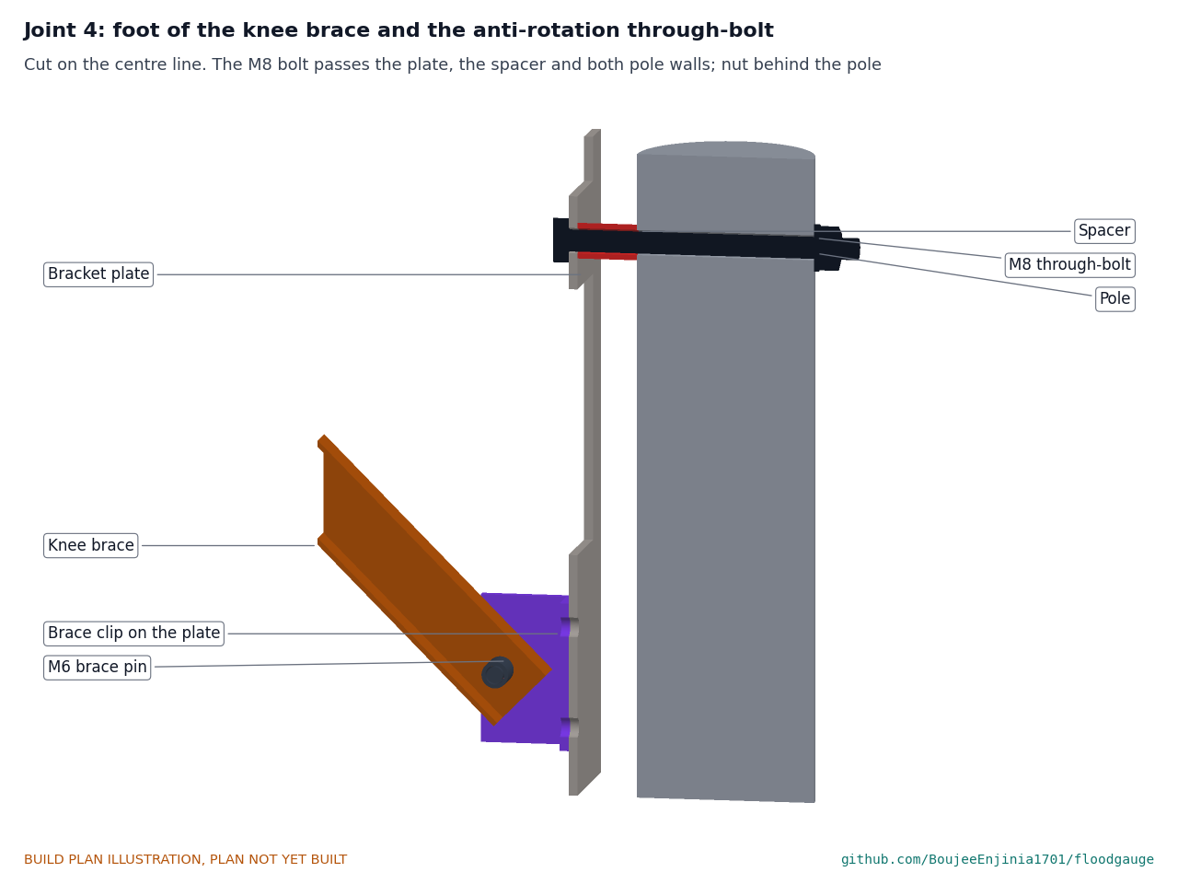
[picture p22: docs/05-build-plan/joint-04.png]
Figure 11. Joint 4: foot of the brace and the through-bolt


*Figure 11. Cut through the middle: the brace foot pinned in the clip on the plate; above it the M8 through-bolt passes the plate, the spacer and both walls of the pole.*

The brace runs at 45°, 253 up and 253 out between its pins.

**Check before moving on.** With the arm level, both pins slide in by hand.

### 3.7 Head plate

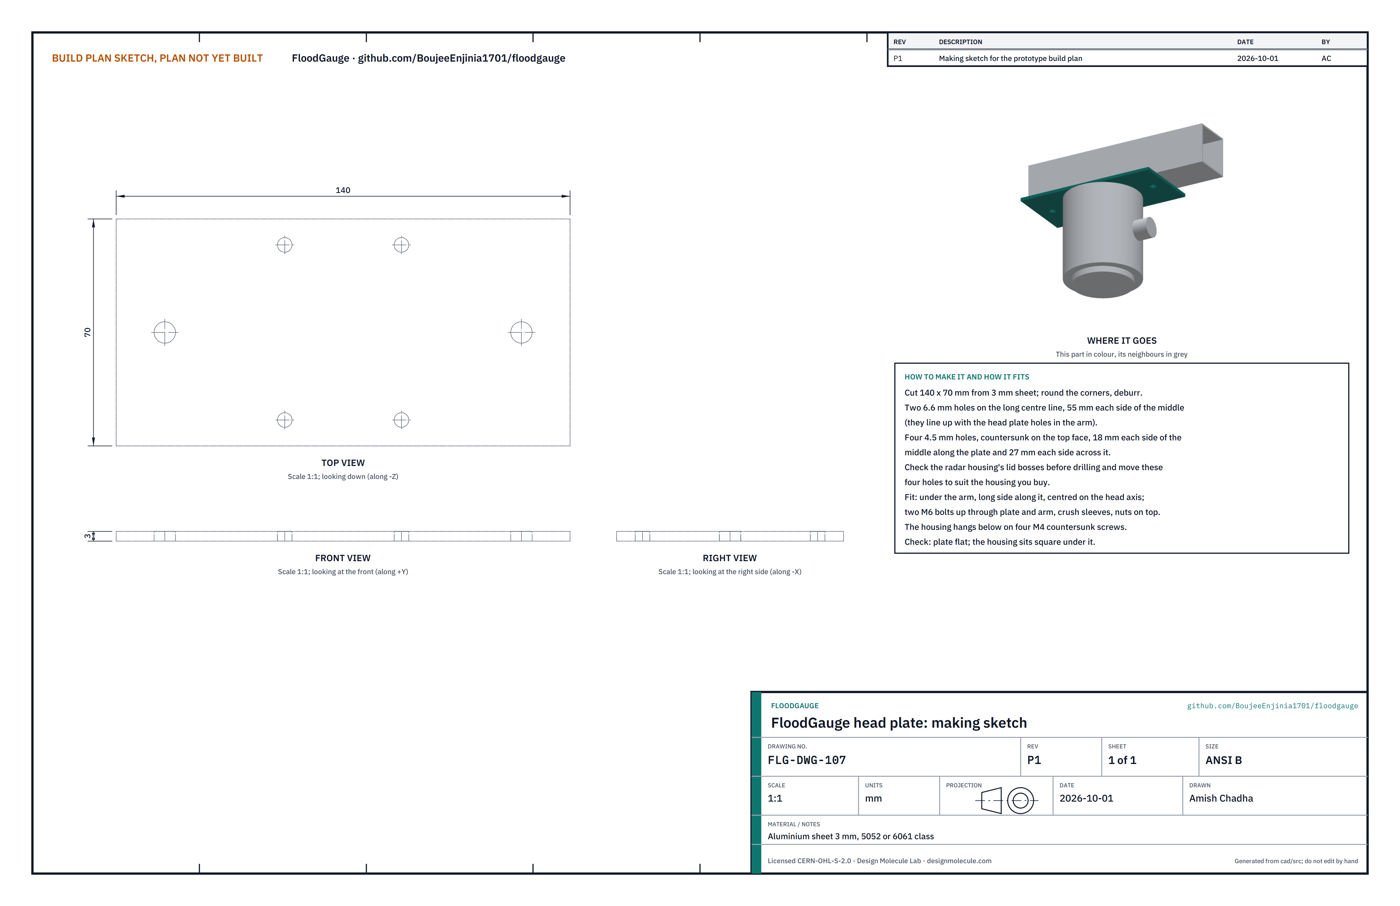
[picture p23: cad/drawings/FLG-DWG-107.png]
Figure 12. Making sketch of the head plate


*Figure 12. Head plate making sketch (FLG-DWG-107).*

**What it is and what it is made from.** The plate under the arm that the radar housing hangs from. Aluminium sheet 3 mm, 140 x 70 mm.

**How to make it.**

1. Cut 140 x 70; round the corners and deburr.
2. Two 6.6 mm holes on the long centre line, 55 each side of the middle.
3. Four 4.5 mm holes countersunk on the top face, 18 each side of the middle along the plate and 27 each side across it. Check them against the housing's lid bosses first and move them to suit.

**How it fits the parts next to it.**

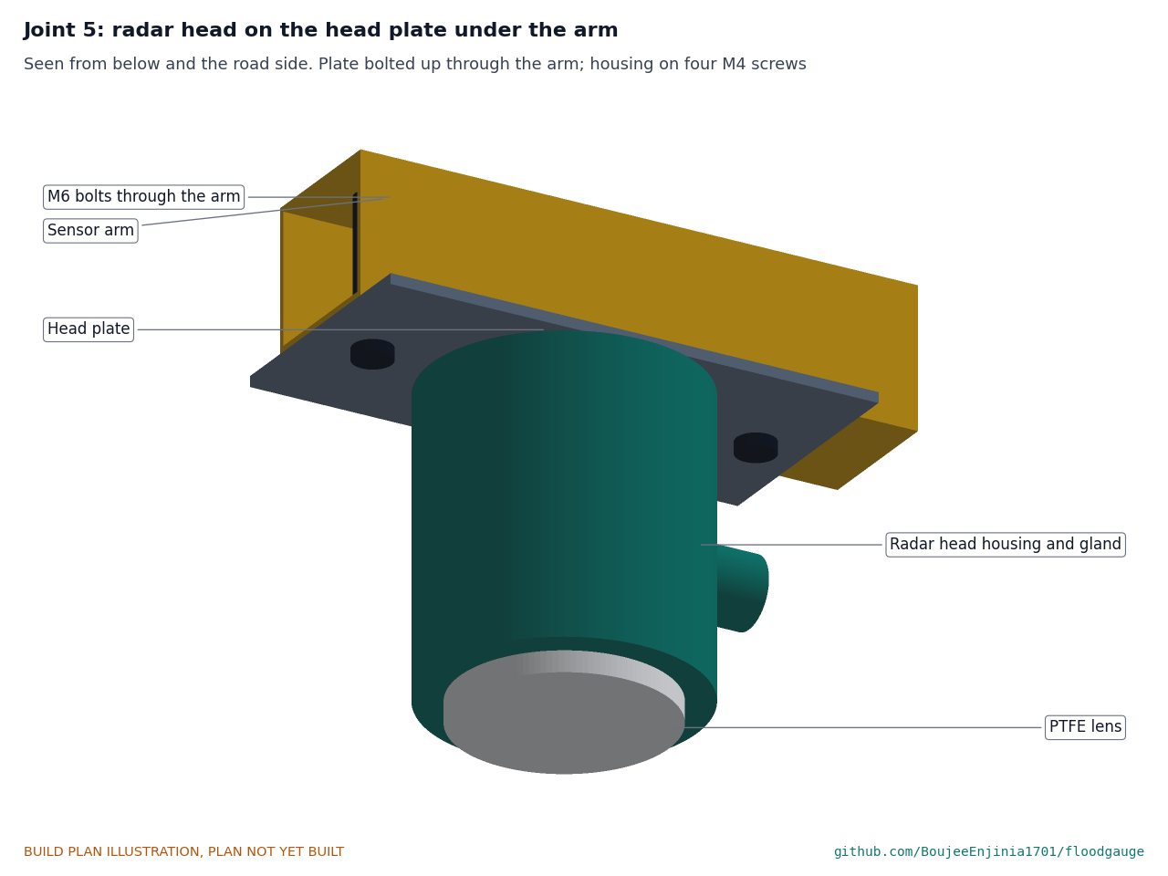
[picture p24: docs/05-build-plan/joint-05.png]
Figure 13. Joint 5: radar head under the arm


*Figure 13. The head plate is bolted up through the arm; the housing hangs on four M4 countersunk screws; the gland faces the pole.*

Long side along the arm, centred on the head axis; two M6 bolts up through the plate and the arm with crush sleeves, nuts on top.

**Check before moving on.** The plate is flat and the housing sits square under it.

### 3.8 Street radar head

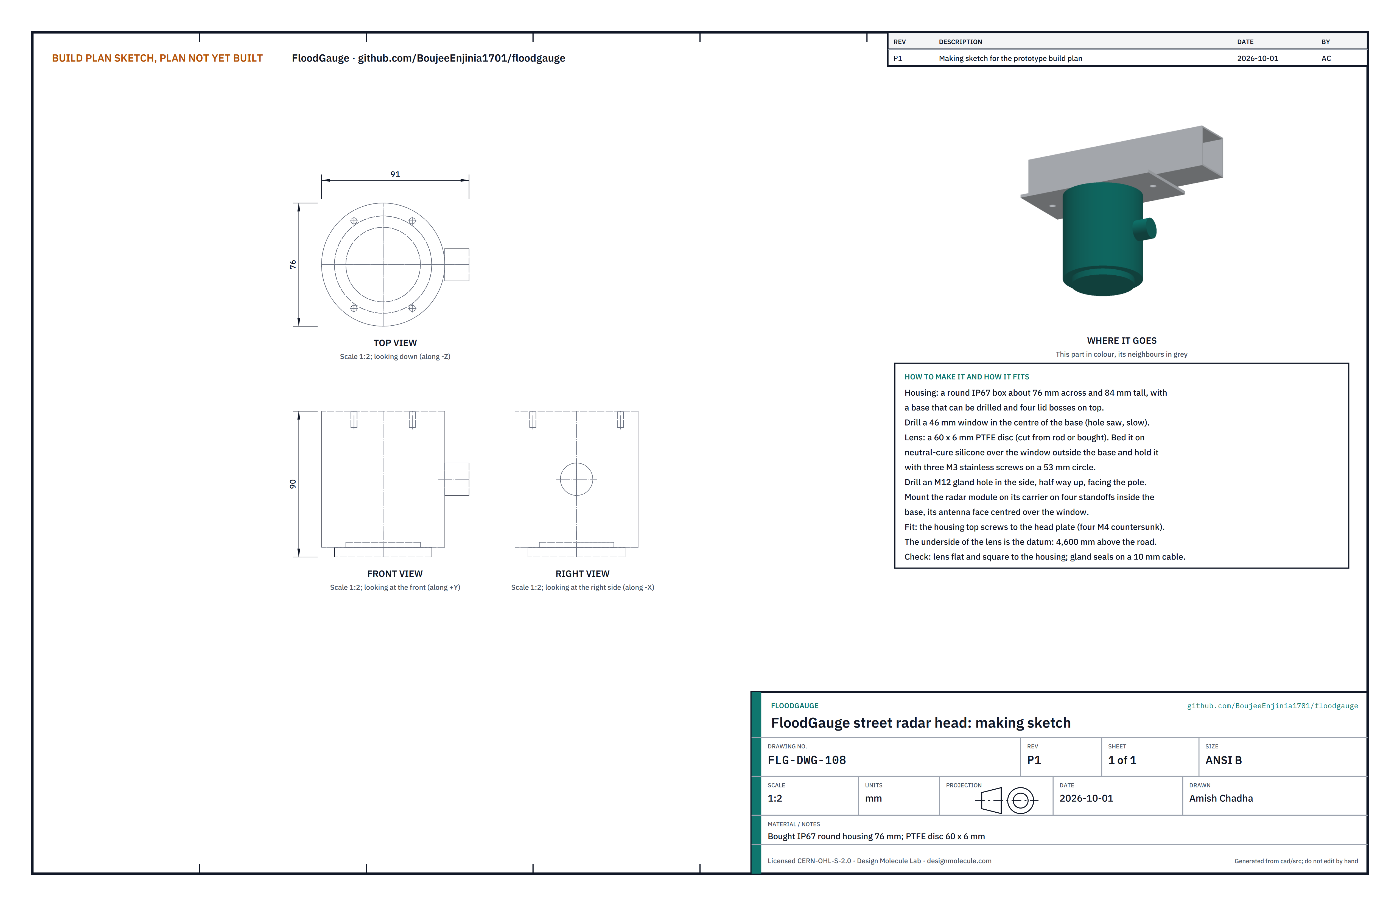
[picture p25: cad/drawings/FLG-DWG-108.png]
Figure 14. Making sketch of the street radar head


*Figure 14. Street radar head making sketch (FLG-DWG-108).*

**What it is and what it is made from.** The 60 GHz radar module in a round IP67 housing about 76 across and 84 tall, looking down through a PTFE lens disc 60 x 6.

**How to make it.**

1. Drill a 46 mm window in the centre of the housing base with a hole saw at low speed.
2. Bed the lens disc on neutral-cure silicone over the window, outside the base, and hold it with three M3 stainless screws on a 53 mm circle.
3. Drill an M12 gland hole in the side, half way up; fit the gland.
4. Mount the radar module on its carrier on four standoffs inside, its antenna face centred over the window. Wire it to the cable through the gland as its datasheet shows.

**How it fits the parts next to it.** The housing top screws to the head plate (Figure 13) with the gland facing the pole. The underside of the lens is the depth datum: 4,600 above the road.

**Check before moving on.** The lens is flat and square to the housing; the gland seals on the 10 mm cable.

### 3.9 Through-bolt spacer

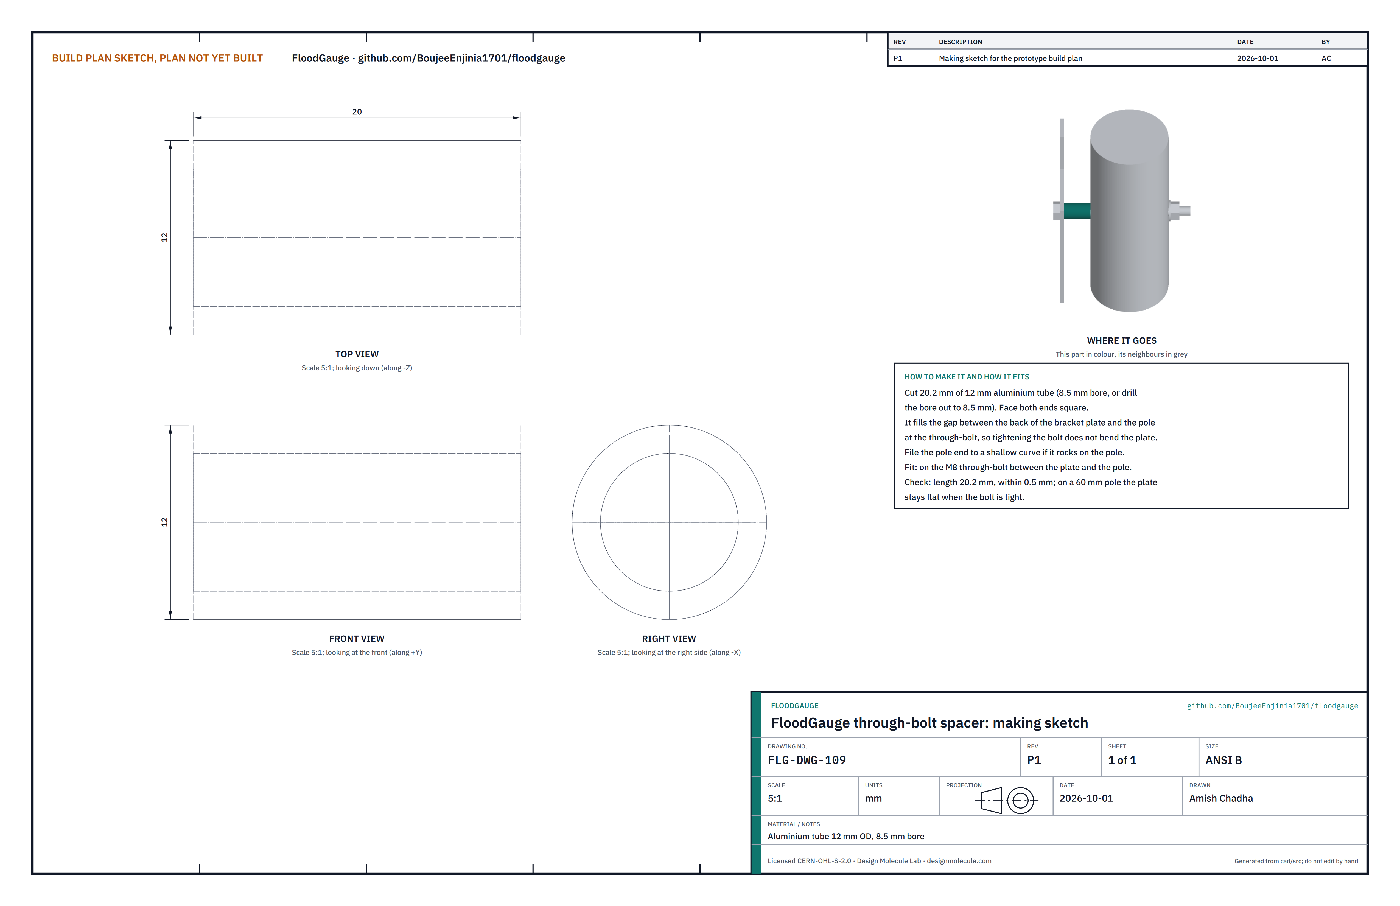
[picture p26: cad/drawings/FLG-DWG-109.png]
Figure 15. Making sketch of the through-bolt spacer


*Figure 15. Spacer making sketch (FLG-DWG-109).*

**What it is and what it is made from.** A short tube that fills the gap between the back of the bracket plate and the pole at the through-bolt. Aluminium tube 12 mm outside, 8.5 mm bore.

**How to make it.** Cut 20.2 long and face both ends square. File the pole end to a shallow curve if it rocks on the pole.

**How it fits the parts next to it.** On the M8 through-bolt between the plate and the pole (Figure 11), so tightening the bolt does not bend the plate.

**Check before moving on.** Length 20.2, within 0.5.

### 3.10 Depth marker plate

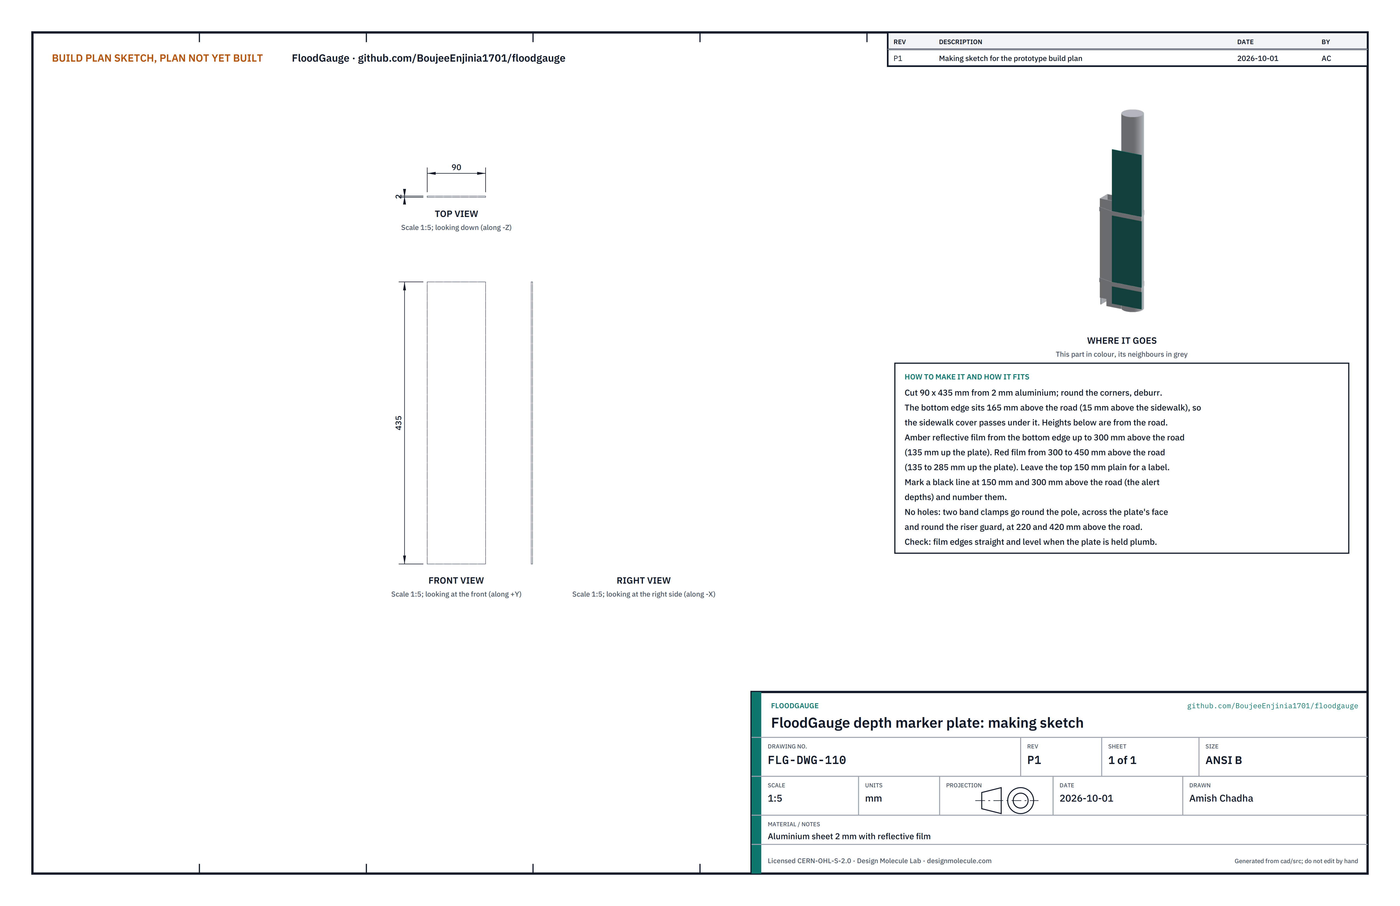
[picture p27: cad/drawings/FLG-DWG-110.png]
Figure 16. Making sketch of the depth marker plate


*Figure 16. Depth marker making sketch (FLG-DWG-110).*

**What it is and what it is made from.** The plate on the road face of the pole that lets anyone read the water depth. Aluminium sheet 2 mm, 90 x 435 mm, with reflective film.

**How to make it.**

1. Cut 90 x 435; round the corners and deburr.
2. The bottom edge will sit 165 above the road. Apply amber film from the bottom edge to 135 up the plate (300 above the road) and red film from 135 to 285 up the plate (300 to 450 above the road). Leave the top 150 plain for a label.
3. Mark black lines at 150 and 300 above the road (the alert depths) and number them.

**How it fits the parts next to it.**

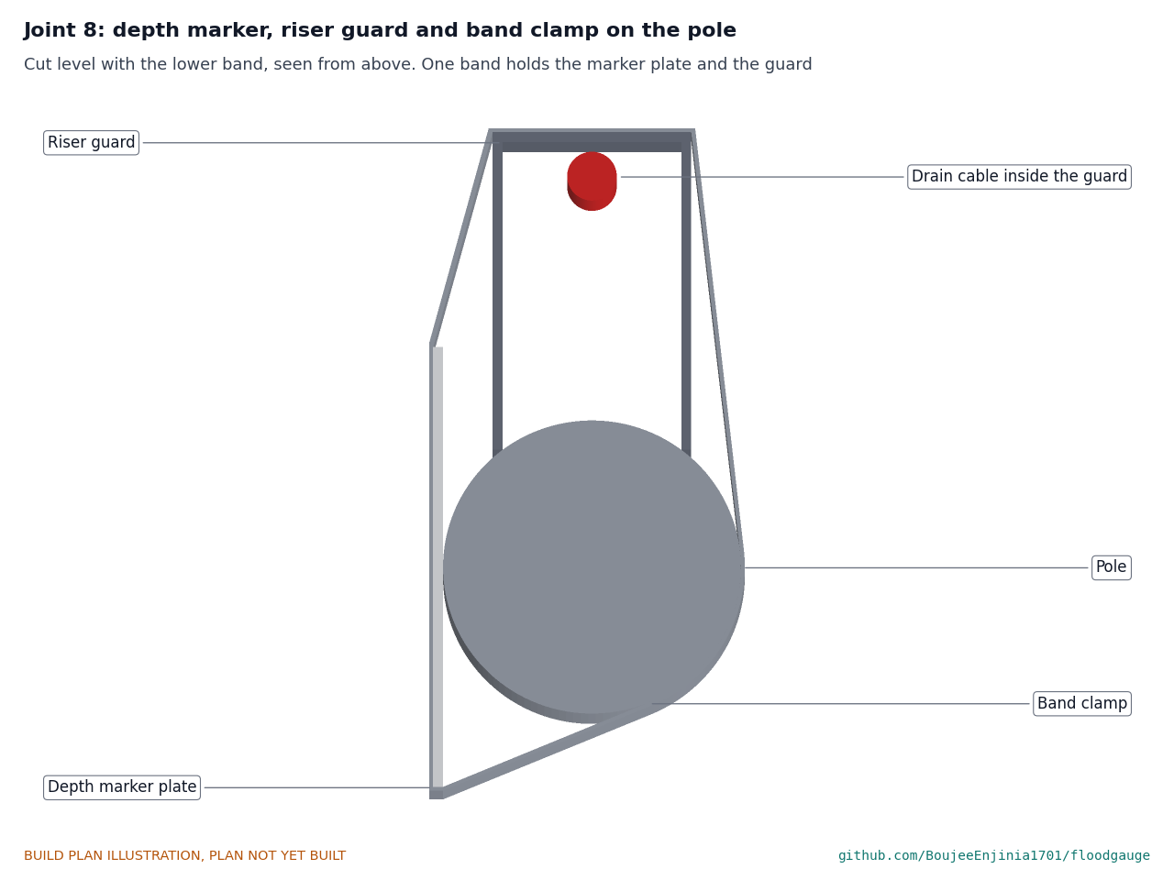
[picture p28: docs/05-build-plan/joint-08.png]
Figure 17. Joint 8: marker, riser guard and band clamp


*Figure 17. Seen from above at the lower band: one band clamp goes round the pole, across the face of the marker plate and round the riser guard.*

Flat on the road face of the pole, held by two band clamps at 220 and 420 above the road that also hold the riser guard. Fit the clamps with their security (pin-Torx) screws, tightened with the pin-Torx bit.

**Check before moving on.** The film edges are straight and level when the plate is held plumb.

### 3.11 Riser guard

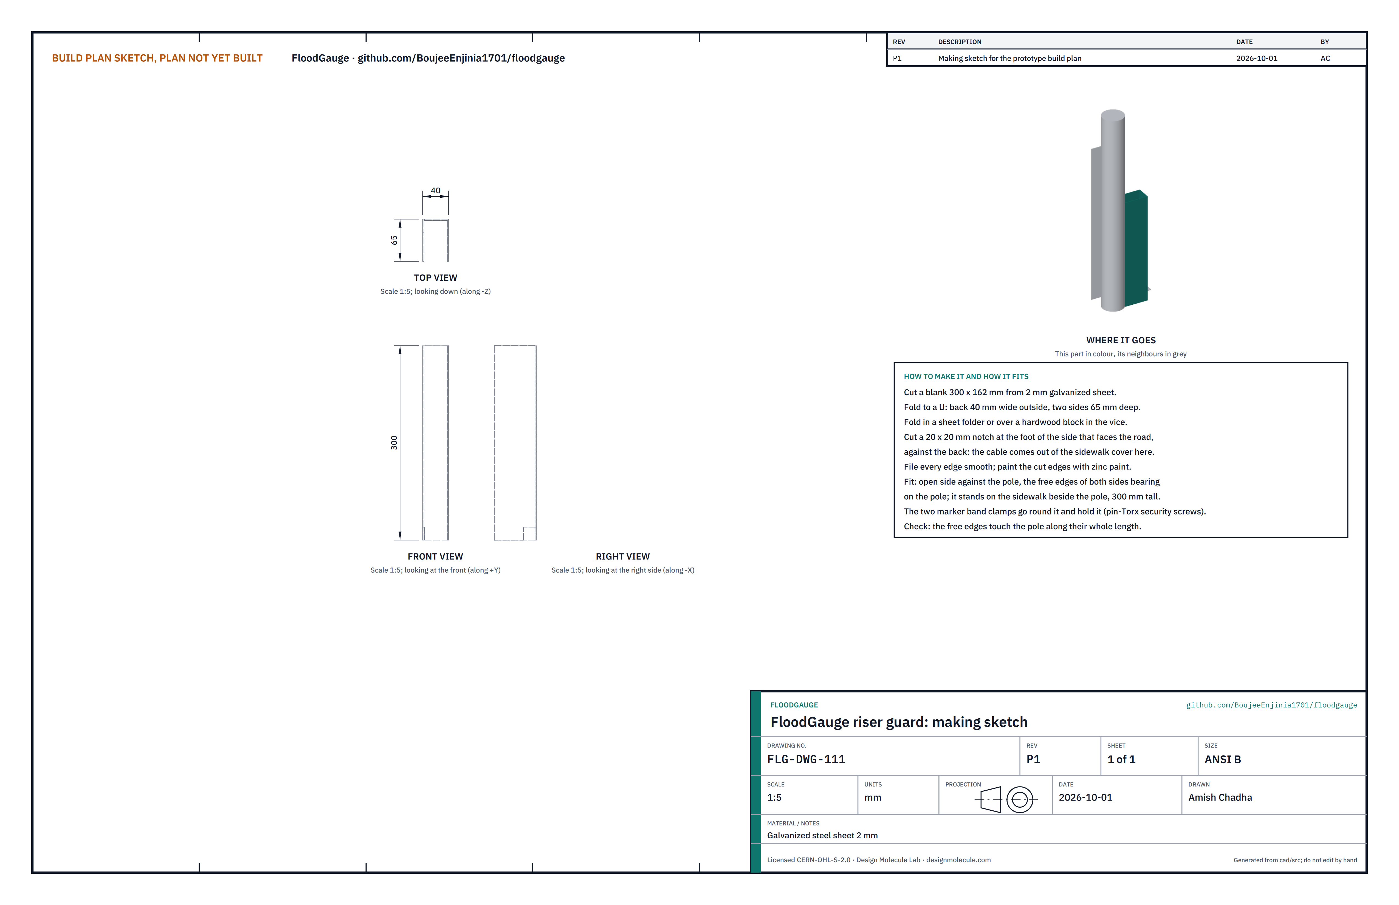
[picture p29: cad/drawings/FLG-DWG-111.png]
Figure 18. Making sketch of the riser guard


*Figure 18. Riser guard making sketch (FLG-DWG-111).*

**What it is and what it is made from.** A steel channel that protects the drain cable where it rises from the sidewalk to above kicking height. Galvanized steel sheet 2 mm.

**How to make it.**

1. Cut a 300 x 162 blank.
2. Fold to a U: back 40 wide outside, sides 65 deep, in a sheet folder or over a hardwood block in the vice.
3. Cut a 20 x 20 notch at the foot of the side that will face the road, against the back.
4. File every edge smooth and paint cut edges with zinc paint.

**How it fits the parts next to it.** It stands on the sidewalk beside the pole, open side to the pole, the free edges of both sides bearing on the pole (Figure 17). The marker band clamps, with their security screws, hold it. The cable leaves the sidewalk cover through the notch.

**Check before moving on.** The free edges touch the pole along their whole length.

### 3.12 Stilling tube

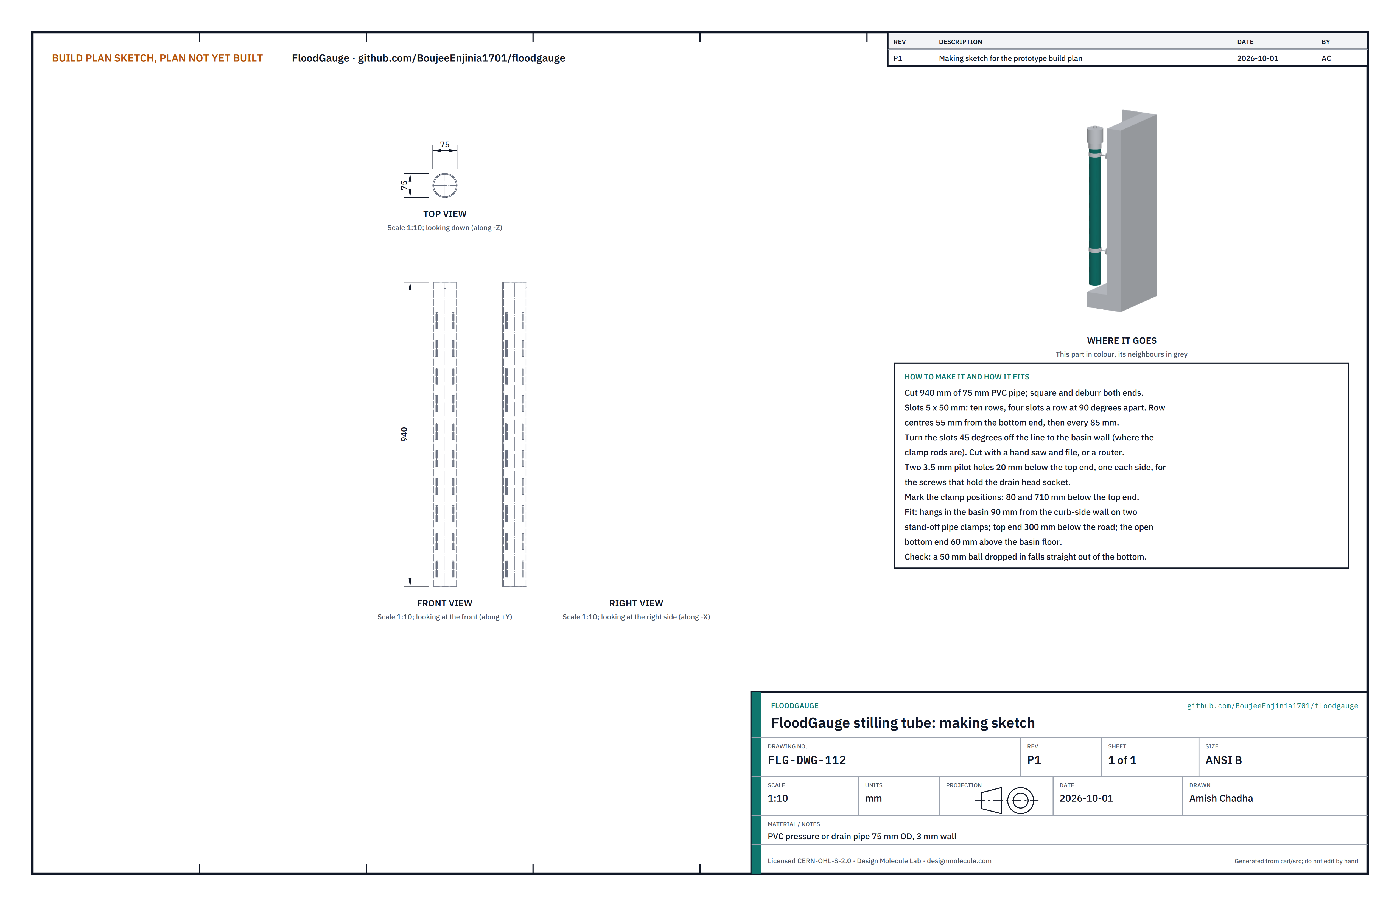
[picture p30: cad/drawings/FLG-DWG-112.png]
Figure 19. Making sketch of the stilling tube


*Figure 19. Stilling tube making sketch (FLG-DWG-112).*

**What it is and what it is made from.** A slotted pipe in the catch basin that calms the water so the drain head reads a steady level. PVC pipe 75 mm outside, 3 mm wall.

**How to make it.**

1. Cut 940; square and deburr both ends.
2. Cut 40 slots 5 x 50: ten rows of four, 90° apart, row centres 55 from the bottom end and then every 85. Turn the slots 45° off the line to the basin wall.
3. Drill two 3.5 mm pilot holes 20 below the top end, one each side, for the drain head screws.
4. Mark the clamp positions 80 and 710 below the top end.

**How it fits the parts next to it.** It hangs 90 from the curb-side wall of the basin on two stand-off pipe clamps (Figure 21), its top 300 below the road and its open bottom 60 above the basin floor.

**Check before moving on.** A 50 mm ball dropped in the top falls out of the bottom.

### 3.13 Drain head

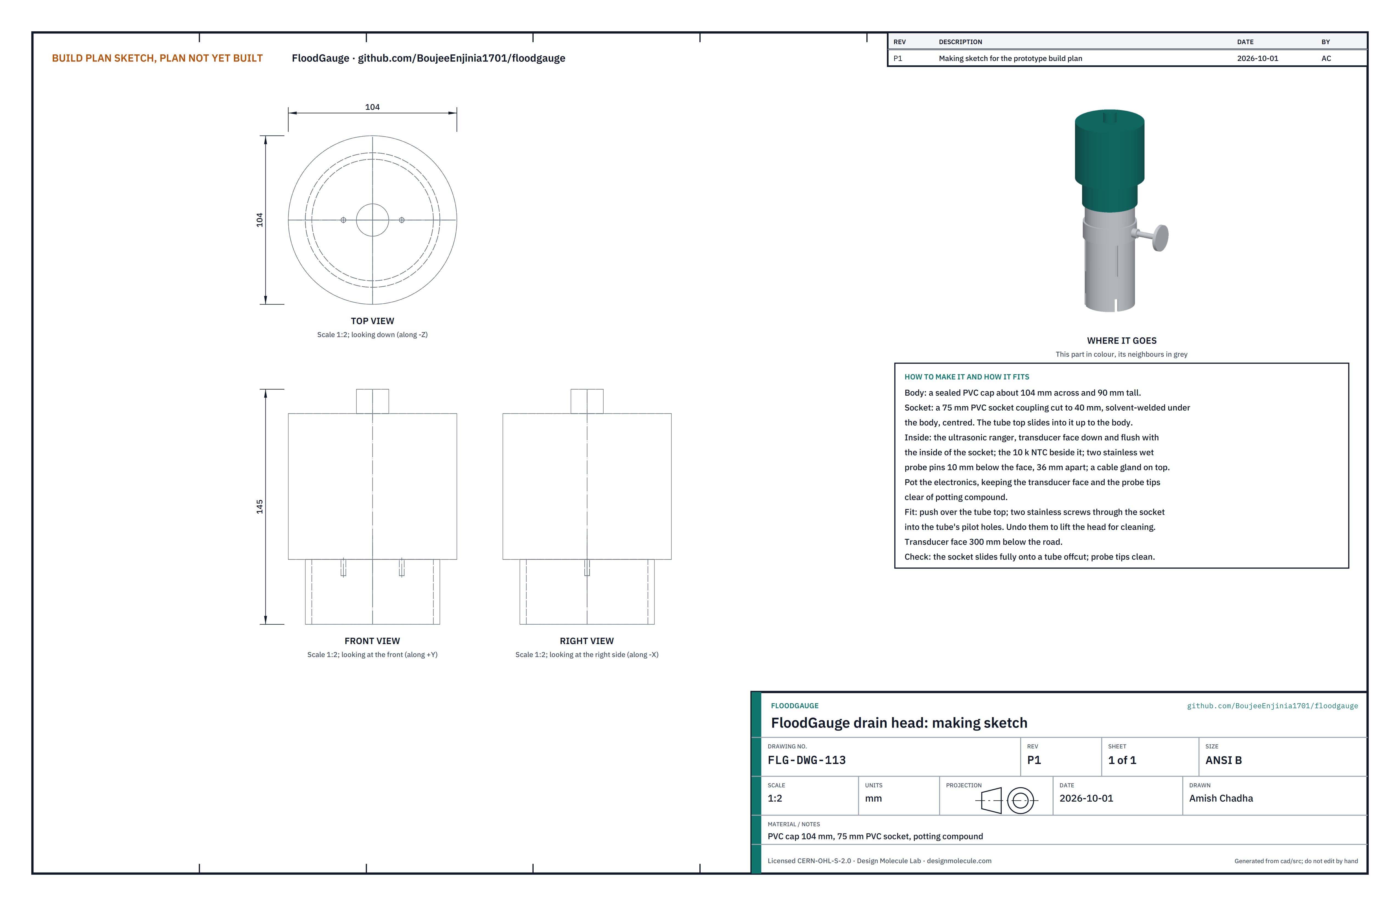
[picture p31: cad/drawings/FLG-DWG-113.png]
Figure 20. Making sketch of the drain head


*Figure 20. Drain head making sketch (FLG-DWG-113).*

**What it is and what it is made from.** The ultrasonic ranger, temperature sensor and wet probe, potted in a sealed cap about 104 across and 90 tall, with a 75 mm PVC socket under it.

**How to make it.**

1. Cut a 75 mm socket coupling to 40 long and solvent-weld it centred under the cap.
2. Fit the ultrasonic ranger with its transducer face down, flush with the inside of the socket; fit the 10 k temperature sensor beside it; fit two stainless wet probe pins 36 apart, their tips 10 below the face; fit a cable gland on top.
3. Wire them to the cable as the module datasheets show, then pot the electronics, keeping the transducer face and probe tips clean.

**How it fits the parts next to it.**

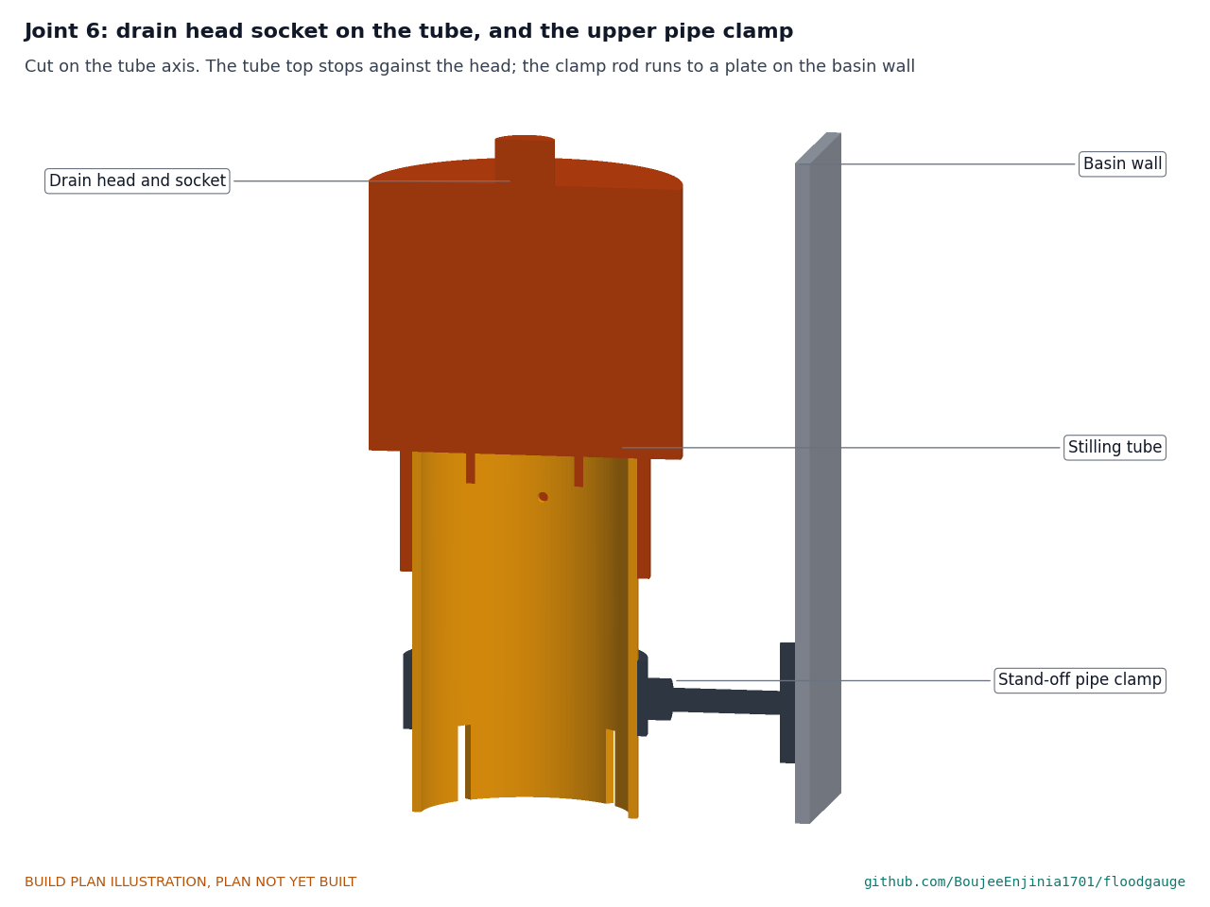
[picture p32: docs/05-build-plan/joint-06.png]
Figure 21. Joint 6: drain head on the tube and the upper pipe clamp


*Figure 21. Cut through the tube: the tube top slides into the socket up to the head; the clamp ring holds the tube on a rod to a plate on the basin wall.*

Pushed over the tube top and held by two stainless screws into the pilot holes. The transducer face is 300 below the road.

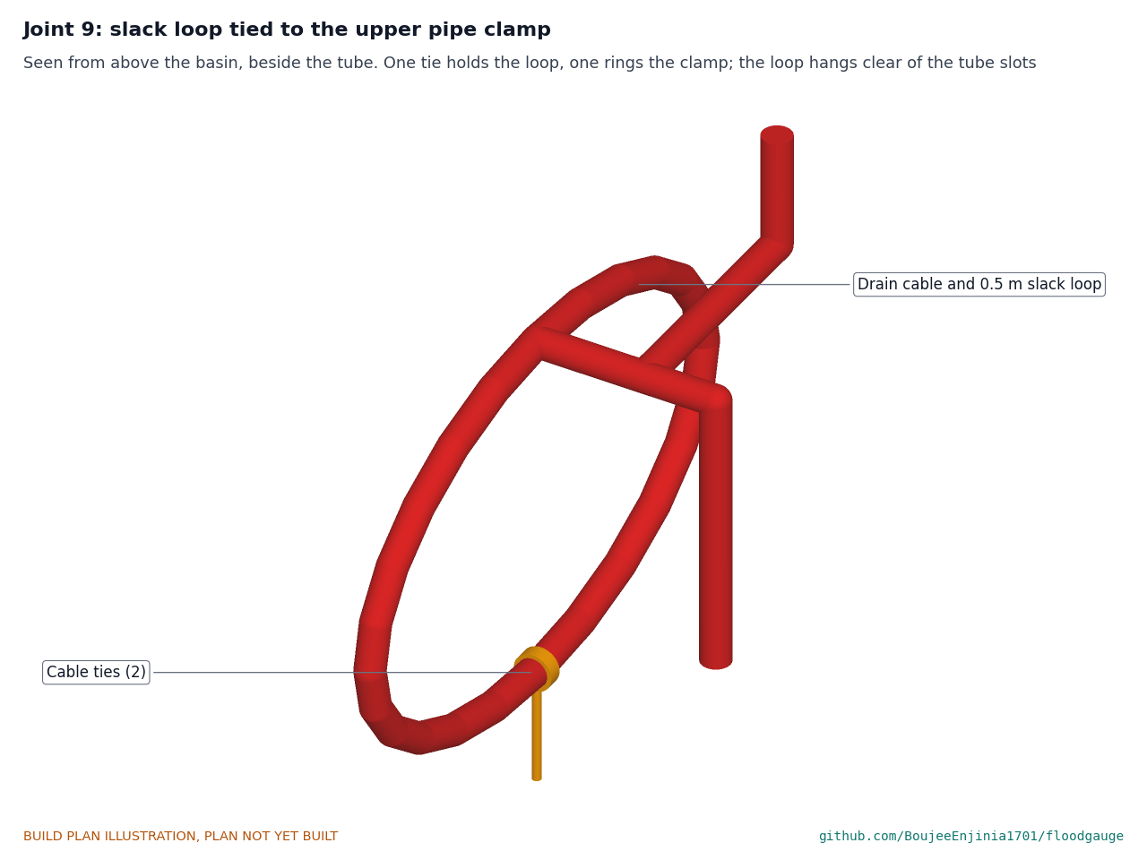
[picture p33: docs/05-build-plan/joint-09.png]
Figure 22. Joint 9: slack loop tied to the upper pipe clamp


*Figure 22. Seen from above the basin: the drain cable leaves the head, makes a 0.5 m loop beside the tube, and is tied to the loop and to the upper pipe clamp.*

**Check before moving on.** The socket slides fully onto a tube offcut and the probe tips are clean.

### 3.14 Gutter cover

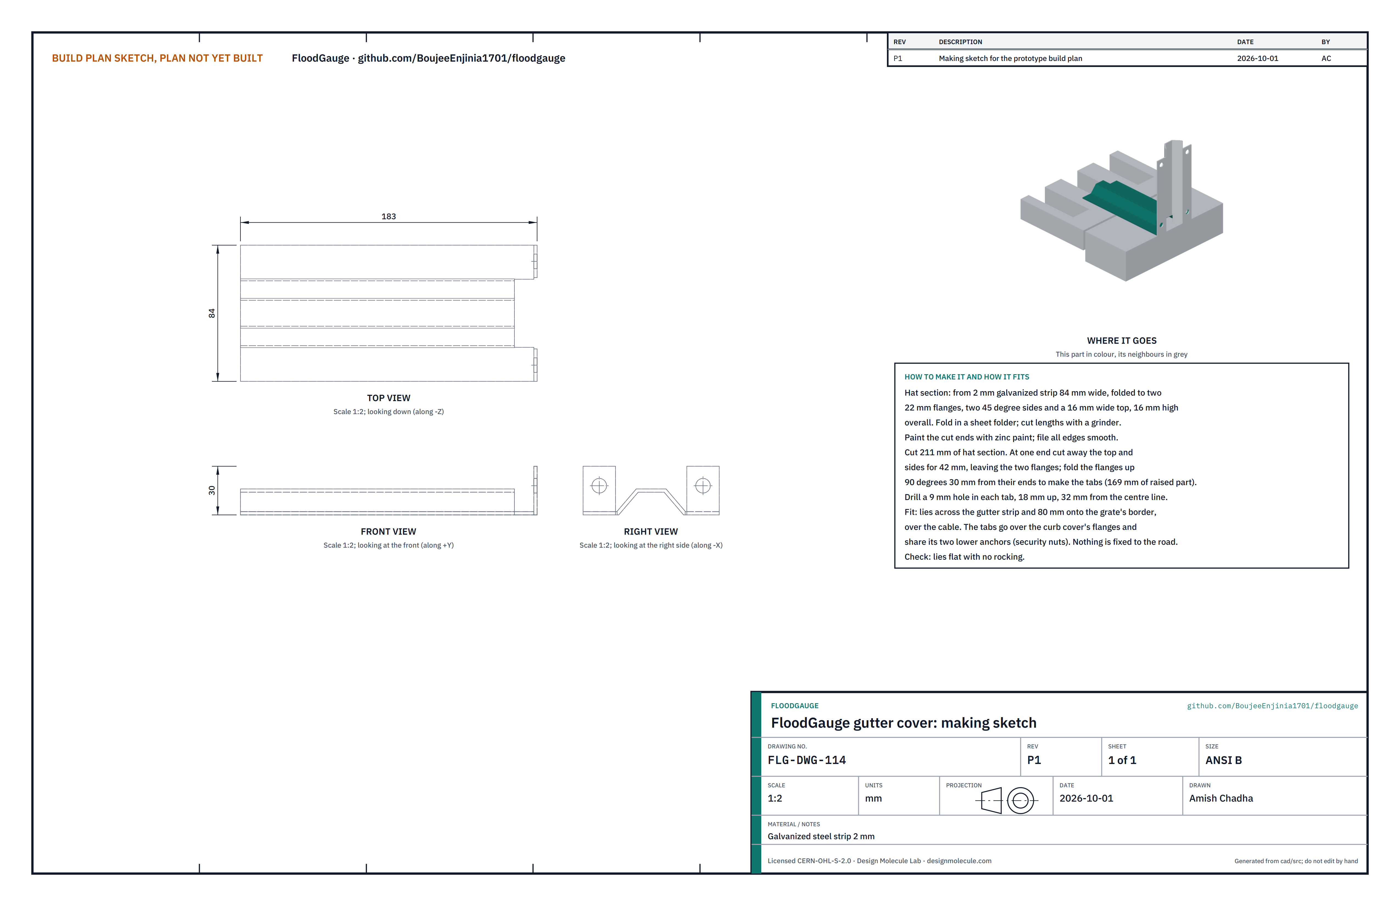
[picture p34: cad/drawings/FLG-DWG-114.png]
Figure 23. Making sketch of the gutter cover


*Figure 23. Gutter cover making sketch (FLG-DWG-114).*

**What it is and what it is made from.** The first of three steel covers over the drain cable: it lies across the gutter strip. All three are a hat section folded from 2 mm galvanized strip 84 wide: two 22 flanges, two 45° sides and a 16 wide top, 16 high overall.

**How to make it.**

1. Fold the hat section in a sheet folder; cut 211 long.
2. At one end cut away the top and sides for 42, leaving the flanges; fold the flanges up 90° 30 from their ends to make two tabs.
3. Drill a 9 mm hole in each tab, 18 up, 32 from the centre line. Paint cut edges with zinc paint.

**How it fits the parts next to it.** It lies over the cable across the gutter strip and 80 onto the grate's border; nothing is fixed to the road. Its tabs lie on the curb cover's flanges and share its two lower anchors (Figure 25).

**Check before moving on.** It lies flat without rocking.

### 3.15 Curb cover

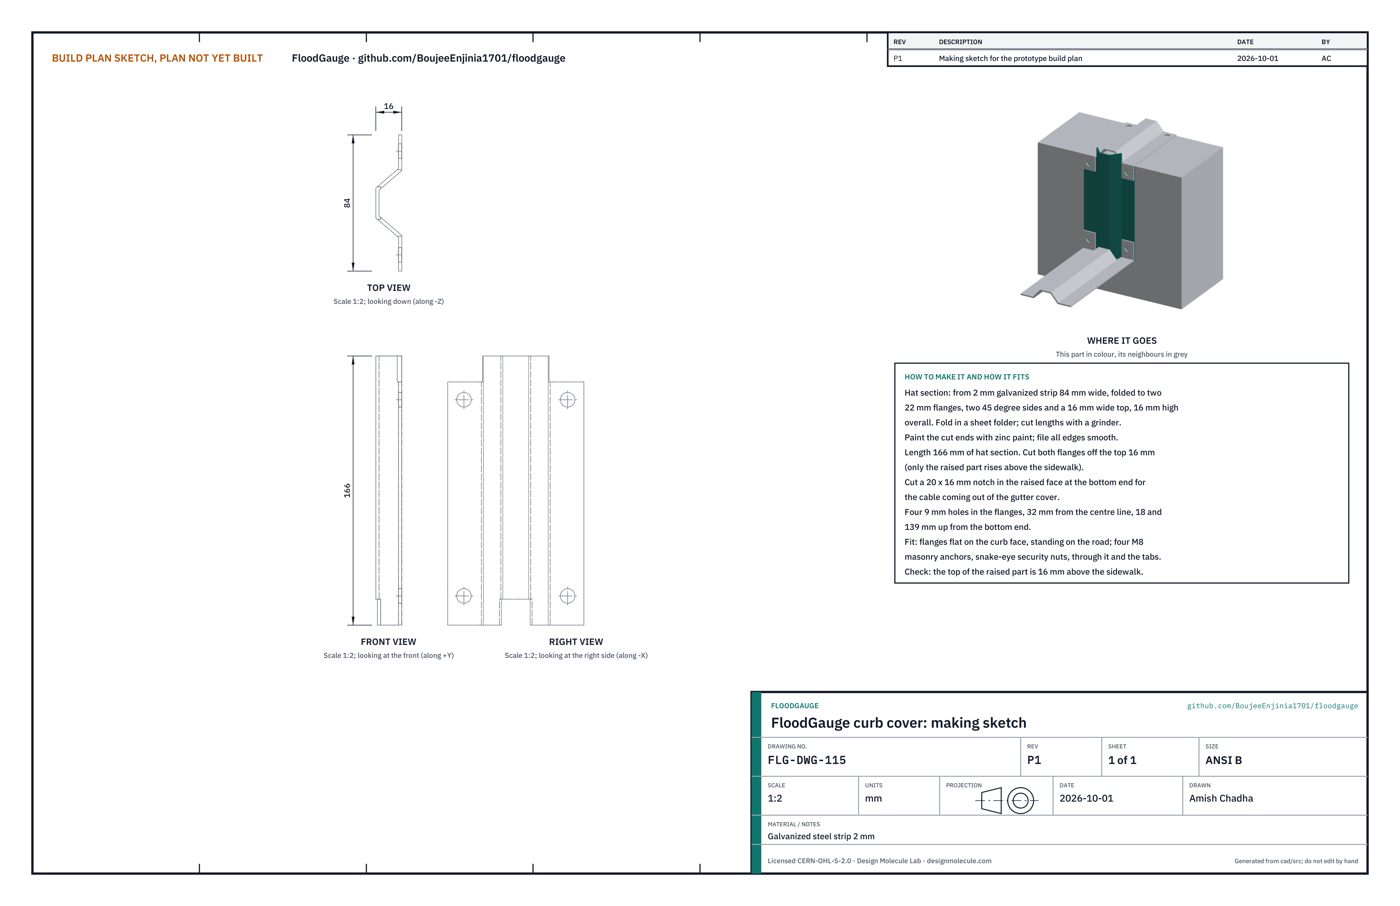
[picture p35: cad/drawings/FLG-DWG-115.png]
Figure 24. Making sketch of the curb cover


*Figure 24. Curb cover making sketch (FLG-DWG-115).*

**What it is and what it is made from.** The hat-section cover up the curb face.

**How to make it.**

1. Cut 166 of hat section. Cut both flanges off the top 16 (only the raised part rises above the sidewalk).
2. Cut a 20 x 16 notch in the raised face at the bottom end for the cable.
3. Four 9 mm holes in the flanges, 32 from the centre line, 18 and 139 up from the bottom end.

**How it fits the parts next to it.**

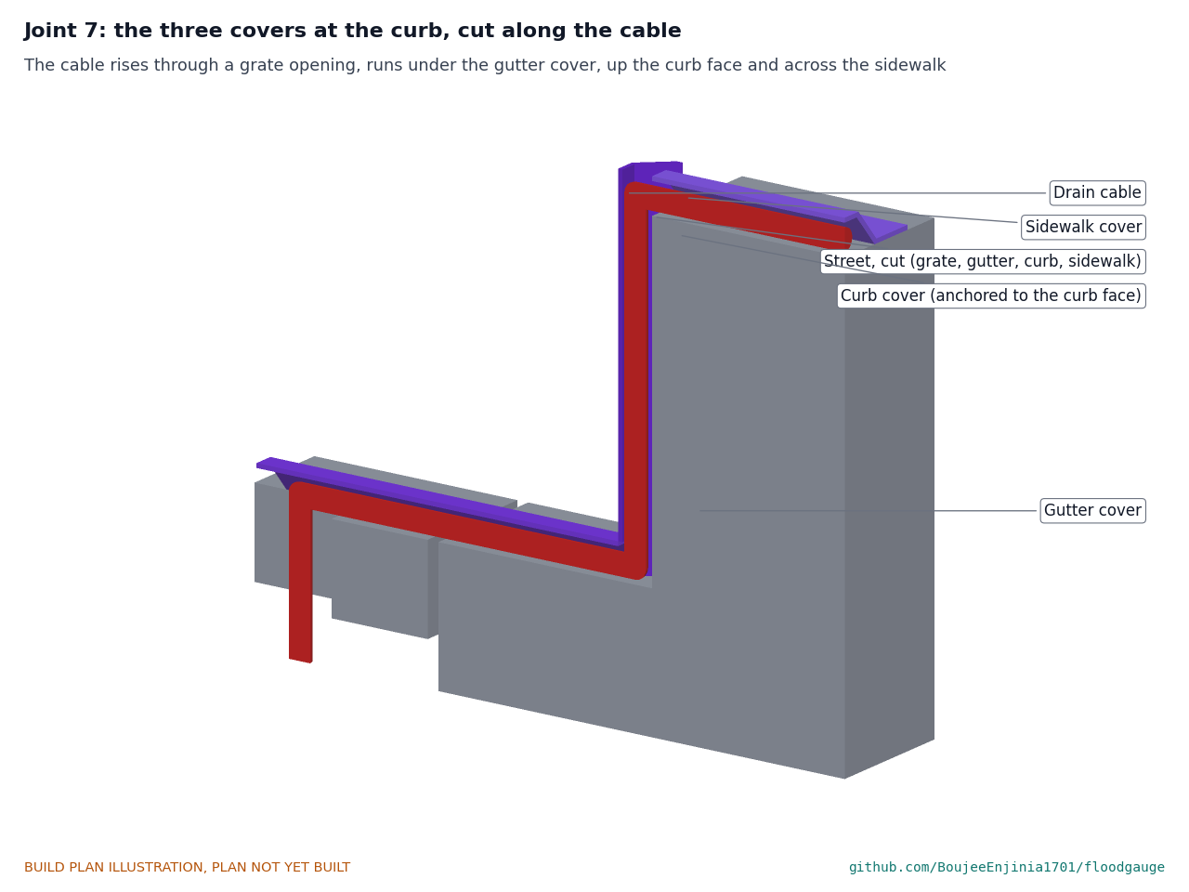
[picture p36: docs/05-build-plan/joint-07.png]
Figure 25. Joint 7: the three covers at the curb


*Figure 25. Cut along the cable: it rises through a grate opening, runs under the gutter cover, up inside the curb cover and across under the sidewalk cover.*

It stands on the road with its flanges flat on the curb face, held by four M8 masonry anchors; the lower two also hold the gutter cover's tabs, the upper two the sidewalk cover's tabs. Each anchor takes a washer and a snake-eye (two-hole) security nut, tightened with the snake-eye spanner bit.

**Check before moving on.** The top of the raised part is 16 above the sidewalk.

### 3.16 Sidewalk cover

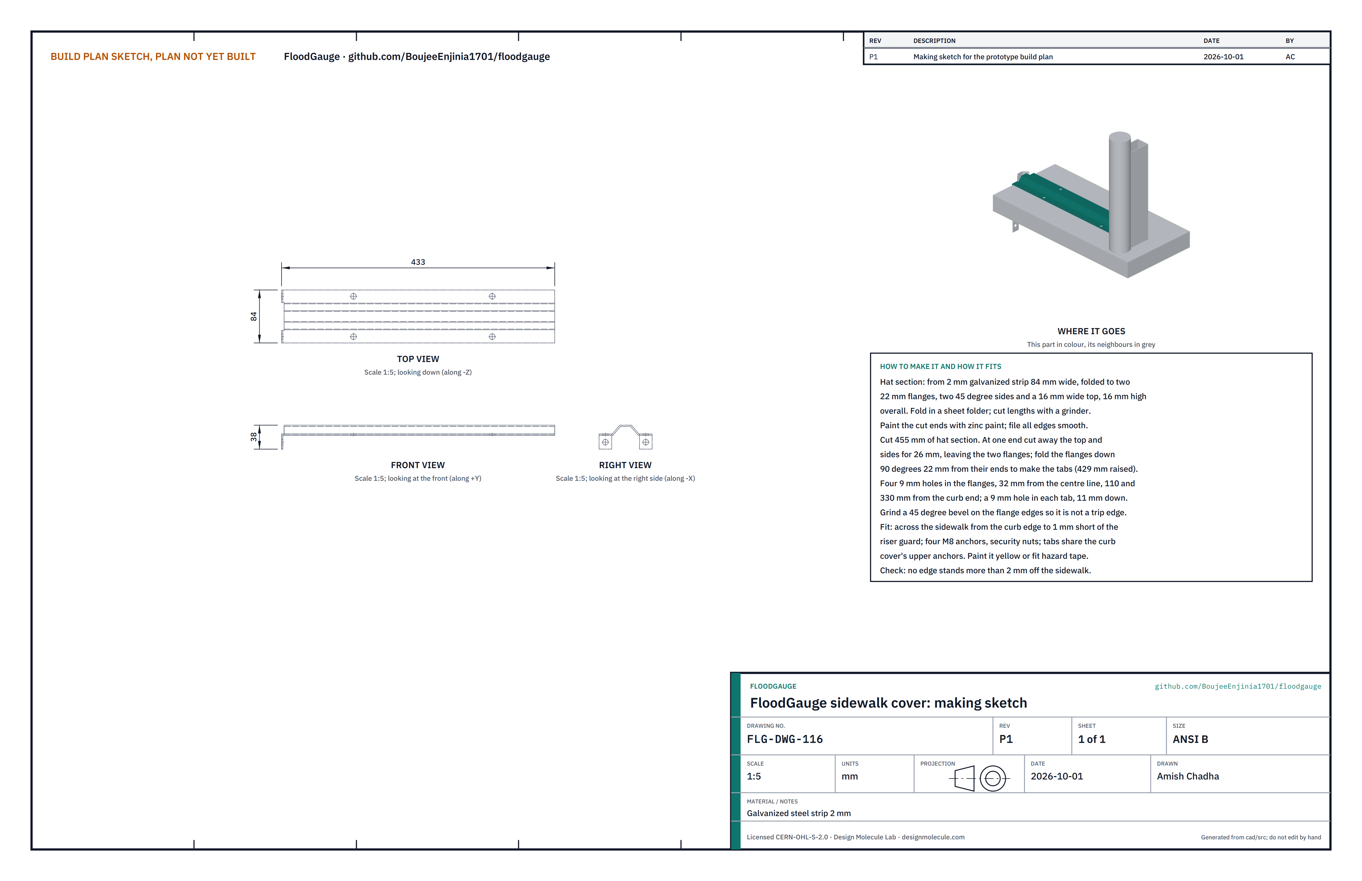
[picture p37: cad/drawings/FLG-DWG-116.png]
Figure 26. Making sketch of the sidewalk cover


*Figure 26. Sidewalk cover making sketch (FLG-DWG-116).*

**What it is and what it is made from.** The hat-section cover across the sidewalk to the riser guard.

**How to make it.**

1. Cut 455 of hat section. At one end cut away the top and sides for 26, leaving the flanges; fold the flanges down 90° 22 from their ends to make two tabs.
2. Four 9 mm holes in the flanges, 32 from the centre line, 110 and 330 from the curb end; a 9 mm hole in each tab 11 down.
3. Grind a 45° bevel on the flange edges. Paint it yellow or fit hazard tape.

**How it fits the parts next to it.** It runs from the curb edge to 1 short of the riser guard, with the cable entering the guard through its notch. Four M8 masonry anchors in the sidewalk, each with a washer and a snake-eye security nut; its tabs share the curb cover's upper anchors (Figure 25).

**Check before moving on.** No edge stands more than 2 off the sidewalk.

### 3.17 Bought components

Buy to specification, not brand. Line numbers are those of the bill of materials.

- **FieldNode core (line 1).** Built to the FieldNode build plan FND-BLD-001, with band clamps long enough for a 60 mm pole (about 330 to 380 mm round).
- **Radar module, housing, lens stock and gland (line 2).** A 60 GHz pulsed coherent radar module of the Acconeer XM125 class with I2C; a round IP67 housing about 76 x 84 with four lid bosses; PTFE rod or disc 60 x 6; an M12 cable gland for 8 to 10 mm cable.
- **Bracket hardware (line 3).** Two 12 mm stainless worm-drive band clamps for a 60 mm pole with the V-block inside (about 330 to 380 mm round); an M8 x 100 A4 bolt with nyloc nut and two washers; about 14 M6 A4 bolts and nyloc nuts (button-head for the clips); 6 mm aluminium crush sleeves; eight M4 countersunk screws; a 40 mm plastic tube end cap.
- **Drain head parts (line 4).** A waterproof ultrasonic ranger (DFRobot A02YYUW or equal: 3 to 450 cm, IP67, UART); a 10 k temperature sensor; stainless wire for the probe pins; potting compound; a sealed cap about 104 across; a 75 mm PVC socket coupling; two stainless screws.
- **Pipe clamps (line 5).** Two stainless stand-off pipe clamps for 75 mm pipe with an M8 rod about 45 long, a wall plate and a stainless wall anchor.
- **Cables (line 6).** Outdoor 5-core cable about 10 mm with an M12 5-pin plug: 3 m for the street head, 5 m for the drain head.
- **Cover hardware (line 7).** Eight M8 stainless masonry anchors with washers and snake-eye (two-hole) security nuts in place of ordinary nuts; UV-stable cable ties.
- **Marker band clamps (line 8).** Two 12 mm stainless worm-drive band clamps about 450 mm round, with their screws replaced by pin-Torx TR25 security screws.
- **Security fixing bits (line 10).** One snake-eye spanner bit for the security nuts and one TR25 pin-Torx bit for the band clamp screws.

## 4. Putting it together

In each picture the parts already fitted are grey and the part being fitted is in colour, with an arrow showing the way it goes in. Steps 1 to 6 are done on the bench; steps 7 to 14 at the site.

### Step 1: V-blocks onto the bracket plate

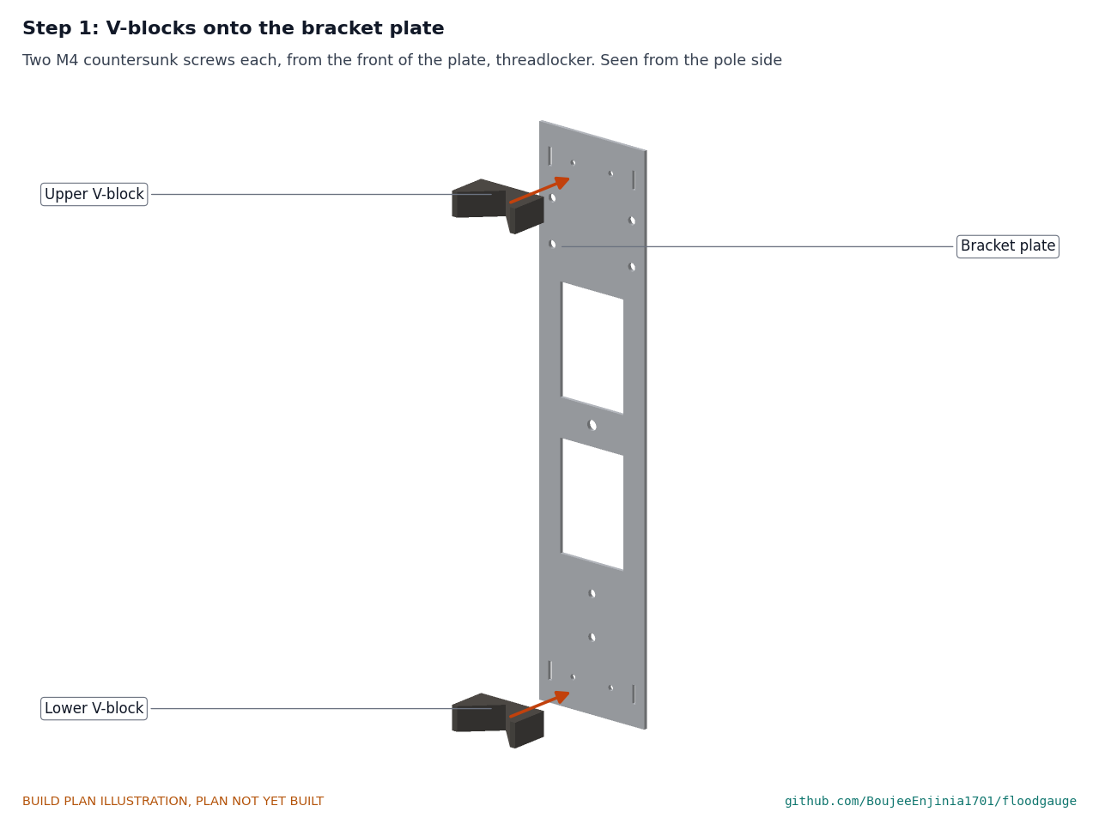
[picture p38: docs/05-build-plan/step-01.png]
Step 1


Two M4 countersunk screws per block from the front of the plate, medium threadlocker, snug. The V faces away from the plate.

### Step 2: cleats and foot clip onto the plate

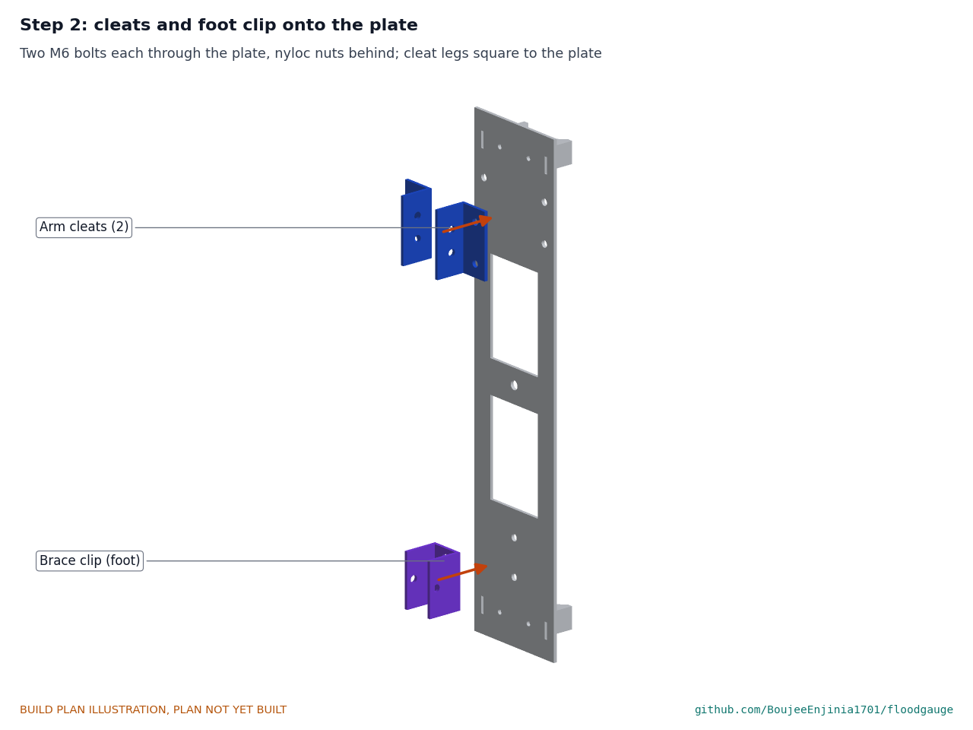
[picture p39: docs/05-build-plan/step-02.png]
Step 2


Two M6 bolts per cleat and two M6 button-head bolts in the clip, all through the plate, nyloc nuts behind. The cleats' arm legs stand 40 apart and square to the plate; the clip's ears point toward the road.

### Step 3: head plate and top clip under the arm

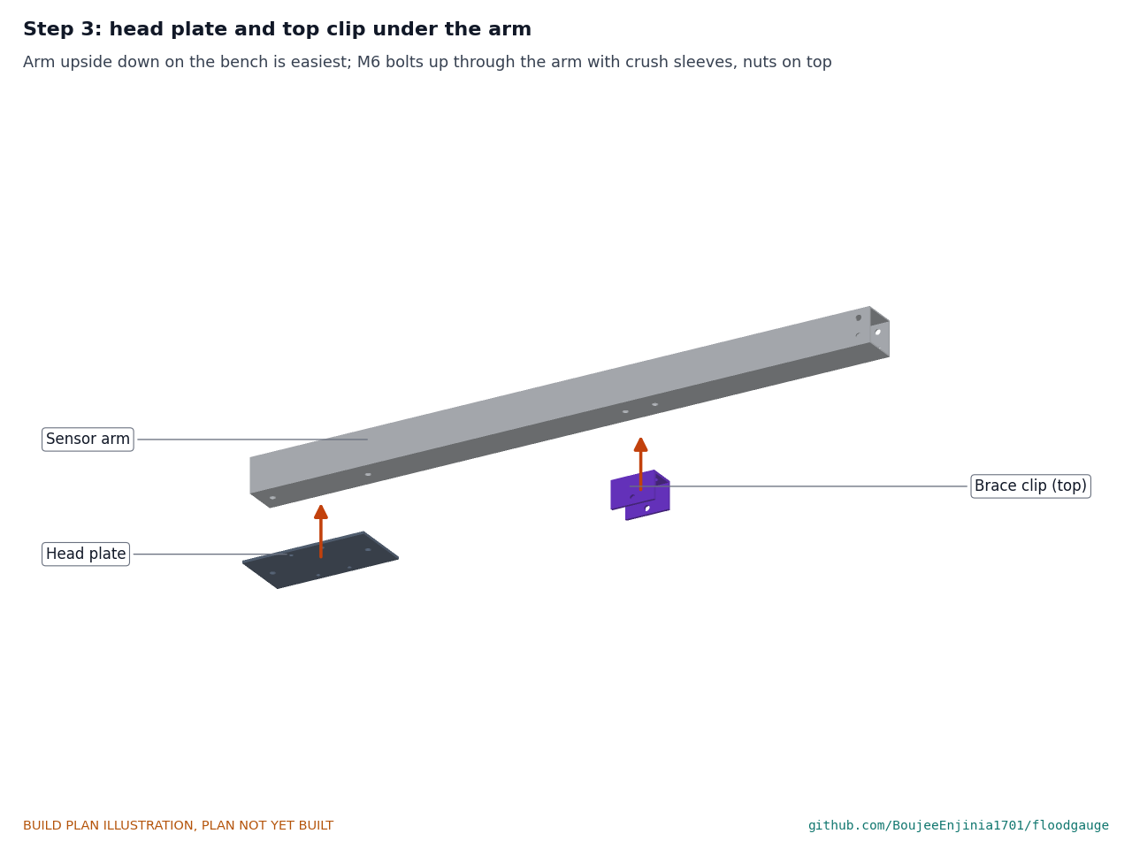
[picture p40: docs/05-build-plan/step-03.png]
Step 3


With the arm upside down on the bench, fit crush sleeves and two M6 bolts through each. Nuts on the arm's top face.

### Step 4: radar head onto the head plate

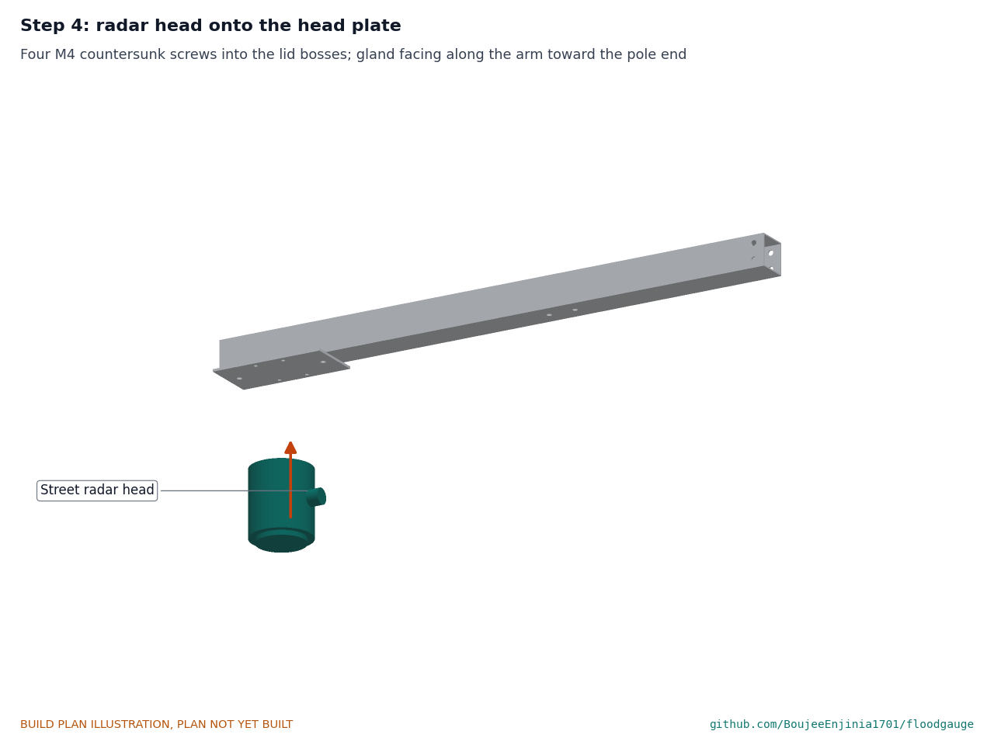
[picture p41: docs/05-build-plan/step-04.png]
Step 4


Four M4 countersunk screws into the housing's lid bosses, the gland facing along the arm toward the pole end.

### Step 5: arm between the cleats

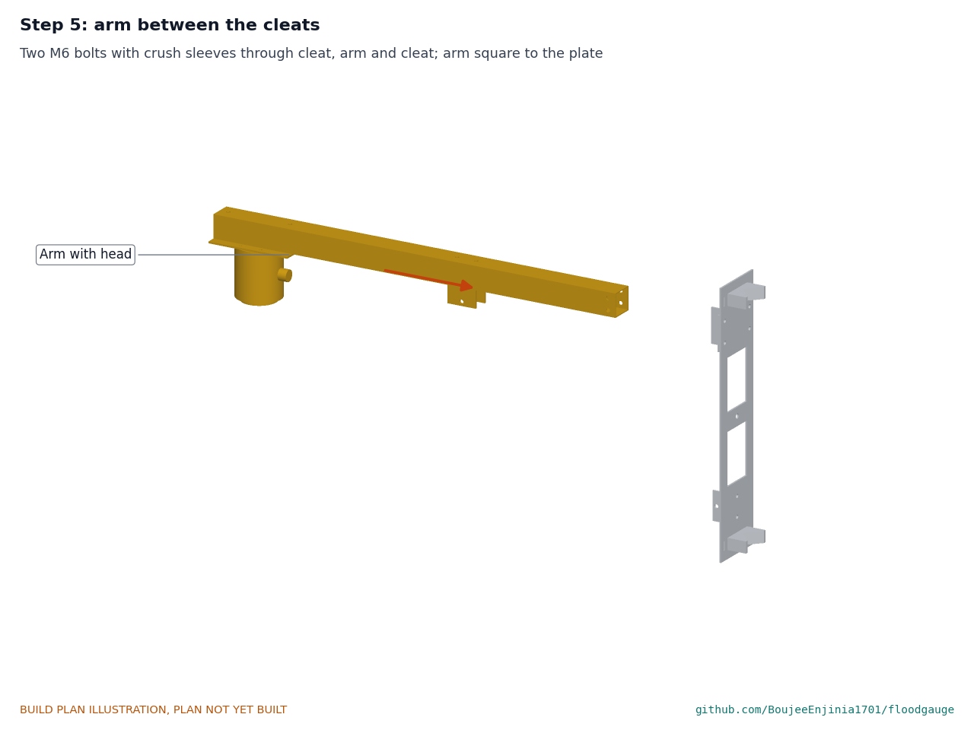
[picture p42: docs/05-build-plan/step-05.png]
Step 5


Slide the arm between the cleats until it is 2 short of the plate; two M6 bolts with crush sleeves through cleat, arm and cleat. Check the arm is square to the plate.

### Step 6: knee brace into its clips

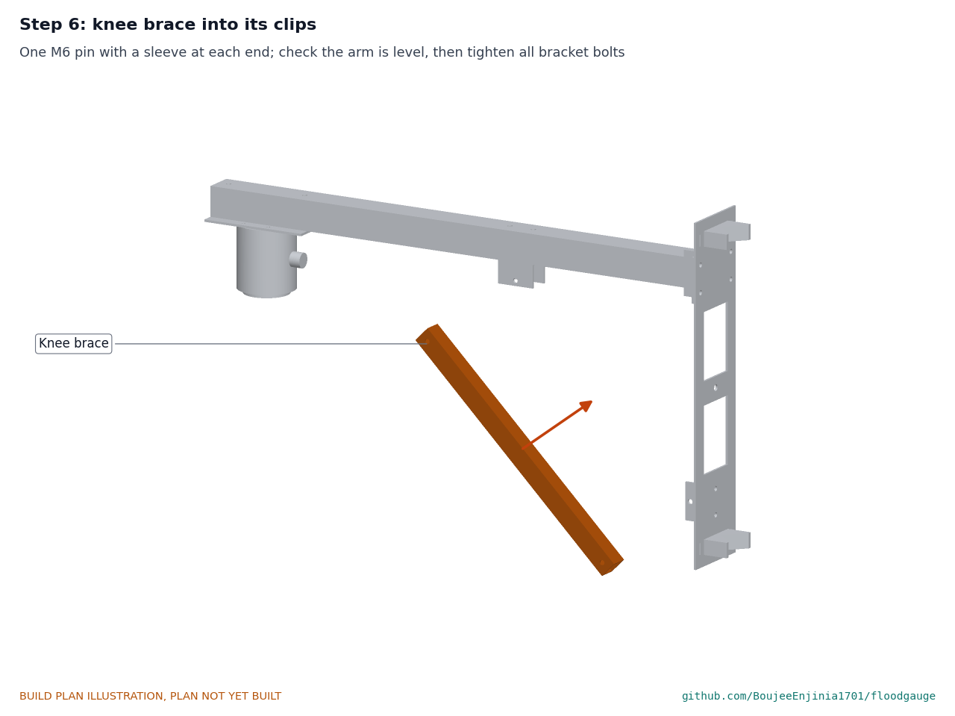
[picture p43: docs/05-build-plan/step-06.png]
Step 6


One M6 pin with a sleeve at each end. Set the arm level, then tighten every bracket bolt. **Hold point:** the assembled arm and bracket weigh about 1.7 kg; check every nut is tight before it goes up the pole.

### Step 7: FieldNode onto the pole

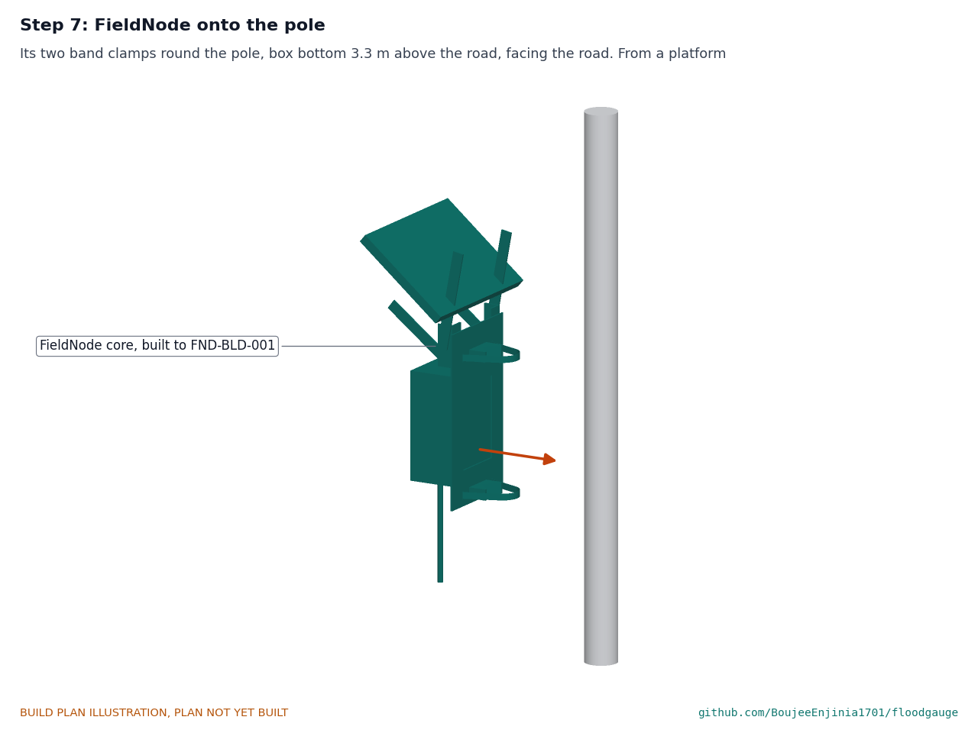
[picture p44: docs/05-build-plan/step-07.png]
Step 7


Build the FieldNode to its own plan, then from the platform fit it on the road face of the pole with its own two band clamps, the box bottom 3.3 m above the road and the lid facing the road. **Hold point:** the FieldNode plan's safety stops before its cell goes in.

### Step 8: arm and bracket onto the pole

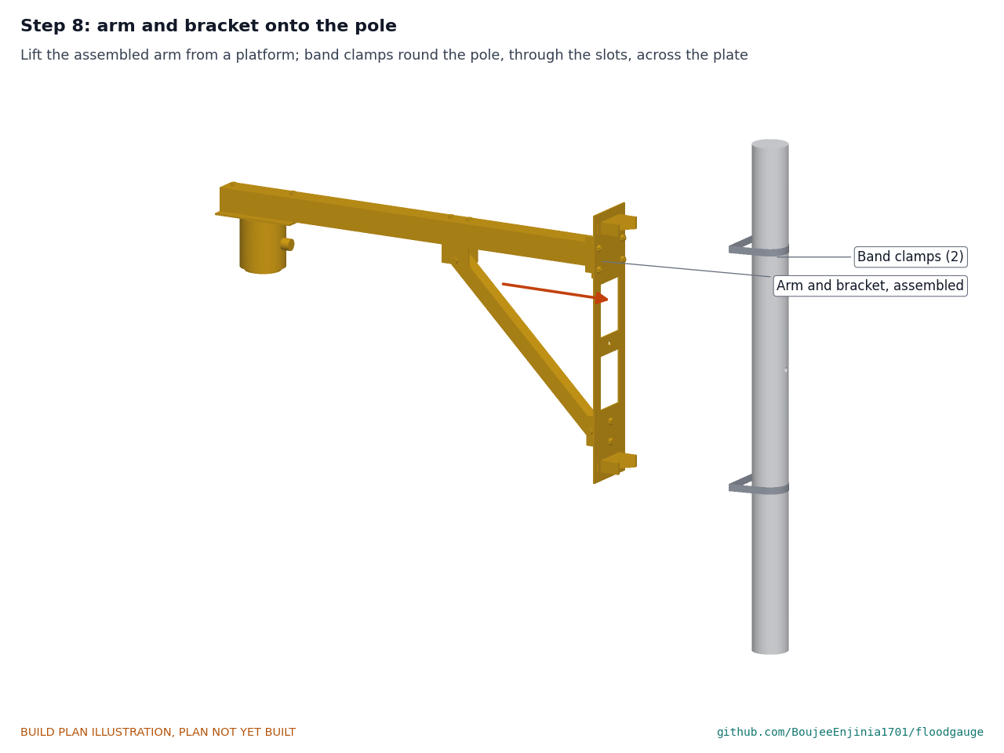
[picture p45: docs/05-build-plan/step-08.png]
Step 8


From the platform, with a helper, hold the bracket on the road face of the pole with the arm square to the curb, the lens 4,600 above the road. Pass each band clamp round the pole, through its two slots and across the plate front; tighten to the torque that gives 1,000 N.

### Step 9: anti-rotation through-bolt

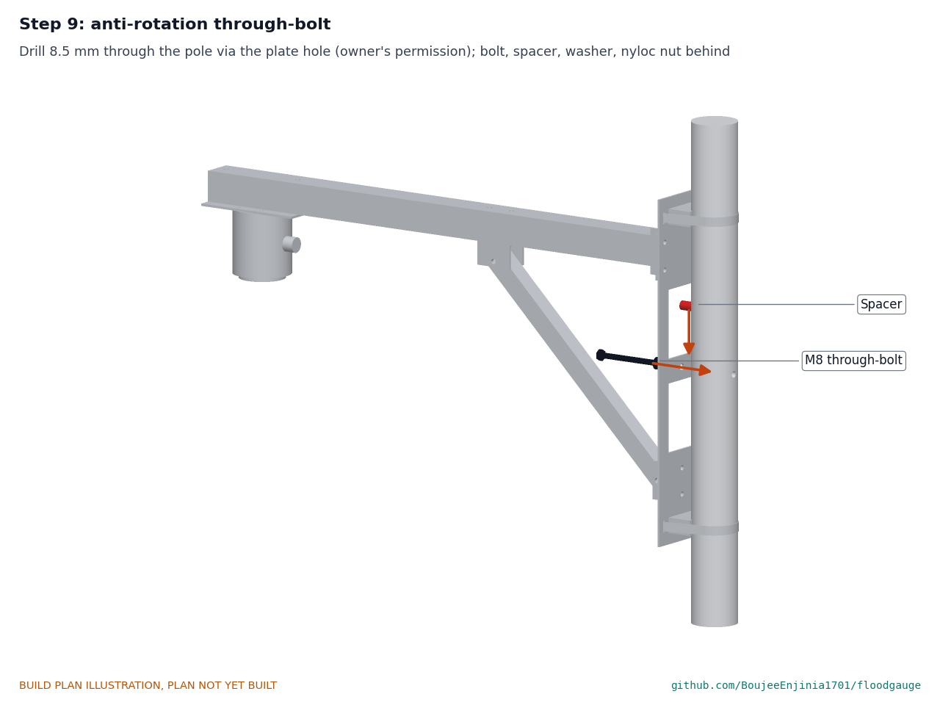
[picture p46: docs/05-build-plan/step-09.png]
Step 9


With the owner's permission, drill 8.5 mm through both walls of the pole, using the plate's centre hole as a guide. Bolt from the front through the plate, the spacer and the pole; washer and nyloc nut behind.

### Step 10: street cable to FieldNode port A

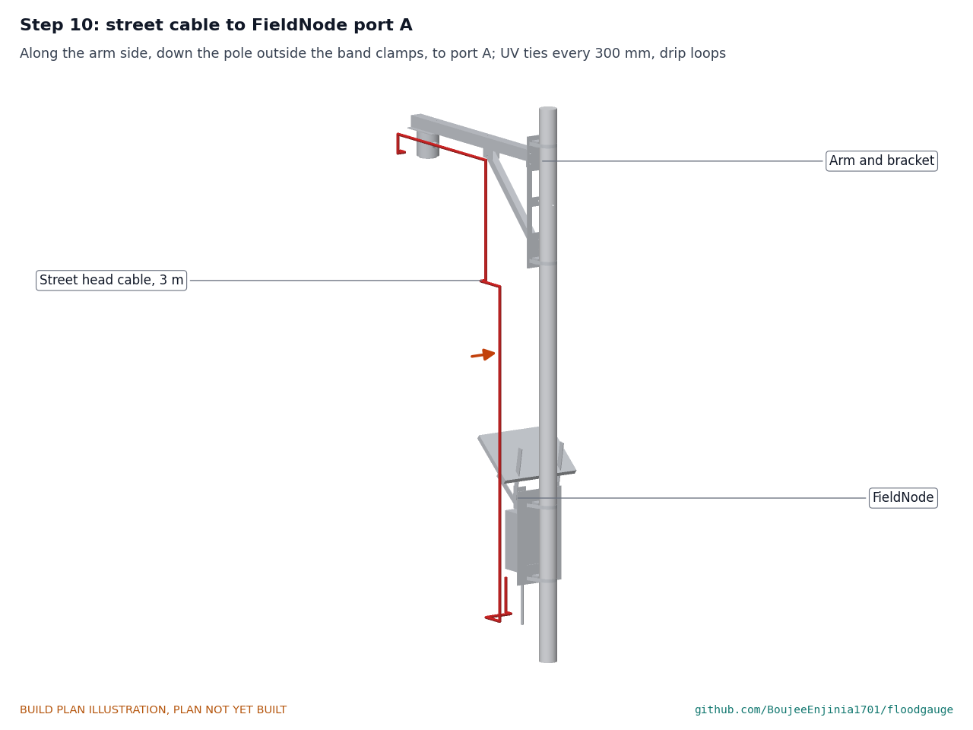
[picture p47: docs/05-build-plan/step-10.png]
Step 10


From the head's gland along the side of the arm, down beside the bracket plate, down the side of the pole outside the band clamps, round under the FieldNode box to port A. UV ties every 300 mm and a drip loop below each connector.

### Step 11: depth marker and riser guard onto the pole

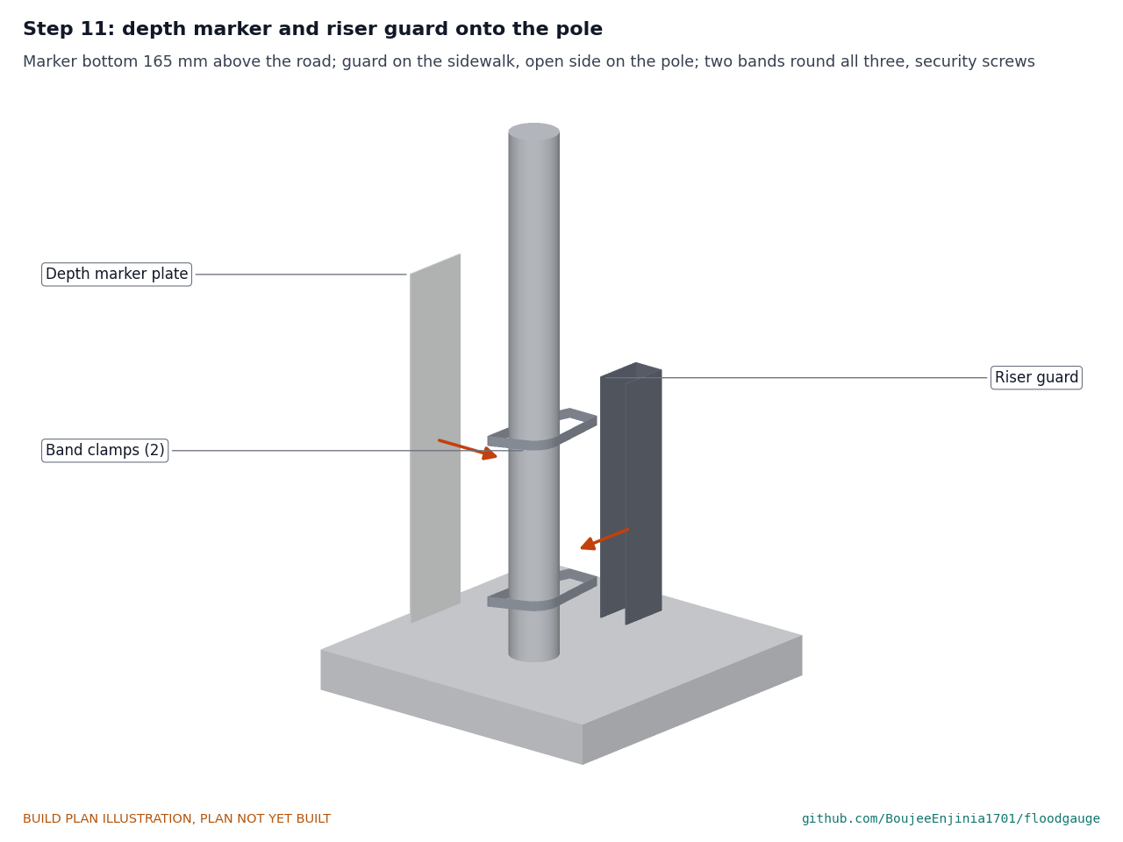
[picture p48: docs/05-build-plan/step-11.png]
Step 11


Stand the riser guard on the sidewalk beside the pole, open side to the pole, notch toward the road. Hold the marker plate on the road face with its bottom edge 165 above the road (check with a level from the road at the gutter). Two band clamps at 220 and 420 above the road round all three; close each clamp with its security screw and the pin-Torx bit.

### Step 12: pipe clamps and stilling tube into the basin

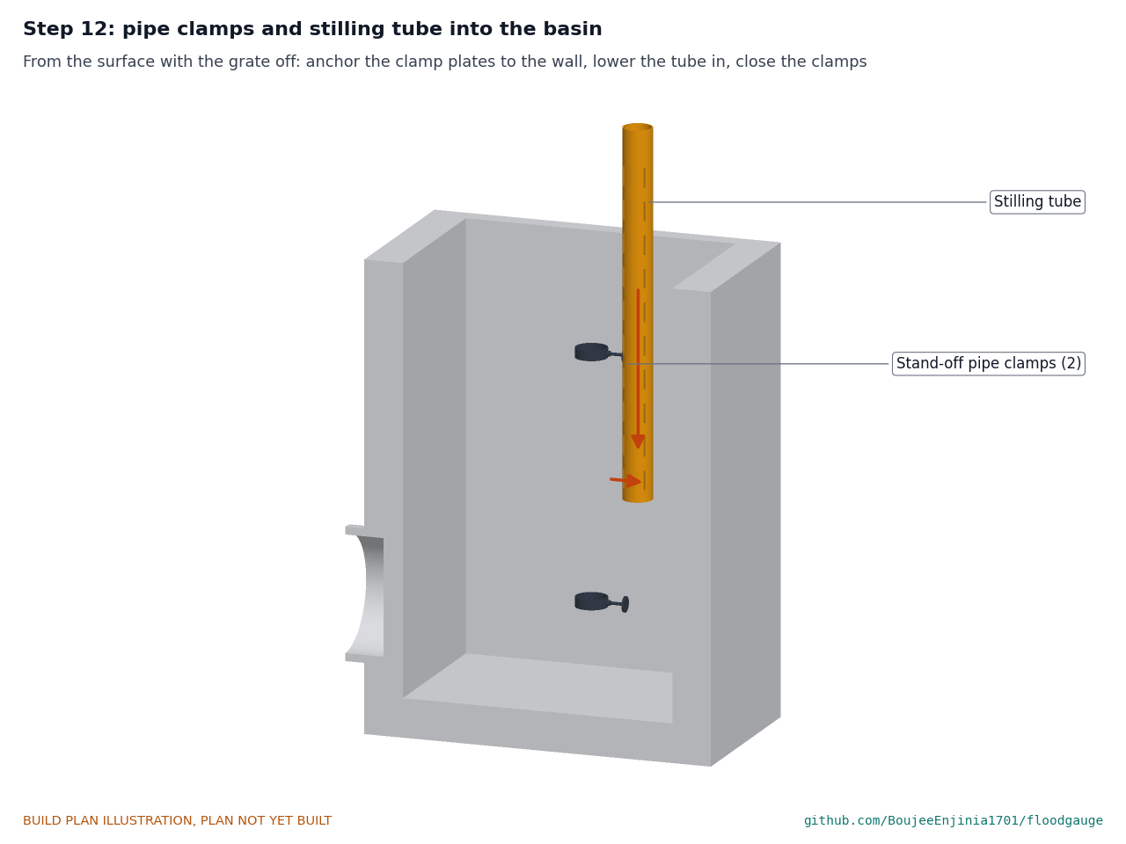
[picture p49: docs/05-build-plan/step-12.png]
Step 12


From the surface, with the grate lifted by two people with a grate hook: fit the two wall anchors and clamp plates 80 and 710 below the planned tube top, using an extension drill through the opening. Lower the tube in, close the clamps round it with its top 300 below the road. **Hold point:** safety stop S3.

### Step 13: drain head onto the tube

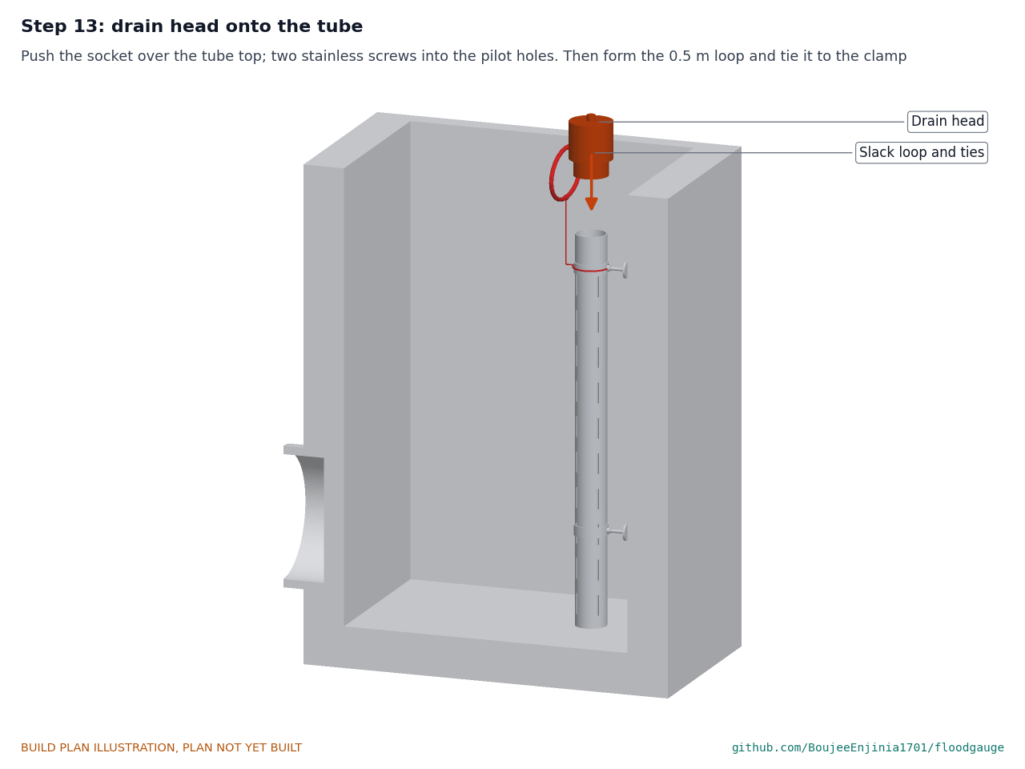
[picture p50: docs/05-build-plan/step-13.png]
Step 13


Push the socket fully over the tube top; two stainless screws into the pilot holes. Then take the drain cable from the head and make a 0.5 m slack loop, hanging beside the tube on the side away from the slots, below the grate opening. Tie the loop with one cable tie and tie it to the upper pipe clamp with a second, so the cable cannot swing into the tube or catch debris (Figure 22).

### Step 14: drain cable and the three covers

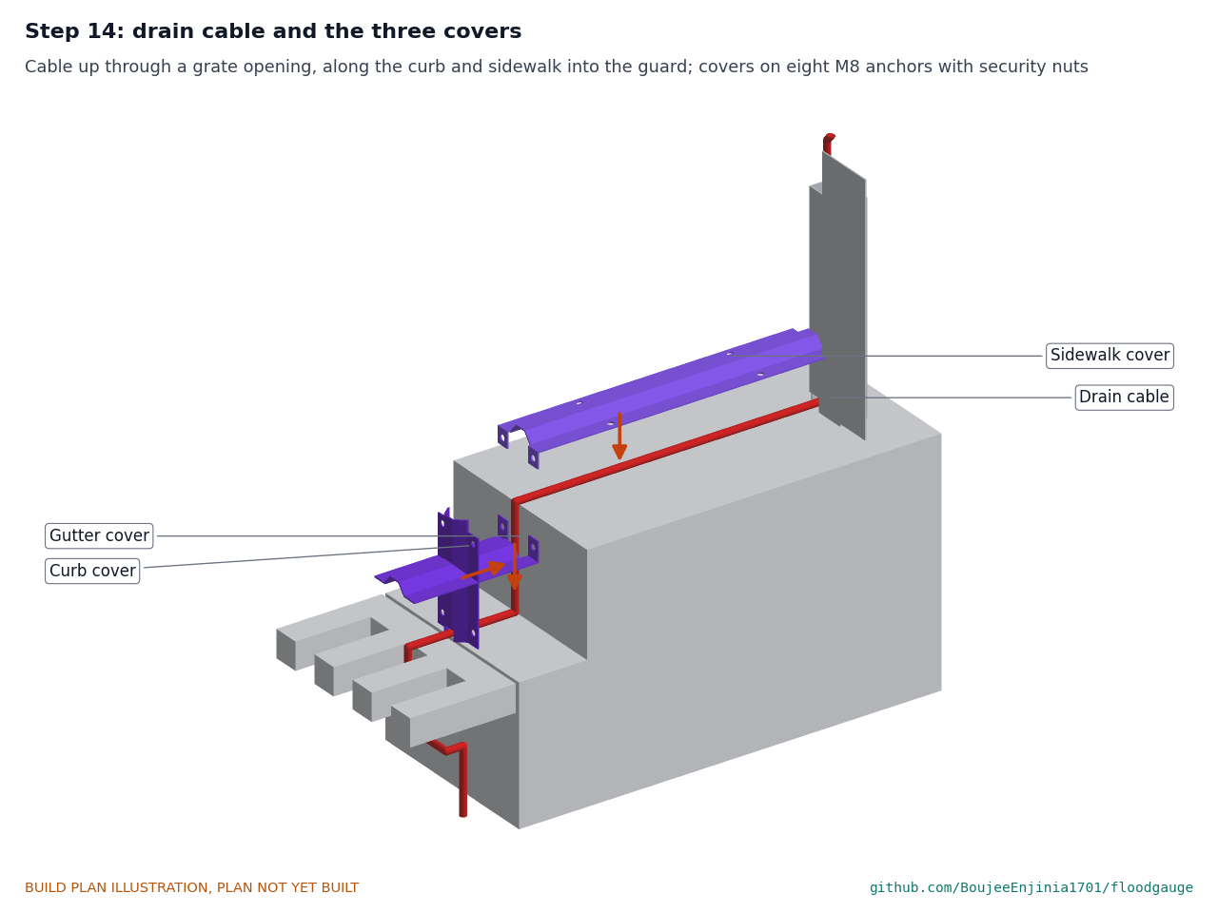
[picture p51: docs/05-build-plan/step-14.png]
Step 14


Leave the 0.5 m slack loop from step 13 hanging in the basin, tied to the clamp. Bring the cable up through the grate opening nearest the curb on the cover line, close the grate, lay the cable across the gutter strip and up the curb face and across the sidewalk into the riser guard and up the pole to port B. Fit the curb cover on four anchors (the lower two also through the gutter cover's tabs, the upper two through the sidewalk cover's tabs) and the sidewalk cover on four more, each anchor with a washer and a snake-eye security nut. **Hold point:** safety stop S4.

### Lifting the grate for cleaning

After the pilot is built, the grate is lifted for cleaning in this order, with two people, a grate hook and the open inlet guarded (safety stop S3).

1. Undo the two anchor nuts that hold the gutter cover's tabs, using the snake-eye spanner bit, and lift the gutter cover off the grate border.
2. Leave the drain cable in place; it stays threaded through the grate opening, and the 0.5 m slack loop in the basin gives it the length it needs.
3. Lift the grate with the hook and rest it clear of the opening, taking care not to pull on the cable. Nobody puts their head or body into the basin.
4. Clean the grate and the surface by hand from above. Check from above that the loop is still tied to the pipe clamp and hangs clear of the tube.
5. Set the grate back so it sits fully on its frame, refit the gutter cover and tighten both security nuts. This sequence is reviewed after the first cleaning visit.

## 5. First checks

These are the checks a TRL 4 test report would record; this plan only lists them. Requirement numbers are those of FLG-REQ-001.

*Table 2. First checks.*

| Check | Requirement | How | Pass when |
| --- | --- | --- | --- |
| Lens height | R1, R13 | Tape and level from the road surface below the head; record the dry-road radar reading | 4,600 mm, give or take 5 mm; the two agree within 5 mm |
| Arm level and square | R1 | Level on the arm; tape from the curb face to the head axis | Level within 1°; head axis 250 mm past the curb face, give or take 10 mm |
| Arm does not turn | R15 | Push the head sideways by hand with about 50 N | No movement at the bracket |
| Mass on the pole | R15 | Weigh each assembly before it goes up | 5.0 kg or less in all (4.99 kg estimated) |
| Street depth on a target | R2 | Hold a flat board level at 150 and 300 mm above the road under the head | Reads within 10 mm |
| Drain level on a target | R3, R4 | Lower a float plate in the tube to 3 levels with the head lifted onto a test stand | Reads within 20 mm |
| Wet probe | R3 | Wet the probe pins | Drain-full signal |
| Cable covers | R12 | Walk and step on the sidewalk cover; run a hand along every edge | No edge more than 2 mm proud; nothing moves |
| Installation time | R12 | Time the site steps with a two-person crew | 120 min or less on the pilot surface route (120 min estimated) |

## 6. Safety stops

Stop at each point. Carry on only when everything listed is true.

- **S1. Before any site work.** Permission from the pole and road owner; traffic and pedestrian management in place; the platform inspected; overhead lines located and clear by the owner's distance; a second person present.
- **S2. Before drilling the pole.** Written permission to drill it; the pole is not live (no internal wiring at the drill height); eye protection.
- **S3. Before lifting the grate.** Two people and a grate hook; the open inlet guarded; nobody puts their head or body into the basin; gloves and eye protection for stormwater; no work in rain or with water flowing.
- **S4. Before leaving the site.** Every band clamp, bolt and anchor nut tight; the grate seated; the sidewalk cover flat and marked; the FieldNode's own safety stops passed; the gauge reporting to the alert service.
- **S5. Lithium cell.** The FieldNode's cell rules apply in full (fused, charged only between 0 and 45 °C, never a swollen or wet cell).

## 7. Tools, skills and workspace

**Tools.** Hacksaw or bandsaw; bench vice with soft jaws; bench drill or drill stand; drills 3 to 10 mm and an 8.5 mm long-series drill; 46 mm hole saw; countersink; M4 tap and tap drill; jigsaw with metal blade; files; deburring tool; scriber, square, 45° square, steel rule and calipers; sheet folder (or hardwood blocks in the vice) for 2 and 3 mm sheet up to 100 wide; angle grinder with cutting disc; hammer drill and 8 mm masonry bit with an extension; torque wrench; spirit level and 5 m tape; grate hook; a snake-eye spanner bit (for the security nuts on the cover anchors) and a TR25 pin-Torx bit (for the marker band clamp screws); soldering iron, crimper and multimeter for the heads; PVC cement.

**Skills.** No certified trade for the workshop part: marking out, sawing, drilling, filing, tapping, folding sheet, light soldering and potting. Site work needs people trained for work beside traffic and on a mobile elevating platform, as local rules require.

**Workspace.** A bench about 1.5 x 0.6 m with a vice; a ventilated corner for PVC cement and potting; at the site, the traffic-managed area round the pole and the inlet.

**Personal protective equipment.** Safety glasses, cut-resistant gloves, hearing protection when cutting; at the site high-visibility clothing, a helmet, a harness on the platform, and waterproof gloves near stormwater.

## 8. Where the numbers come from

- Model and constructability checks: `cad/src/model.py` (`python cad/src/model.py --check`, 110 checks); STEP and STL exports in `cad/step/` and `cad/stl/`.
- Pictures: `cad/src/build_plan_media.py`, using `.kit/build_views.py`; written to `docs/05-build-plan/` and `cad/drawings/FLG-DWG-101` to `FLG-DWG-116`.
- General arrangement: `cad/drawings/FLG-DWG-001.pdf`, Rev P4.
- Calculations: `docs/04-calcs/01-sizing.md` (FLG-CAL-001 v0.4) and `docs/04-calcs/sizing.py`; arm and bracket [H1] to [H5], mass [I1], [I2], cables [J1], [J2].
- Bill of materials: `bom/bom.csv`.
- Decisions: `docs/decisions/0003-design-for-construction.md` (FLG-DDR-003), with FLG-DDR-001 and FLG-DDR-002; register `docs/06-design-decisions.md` (FLG-DEC-001).
- Requirements: `docs/03-requirements.md` (FLG-REQ-001 v0.6).
- FieldNode: the FieldNode repo's build plan FND-BLD-001.

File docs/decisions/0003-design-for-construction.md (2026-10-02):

---
doc_id: FLG-DDR-003
title: FloodGauge design for construction
project: FloodGauge
doc_type: Design decision record
version: "0.2"
status: Draft
date: '2026-10-02'
author: Amish Chadha
license: CERN-OHL-S-2.0
revisions:
- version: "0.1"
  date: '2026-10-01'
  author: Amish Chadha
  change: Changes that make the concept physically buildable, with the reason for each; made under Amish's 2026-09-30 instruction to make the design physically buildable; open for his review
- version: "0.2"
  date: '2026-10-02'
  author: Amish Chadha
  change: "Accepted by Amish on 2026-10-02 (Tables 1 to 3); record stays Draft"
---

# 0003: Design for construction

- **Date:** 2026-10-01
- **Status:** Draft. The changes in Table 1 and Table 2 were made under Amish's 2026-09-30 instruction to make the design physically buildable. Nothing here changes what FloodGauge does, its pitch or its safety case. Accepted by Amish on 2026-10-02: "i approve your recommendations for all 555 open decisions." This covers every change in Tables 1 and 2 and the recommendations in Table 3 (A1 and A2), recorded in the design decisions register (FLG-DEC-001, items 1 to 4). The record stays Draft.

## Context

On 2026-09-30 Amish asked for every repo's build plan to show how each component is made and how it fits the next, with pictures, and wrote: "If you are realising that the design cannot be built as per concept - fix the design assumptions to match and be physically feasible as you draw the illustrations." The TRL 3 model of FLG-DDR-002 showed what FloodGauge does, but checking it with build123d (overlap volumes and gaps between parts) found parts that pass through each other, parts with no fixing and a cable route that cannot be laid. The changes below keep what the gauge does: the same two heads, the same lens height of 4.6 m and 250 mm past the curb face, the same stilling tube, drain head height and reading range, the same surface cable route for pilots and the same anti-rotation through-bolt, alert bands and data path.

Every change is in `cad/src/model.py`, which now runs 110 constructability checks (`python cad/src/model.py --check`): parts that must touch do touch, and parts that must not touch are apart by at least the stated clearance. All 110 pass.

## Decision

*Table 1. Changes made to the model, the BOM and the calculations.*

| # | Problem in the concept (measured on the model) | Change made | Why this way |
| --- | --- | --- | --- |
| P1 | The 40 mm square arm ran straight through the 60 mm pole (15,515 mm³ of overlap) and 40 mm past its far side; the upper clamp ring overlapped the arm (5,174 mm³); the two clamps were plain rings 0.5 mm off the pole with no way to tighten them. | A pole bracket: an aluminium plate 3 x 100 x 450 mm on two V-blocks (the FieldNode V-block, 60 x 33 x 20 mm with a 90° V), held by two 12 mm stainless band clamps 400 mm apart that pass round the pole, through slots in the plate and across its front. The arm stops 2 mm short of the plate and is held between two 30 x 30 x 3 mm angle cleats: two M6 bolts through each cleat and the plate, two M6 bolts with crush sleeves through cleat, arm and cleat. The arm is now 715 mm long (was 805 mm). | The FieldNode V-block and band pattern is already in the lab's build plans, seats poles of 40 to 71 mm and needs no welding. The band spacing of the concept (400 mm) is kept. |
| P2 | The knee brace touched the arm with 663 mm³ of overlap at its top and stopped 6.7 mm short of the lower clamp: it had no fixing at either end. | A 25 x 25 x 1.6 mm tube, 382 mm long, pinned at each end by one M6 bolt and sleeve between the ears of a folded clip: one clip under the arm (two M6 bolts up through the arm), one on the bracket plate (two M6 bolts through the plate). The pins are 358 mm apart at 45°. | Two identical clips folded from 3 mm strip. A pinned brace carries only push and pull, which is what the calculation assumes. |
| P3 | The M8 anti-rotation through-bolt ran along the street through the lower band clamp and the pole. A worm-drive band has no material that can take a bolt. | The M8 bolt runs across the street, through the bracket plate, a 20.2 mm aluminium spacer and both walls of the pole, half way between the bands, with a nyloc nut behind the pole. It is now M8 x 100 mm (was M8 x 110 mm). | The bolt still pins the bracket to the pole; the couple across the pole and the twist factor of 37 are unchanged [H2b]. The spacer stops the plate bending when the bolt is tightened. |
| P4 | The head saddle (a 70 x 50 x 40 mm block under the arm) sat inside the top 40 mm of the radar housing (125,252 mm³ of overlap). | A 140 x 70 x 3 mm head plate bolted under the arm (two M6 bolts up through the arm); the housing hangs from it on four M4 countersunk screws into its lid bosses. The arm centre rises 3 mm, to 4,713 mm, so that the lens stays at 4,600 mm. | The lens height is the depth datum and must not move. |
| P5 | The street cable left the top of the head straight up through the arm wall (800 mm³ of overlap). | An M12 gland on the side of the housing facing the pole. The cable runs along the side of the arm, drops beside the bracket plate, runs down the pole outside the band clamps and goes to port A under the FieldNode box, tied every 300 mm. | The side gland was already proposed in the appearance model (REVIEW, 2026-09-26, item 3). |
| P6 | FieldNode was drawn as a box on a 12 mm plate in line contact with the pole with no fixing, and its panel floated 35 mm above it with no bracket. | FieldNode is its constructable design (FND-BLD-001): a 3 mm back plate on two V-blocks and two band clamps, the box on lugs, and the 6 W panel on its own bracket at 40° (the concept drew 25°). It faces the road. The node centre rises from 3.0 m to 3.4 m above the road. | Measured along the real route (along the arm, down the pole outside the bands and up to port A on the underside of the box), the street cable at 3.0 m needed 3.04 m, 3.34 m with drip loops, more than the 3 m cable that keeps the I2C bus under 400 pF. At 3.4 m the run is 2.64 m, 2.94 m with loops [J1]. The 5 m drain cable still fits (4.83 m with loops) [J2]. |
| P7 | The drain cable was drawn leaving the basin "at the grate frame". The grate sits 5 mm from its frame, too narrow for a 10 mm cable, and the drawn cable passed through 4,712 mm³ of the road slab. | The cable comes up through the grate opening nearest the curb, 165 mm from the curb face and 80 mm along the street from the inlet centre, inside the gutter cover. | No drilling of the road, the grate or its frame, as the surface route intends. |
| P8 | The surface cover was an angle drawn as flat boxes with no fixing; the riser guard stood on the sidewalk 250 mm along the street from the pole (160 mm from it), and the drain cable went up the far side of the pole 233 mm from the guard, unconnected. | Three hat-section covers bent from 2 mm galvanized strip, 84 mm wide and 16 mm high: a gutter cover lying across the gutter strip and onto the grate border, with two tabs up the curb face; a curb cover on the curb face with four M8 masonry anchors; a sidewalk cover with four anchors and two tabs down the curb face that share the curb cover's upper anchors. The riser guard is a 40 x 65 x 2 mm steel U channel, 300 mm tall, standing on the sidewalk with its open side on the pole, and the cable runs inside it and on up the pole to port B. | One section shape for all three covers. Anchors stay in the curb and sidewalk only (FLG-DDR-002). The guard is held by the marker's two band clamps, so it needs no anchor. |
| P9 | The two stilling tube brackets were set 10 mm into the basin wall (24,000 mm³ of overlap). | Two bought stainless stand-off pipe clamps for 75 mm pipe, each with an M8 rod to a wall plate and one wall anchor, 80 and 710 mm below the tube top. | Bought, adjustable, fitted from the surface with the grate off, as FLG-CAL-001 L1 already allowed for. |
| P10 | The drain head sat on the tube top with no fixing. | A 75 mm PVC socket coupling, 40 mm long, solvent-welded under the head; the tube top slides into it up to the head, and two stainless screws hold it. | The head lifts off for cleaning after two screws. The transducer face stays 300 mm below the road. |
| P11 | The depth marker plate stood flat on the round pole with no fixing; the new sidewalk cover would have run under its bottom edge. | A 2 mm plate (was 3 mm), 90 x 435 mm, with its bottom edge 165 mm above the road (15 mm above the sidewalk), held by two band clamps round the pole, the plate and the riser guard. The amber band shows from the bottom edge to 300 mm. | The sidewalk cover passes under the plate; the plate and the guard share two clamps. The thinner plate helps hold the mass requirement. |

*Table 2. Knock-on changes.*

| Item | Change | Reason |
| --- | --- | --- |
| Mass | Arm wall 2.0 to 1.6 mm, brace wall 2.0 to 1.6 mm, two 60 x 90 mm windows in the bracket plate. Mass on the pole 4.99 kg (was 4.74 kg), 0.01 kg under R15's 5.0 kg [I2]. The riser guard and the covers (2.00 kg) stand on the sidewalk and are not carried by the pole. | The bracket, clips, cleats, bolts and the FieldNode's constructable design (2.45 kg, was 2.41 kg) added mass. In the 50 kg misuse case the 1.6 mm arm is stressed to 60 MPa (factor 3.6) and the brace carries 1,504 N against a buckling load of 73,043 N [H3]. |
| Loads | Arm pull at the cleats in the misuse case 1,063 N against 2,000 N band capacity (factor 1.9) [H4]; M6 joints and pins at least 11 times the load [H5]. | New load path through the bracket. |
| Cost | BOM lines 3, 4, 5, 7 and 8 repriced; line 1 follows FieldNode's constructable design ($139.00). FloodGauge-specific parts $190.50 (was $153.50) against the value-engineering target of $160: $30.50 over the target. Complete gauge $329.50 [M1]. | Parts added for construction. |
| Drawing | FLG-DWG-001 Rev P4; making sketches FLG-DWG-101 to 116 added. | Follows the model. |
| Documents | FLG-CAL-001 v0.4, FLG-REQ-001 v0.6, FLG-PRC-001 v0.6. R16 is now reported against the value-engineering target. No other requirement changes status. | Follows the model. |
| Unchanged | Lens height and offset, depth error budget, drain reading range and error, tube hydraulics, energy, airtime, latency, false-reading rules, twist factor, installation time (120 min, R12 still not met). | |

*Table 3. Proposed, then accepted by Amish as recommended on 2026-10-02 (FLG-DEC-001, items 3 and 4).*

| # | Question | Options | Recommendation |
| --- | --- | --- | --- |
| A1 | The R15 mass margin is now 0.01 kg on estimated masses. | (a) accept and weigh the prototype at TRL 4; (b) lighten further now, for example a 2.5 mm bracket plate. | (a). Accepted 2026-10-02, with the 2.5 mm bracket plate named as the fix if the weighed prototype is over 5.0 kg. |
| A2 | Lifting the grate for maintenance: the drain cable passes through a grate opening and the gutter cover rests on the grate border. | (a) undo the gutter cover's two anchor nuts and lift the grate with the cable still threaded, using a 0.5 m slack loop left in the basin; (b) add an inline M12 joint at the foot of the riser guard so the cable can be unplugged. | (a) for the pilot; decide after the first cleaning visit. Accepted 2026-10-02, with the slack loop tied to the stilling tube clamp so it cannot catch debris. |

## Consequences

- `design_state: constructable` in `project.yaml`. The build plan FLG-BLD-001 shows every component and step in pictures generated from the model (`cad/src/build_plan_media.py`).
- Requirement status: 1 not met (R12), 3 at risk (R7, R9, R14), 1 not verifiable at TRL 3 (R10), 8 met on paper, 3 met by design; R16 is over the value-engineering target by $30.50 (FLG-CAL-001 v0.4). With R12 relaxed to 120 min for the pilot surface route on 2026-10-02 (FLG-DEC-001, item 5), R12 is met on paper and none is not met (FLG-CAL-001 v0.5).
- The photoreal renders (`media/render-*.png`), `media/card.png`, `media/social-preview.png` and the appearance model `cad/src/product_model.py` still show the concept arm, saddle, cover and node height; they need updating on Amish's Mac.
- The FieldNode repo is not edited. FloodGauge uses its constructable design on a 60 mm pole, which needs band clamps of about 330 to 380 mm round instead of FieldNode's 230 to 280 mm.

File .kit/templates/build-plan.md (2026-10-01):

---
doc_id: PRJ-BLD-001
title: Project prototype build plan
project: Project name
doc_type: Build plan
version: "0.1"
status: Draft
date: YYYY-MM-DD
author: Amish Chadha
license: CERN-OHL-S-2.0
revisions:
  - version: "0.1"
    date: YYYY-MM-DD
    author: Amish Chadha
    change: First build plan; design made constructable
---

# Project prototype build plan

**Plan, not yet built.** How to build the first proof-of-concept prototype, component by component. Building and testing to it is TRL 4 work. Decisions still to be made are kept in the design decisions register (`docs/06-design-decisions.md`), not here.

## 1. What you are building

Every component, pulled apart and numbered in build order

One short paragraph: what the prototype is, how many components, which are made and which are bought, and the main ways they are made.

## 2. What changed to make it buildable

| Component | The concept had | The buildable design has | Why |
| --- | --- | --- | --- |

## 3. Making the components

### 3.1 Component name

Making sketch

**What it is and what it is made from.**

**How to make it.**

1. Mark out ...
2. Cut ...

**How it fits the parts next to it.**

Close-up of the joint

**Check before moving on.**

## 4. Putting it together

### Step 1: ...

Step 1

## 5. First checks

| Check | Requirement | How | Pass when |
| --- | --- | --- | --- |

## 6. Safety stops

## 7. Tools, skills and workspace

## 8. Where the numbers come from

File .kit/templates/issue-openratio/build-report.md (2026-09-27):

---
name: Build report
about: Tell us what happened when you built, printed or tested part of this design
title: "Build report: "
labels: build-report
---

This is a research and educational prototype, not a medical device. It is a TRL 3 concept and is not released for fabrication. If you build any part of it, you do so at your own risk. Reports help everyone.

**What you built** (part, sub-assembly or test)

**Materials, tools and settings**

**What worked**

**What did not work, with photos or measurements if you have them**

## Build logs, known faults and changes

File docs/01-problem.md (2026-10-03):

---
doc_id: FLG-PRB-001
title: FloodGauge problem statement
project: FloodGauge
doc_type: Problem statement
version: "0.6"
status: Draft
date: '2026-10-02'
author: Amish Chadha
license: CERN-OHL-S-2.0
revisions:
- version: "0.1"
  date: '2026-09-25'
  author: Amish Chadha
  change: Initial scaffold
- version: "0.2"
  date: '2026-09-25'
  author: Amish Chadha
  change: Populate to TRL 2 (users, context, constraints, prior work, open questions)
- version: "0.3"
  date: '2026-09-25'
  author: Amish Chadha
  change: TRL 3 update; budget treatment and design direction per FLG-DDR-001 (adopted for TRL 3 pending Amish's review); open questions updated from FLG-CAL-001
- version: "0.4"
  date: '2026-09-26'
  author: Amish Chadha
  change: Budget approved by Amish ($160)
- version: "0.5"
  date: '2026-10-02'
  author: Amish Chadha
  change: "Open questions on the pilot partner and alert ownership answered by Amish's 2026-10-02 decisions"
- version: "0.6"
  date: '2026-10-02'
  author: Amish Chadha
  change: "Cost and FieldNode figures brought into line with FLG-CAL-001 v0.6 (USD 205.50; FieldNode USD 139.00)"
---

# FloodGauge problem statement

Urban flash floods rise in minutes, and warnings rely on river gauges far from the streets that flood. The people most at risk, drivers entering an underpass, residents of basement homes and crews clearing blocked drains, need a reading from their own street, not from a river several kilometers away.

## The problem in numbers

- About 1.81 billion people, 23 % of the world's population, are directly exposed to 1-in-100-year floods, and 89 % of them live in low- and middle-income countries ([Rentschler, Salhab and Jafino, 2022](https://www.nature.com/articles/s41467-022-30727-4)).
- Shallow water is enough to kill. The US National Weather Service states that 150 mm (6 in) of fast-moving water can knock over an adult, 300 mm (12 in) of rushing water can carry away most cars, and over half of flood drownings happen when a vehicle is driven into flood water ([NWS](https://www.weather.gov/safety/flood-turn-around-dont-drown)).
- Only 108 countries, 55 % of the total, reported multi-hazard early warning systems in 2024, and countries with limited coverage had disaster mortality nearly six times that of countries with substantial coverage ([UNDRR and WMO, 2024](https://www.undrr.org/reports/global-status-MHEWS-2024)).

Street flooding has two common causes, and a useful gauge must see both:

1. **The drain backs up.** Rain exceeds pipe capacity, or the outfall is submerged, so water rises inside the catch basin and then out through the grate.
2. **The inlet is blocked.** Leaves, litter or sediment cover the grate, so water ponds in the gutter while the basin below stays nearly empty.

A sensor inside the basin sees the first case early and misses the second. A sensor over the gutter sees the second but only once water is already on the street. FloodGauge therefore uses one node with two ranging heads (FLG-DDR-001 D2, adopted for TRL 3 pending Amish's review; see FLG-PRC-001).

## Users and context

| User | Need | Setting |
| --- | --- | --- |
| Drainage and public works crews | Know which inlets are blocked or surcharging, in time to clear them or close a road | Municipal depots, on-call staff with phones |
| Emergency managers | Street-level depth and rate of rise to decide road closures and warnings | City or district emergency operations |
| Residents, especially of basement and ground-floor homes | A plain local warning when water on their street passes a set depth | Opt-in text message or public map |
| Community groups and schools | Open local data to argue for drainage upgrades and to learn | Neighborhood associations, universities |
| Planners and researchers | A record of where and how often streets flood | Open data portals |

Operating context (assumed, to be confirmed with partners):

- Mounted on an existing sign or light pole within about 1 m of a storm inlet, with the owner's permission.
- Outdoor, -20 to 50 °C air, direct sun, driving rain, road spray, vandalism and theft risk.
- No mains power at the pole; solar through FieldNode.
- LoRaWAN coverage from a city network, a community gateway such as TwinKit, or The Things Network.

## Constraints

- Garage-buildable prototype: FloodGauge-specific parts within the $160 USD budget in `project.yaml` (approved by Amish on 2026-09-26), with the shared FieldNode core ($139.00) costed in its own repo (FLG-DDR-001 D1, adopted for TRL 3 pending Amish's review). FLG-CAL-001 gives $205.50 (USD 45.50 over the $160 target).
- Builds on the lab's FieldNode core for enclosure, power and radio, so FloodGauge designs only its sensing heads, mounting and alert logic.
- Levels only: no camera, no microphone, no images or audio leave the device.
- No drilling of the road surface; any work in the catch basin is done from the surface without entering it.
- Open licenses: CERN-OHL-S-2.0 for hardware, MIT for software.
- Not a replacement for official warnings. It supplements them.

## Prior work

- **FloodNet, New York City.** Researchers at New York University and the City University of New York run a street flood sensor network whose sensors use an ultrasonic range finder over the street, sample every minute and publish near real-time data ([FloodNet methodology](https://www.floodnet.nyc/methodology)). The project reached 250 sensors in 2024, and the NYC Department of Environmental Protection commissioned 500 ([FloodNet](https://www.floodnet.nyc/about)). Its build repository describes solar power, LoRaWAN, a sign-post mount and a sensor cost below $200 per unit, and its designs are published under CC BY-NC-SA 4.0 ([floodnet-nyc/flood-sensor](https://github.com/floodnet-nyc/flood-sensor)). FloodNet shows the approach works at city scale. Its non-commercial license means FloodGauge is an independent design, not a derivative.
- **Low-cost waterproof ultrasonic rangers.** Modules such as the DFRobot A02YYUW (3 to 450 cm, ±1 cm, IP67, 60° beam) cost about $16 ([DFRobot](https://www.dfrobot.com/product-1935.html)). Their wide beam and temperature sensitivity shape the design choices in FLG-PRC-001.
- **60 GHz pulsed coherent radar modules.** Acconeer's A121 sensor and XM125 module range up to 20 m in an 18.6 x 15 mm module ([Acconeer](https://www.acconeer.com/products/)). Radar ranging does not depend on air temperature, unlike ultrasound.

## Out of scope at this stage

- River, canal or coastal gauging.
- Flow or velocity measurement.
- Rainfall measurement and flood forecasting models.
- Automatic road barriers or pump control.

## Open questions

- [ ] Which alert depths do local crews and residents want? The default 150 mm and 300 mm bands follow NWS guidance but are not validated locally; in a fast flood the first alert arrives at about 190 to 250 mm (FLG-CAL-001).
- [x] Who owns the alert service and the duty to act on an alert? Decided by Amish, 2026-10-02: the partner city's emergency management office; FloodGauge publishes levels and band crossings only.
- [ ] Can a cable be run from the catch basin to the pole, or does the drain head need its own node?
- [ ] Is an arm over the gutter allowed by the road authority, and at what height? At 2.95 m it is inside the envelope of a 4 m truck at the curb (FLG-CAL-001).
- [x] Which pilot partner and city? Decided by Amish, 2026-10-02 (FLG-DDR-001 O1): a city or county flood agency with street flooding at grated curb inlets and an existing gauge or alert programme; the first candidate type to approach is a county flood control district such as the Harris County Flood Control District in Houston. Nothing is agreed.
- [ ] What does the pilot city's LoRaWAN coverage look like at street level near inlets?

## User research and co-design

This design is for communities the author is not part of, so requirements come from the people who will use it.

- [ ] Identify a local partner organization (Helpful Engineering network, NGO or university)
- [ ] Run co-design sessions with intended users; record who, where and what was learned
- [ ] Validate load, distance, terrain and cost assumptions in the field
- [ ] Revise requirements (REQ) from findings before freezing the design

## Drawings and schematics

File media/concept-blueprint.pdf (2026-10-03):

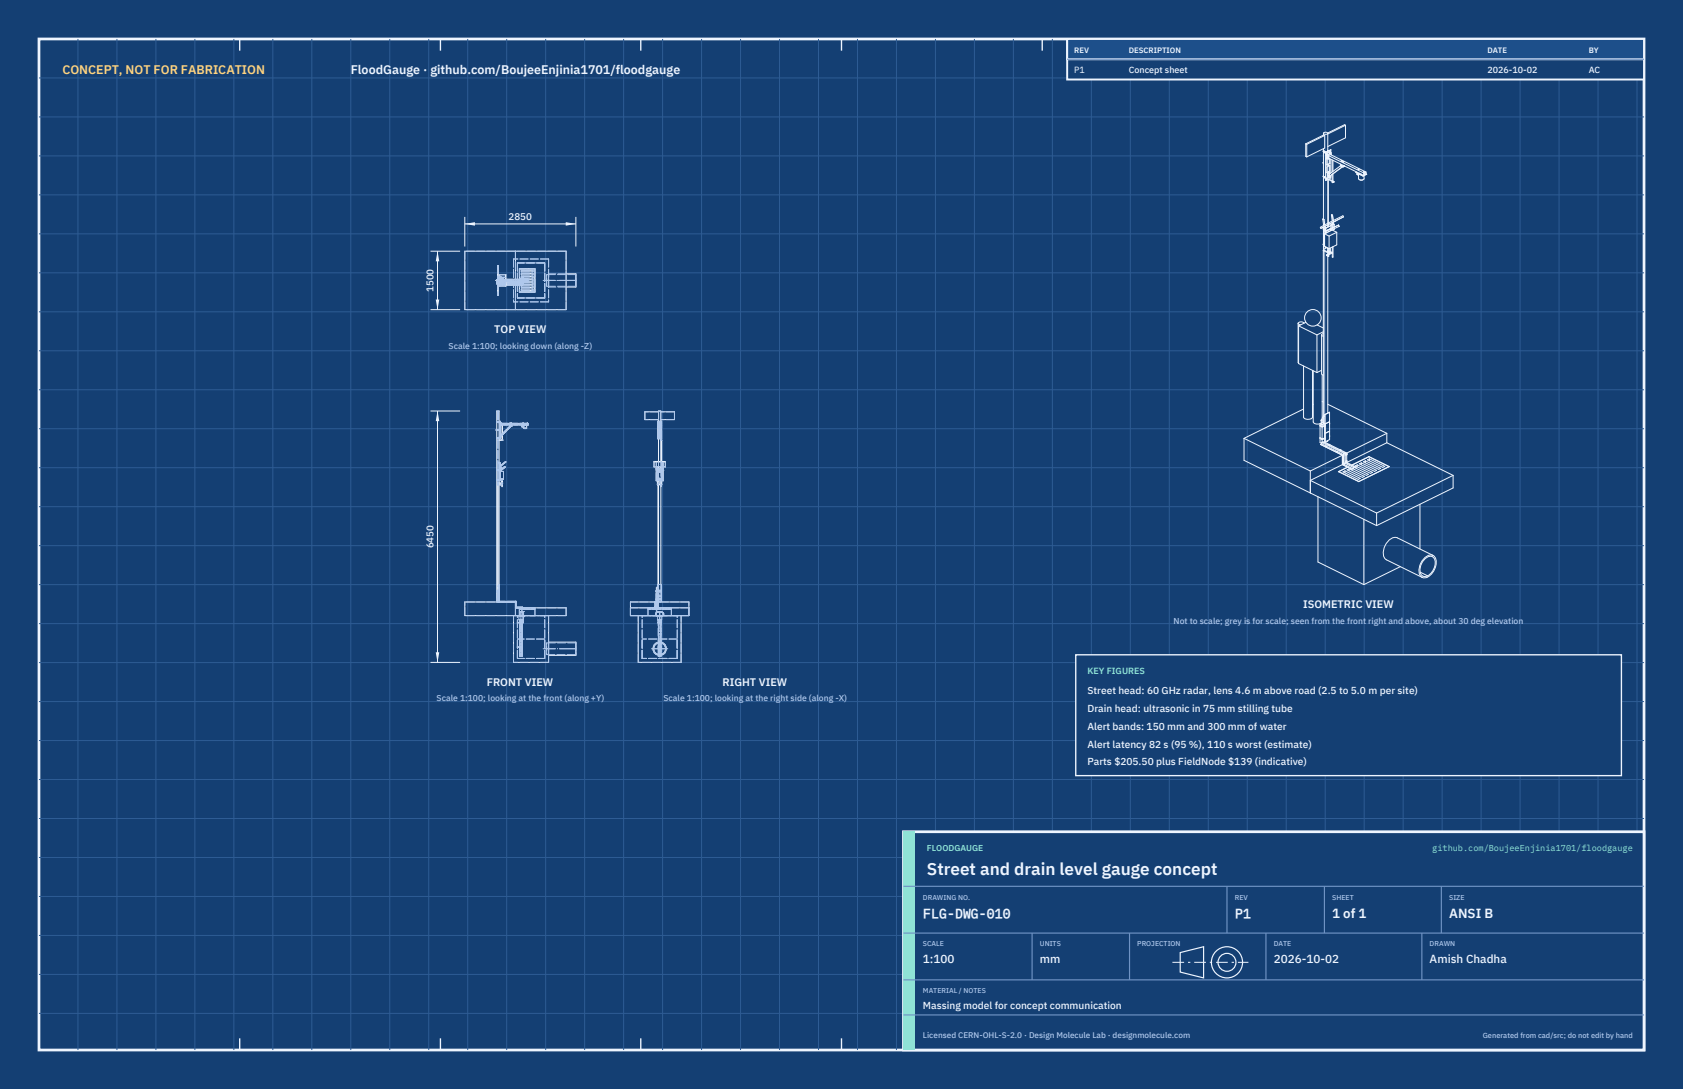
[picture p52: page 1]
CONCEPT, NOT FOR FABRICATION; FloodGauge · github.com/BoujeeEnjinia1701/floodgauge; FRONT VIEW; TOP VIEW; RIGHT VIEW; ISOMETRIC VIEW; REV; DESCRIPTION; DATE; Concept sheet; FLOODGAUGE; github.com/BoujeeEnjinia1701/floodgauge; DRAWING NO. FLG-DWG-010; REV P1; SHEET 1 of 1; SIZE ANSI B; SCALE 1:100; UNITS mm; PROJECTION; DRAWN Amish Chadha; Licensed CERN-OHL-S-2.0 · Design Molecule Lab · designmolecule.com; Generated from cad/src; do not edit by hand

Scale 1:100; looking down (along -Z)

Not to scale; grey is for scale; seen from the front right and above, about 30 deg elevation

KEY FIGURES
Street head: 60 GHz radar, lens 4.6 m above road (2.5 to 5.0 m per site)
Drain head: ultrasonic in 75 mm stilling tube
Alert bands: 150 mm and 300 mm of water
Alert latency 82 s (95 %), 110 s worst (estimate)
Parts $205.50 plus FieldNode $139 (indicative)

Scale 1:100; looking at the front (along +Y)

Scale 1:100; looking at the right side (along -X)

Street and drain level gauge concept

MATERIAL / NOTES
Massing model for concept communication

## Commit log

2026-09-25 Initial scaffold: standard open hardware layout, CERN-OHL-S v2 + MIT licenses
    Claude-Session: https://claude.ai/code/session_01XuhhSU4W6fYhgCfURbrkut
    [bom.csv]
2026-09-26 Populate to TRL 2: problem, requirements, precis, concept media, BOM and README use cases
    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
    [bom.csv]
2026-09-26 Advance to TRL 3: DDR-001, CAL-001 sizing, parametric model with STEP/STL, GA drawing, priced BOM; TRL 4 on hold
    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
    [bom.csv, floodgauge-assembly.step, floodgauge-assembly.stl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]
2026-09-26 Accept all recommendations (DDR-002), switch footer to designmolecule.com, add README write-up with new inspiration point
    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
    [bom.csv, floodgauge-assembly.step, floodgauge-assembly.stl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]
2026-09-26 Strengthen sources, apply approved budgets, add CITATION.cff and CONTRIBUTORS.md with credits
    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
    [results.csv]
2026-09-27 Product appearance model and photoreal renders
    Adds cad/src/product_model.py (appearance model for renders only, all main
    dimensions from model.py) and Blender renders in media/render-*.png,
    captioned with the project, repository and viewing direction. README leads
    with the product render; trl stays 3.
    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
2026-10-01 Image quality pass: legible exploded views, flow diagrams and drawing sheets
    Kit 1.6.1 image layout: the parts list sits in its own column, number bubbles sit on visible parts and never overlap, small parts get a leader, pictures are cropped to the subject, flow labels keep numbers with their units, and sheet captions and the revision table no longer overprint. Concept images, blueprint and general arrangement sheet regenerated; repo-specific labels moved clear of other text and lines.
2026-10-01 Kit 1.7.0: constructable design, illustrated build plan and design decisions register
    The design is now constructable: every part can be made and fits its neighbours, with each change recorded in a Design for construction decision record (made under Amish's 2026-09-30 instruction; ope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
    FlexHand also credits Dr. Geeti Chadha as a contribut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
    [bom.csv, floodgauge-assembly.step, floodgauge-assembly.stl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]
2026-10-02 Record Amish's approval of the open-decision recommendations
    Amish approved the recommendation on every open decision in the design decisions register ("i approve your recommendations for all 555 open decisions.", 2026-10-02). Each decision is moved to Decisio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
2026-10-03 Carry approved follow-ups into the design and redo photoreal renders
    Amish approved the follow-up actions from the open-decision sign-off ("APPROVED CHANGES, COMPLETE THESE", 2026-10-02), the design-for-construction change tables in ten repos, the last wave's open dec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
    [bom.csv, floodgauge-assembly.step, floodgauge-assembly.stl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]
2026-11-01 Kit 1.9.1 upgrade: pipeline documents and detailed CAD for every option
    STEM check with fixes under the standing instruction and an independent
    review, concept options scored against the user requirements, URS, PRS,
    RTM, REG, FEA, RSK, MKT, PLN and DDR, every option modelled at D3 with
    cad/fidelity.json passing, and the concept options picture rendered with
    Blender Cycles on Amish's Mac. Concept choices stay proposed, awaiting
    Amish.
    Claude-Session: https://claude.ai/code/session_01LppsZSzPTJWTBAV5wh1Goq

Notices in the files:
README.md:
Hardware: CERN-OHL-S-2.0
